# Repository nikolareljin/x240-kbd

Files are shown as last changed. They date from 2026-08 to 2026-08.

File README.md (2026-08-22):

# x240-kbd

A standalone USB keyboard with touchpad **and TrackPoint**, built from a ThinkPad X240
keyboard assembly (FRU 0C44020) and its Synaptics ClickPad, driven by a Raspberry Pi Pico
(RP2040) running QMK.

Works on **any OS without drivers** — it enumerates as a standard USB HID composite device
(keyboard + mouse + media keys).

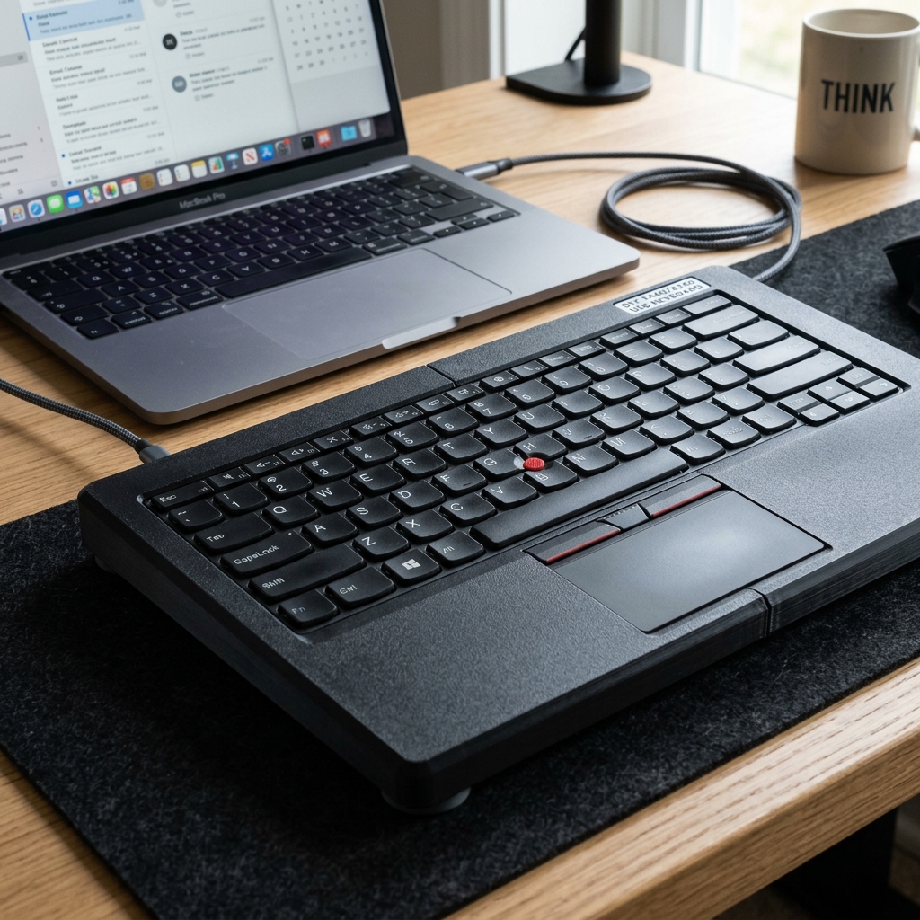
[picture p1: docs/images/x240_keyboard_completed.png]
Standalone X240 Keyboard


> **Project status: design, not yet built.** The matrix pinout is unverified until the
> probing step runs on real hardware, and the TrackPoint route (via the ClickPad's PS/2
> pass-through) is the expected architecture, confirmed by the same step. Everything else
> here is designed to survive either answer. Track progress in the
> [issues](https://github.com/nikolareljin/x240-kbd/issues) — nine milestones from
> documentation to release.

---

## Features

- Full 84-key ThinkPad X240 layout (QWERTY, US)
- Synaptics ClickPad — cursor, left/right click zones
- **TrackPoint** — via the ClickPad's pass-through port, decoded in firmware
- FN layer with the ThinkPad media/system keys; FN Lock (FN + Esc)
- Keyboard backlight, 5 levels (backlit keyboard variants; no breathing — software PWM)
- Power button with a 500 ms long-press guard → OS power/sleep
- Touchpad indicator LED
- N-Key Rollover
- Micro-USB; documented USB-C upgrade
- Two enclosure routes: **3D-printed** (split case) or **hand-made with no printer**
- Two electronics revisions: **Rev A perfboard** and **Rev B KiCad PCB**, same firmware

---

## Hardware at a glance

| Component | Detail |
|---|---|
| Controller | Raspberry Pi Pico, RP2040, 26 GPIO |
| Keyboard | X240 0C44020, 40-pin 0.5 mm FPC; matrix size **measured by probing** |
| Sense expansion | 3 × 74HC165 shift registers — 24 sense lines on 3 GPIO |
| Touchpad + TrackPoint | Synaptics ClickPad, PS/2 on GP21/GP22 (RP2040 PIO driver) |
| Backlight | LED strip via 2N7002/BS170 MOSFET on GP26 |
| Power button | GP27, active LOW |
| USB | Micro-USB; USB-C via the Pico's TP1/TP2/TP3 pads |
| Enclosure | Printed split case, or the original X240 base cover, laser-cut plates, a Hammond console or wood |

Signal flow

Why a shift register: the closest documented ThinkPad keyboard of this era needs 26 matrix
lines — every GPIO the Pico has. [`docs/hardware/gpio-budget.md`](docs/hardware/gpio-budget.md).

### Cost

| Build | All-in (USD, Aug 2026) |
|---|---|
| Rev A + your own printer | **$90–130** |
| Rev A + reused X240 base cover, no printer | **$110–150** |
| Rev B PCB | add $25–35 |

The donor keyboard and palmrest are most of it. Full tiers and part links:
[`docs/hardware/bom-and-cost.md`](docs/hardware/bom-and-cost.md).

---

## Repository structure

```
x240-kbd/
├── firmware/qmk/keyboards/x240_pico/   QMK keyboard definition (corrected in milestone M4)
├── hardware/pinout/                     FPC pin maps — filled by probing
├── hardware/wiring/                     GPIO table (the single authoritative copy) and schematics
├── hardware/pcb/                        Rev B KiCad project (milestone M7)
├── tools/matrix_probe/                  CircuitPython matrix discovery
├── tools/ps2_sniffer/                   CircuitPython PS/2 + Synaptics sniffer
├── cad/                                 OpenSCAD: split case and small printed parts
└── docs/                                The documentation site (GitHub Pages from /docs)
    ├── hardware/                        components, BOM & cost, GPIO budget, sense chain, TrackPoint, backlight, PCB
    ├── firmware/                        architecture, QMK configuration, pointing stack
    ├── enclosure/                       printed, hand-made, integration, durability, presentation
    ├── references.md · glossary.md
    └── images/
```

---

## Quick start

Everything runs through one entry point, `./dev` (verbs from the workspace-wide
[script-helpers](https://github.com/nikolareljin/script-helpers) template; toolchains in
Docker, so the host needs only `docker`, `git` and `python3`):

```bash
./dev install            # submodules, docker images, a shallow qmk_firmware checkout
./dev build [firmware|docs|tools|cad|pcb|all]
./dev test               # host pytest for the tools, link check, shellcheck
./dev preflight          # everything CI runs: test + build all
./dev deploy             # copy the UF2 to the Pico's RPI-RP2 drive  (alias: ./flash)
./dev deploy matrix_probe   # copy a probing tool to CIRCUITPY        (alias: ./probe <tool>)
./dev devices            # RPI-RP2 / CIRCUITPY mounts and serial ports
./dev logs               # qmk console — the firmware's debug output
```

Shims `./build`, `./test`, `./flash`, `./probe`, `./site` wrap the same verbs. Artifacts
land in `out/`. The Docker images and the `qmk_firmware` commit are **pinned by digest**
in `scripts/toolchain.env` (`scripts/pull_toolchain.sh` pulls, saves or refreshes them),
so today's build can be repeated later. CI (`.github/workflows/ci.yml`, via
[ci-helpers](https://github.com/nikolareljin/ci-helpers)) runs `./dev test` and
`./dev build all` on every push and PR.

1. **Read the component reference and buy parts** —
   [`docs/hardware/components.md`](docs/hardware/components.md),
   [`docs/hardware/bom-and-cost.md`](docs/hardware/bom-and-cost.md).
2. **Probe the FPC pinouts — mandatory first step.** Flash CircuitPython, `./probe
   matrix_probe`, then `./probe ps2_sniffer`, following
   [`hardware/pinout/probing_procedure.md`](hardware/pinout/probing_procedure.md). Do not
   wire the Pico to anything before this is done.
3. **Build the Rev A adapter** — [`ASSEMBLY.md`](ASSEMBLY.md) Phase 2, using
   [`hardware/wiring/wiring_diagram.md`](hardware/wiring/wiring_diagram.md).
4. **Build and flash firmware** — `./dev build` then `./dev deploy` (hold BOOTSEL while
   plugging in). Without `./dev`: copy `firmware/qmk/keyboards/x240_pico` into a QMK
   checkout and `qmk compile -kb x240_pico -km default`. The firmware **builds** (custom
   74HC165 matrix, PIO PS/2 host, Synaptics + TrackPoint decoding); the key map is a
   placeholder until probing (#38). [`docs/firmware/qmk-configuration.md`](docs/firmware/qmk-configuration.md).
5. **Choose an enclosure** — printed:
   [`docs/enclosure/printed.md`](docs/enclosure/printed.md); no printer:
   [`docs/enclosure/handmade.md`](docs/enclosure/handmade.md).
6. **Close it up** — [`docs/enclosure/presentation.md`](docs/enclosure/presentation.md)
   has the assembly order.

---

## FN key map

| FN + | Action | | FN + | Action |
|---|---|---|---|---|
| F1 | Mute | | F9 | Settings |
| F2 | Volume down | | F10 | Bluetooth |
| F3 | Volume up | | F11 | **Backlight step** |
| F4 | Mic mute (F20) | | F12 | Print Screen |
| F5 | Brightness down | | PgUp / PgDn | Home / End |
| F6 | Brightness up | | Left / Right | Previous / next track |
| F7 | External display | | Esc | **FN Lock** |
| F8 | Wireless toggle | | | |

---

## USB-C upgrade (optional)

Wire a USB-C female breakout (one with 5.1 kΩ CC pull-downs) to the pads on the Pico's
underside:

| Pico pad | Signal | Breakout |
|---|---|---|
| **TP1** | **GND** | GND |
| **TP2** | **USB D−** | D− |
| **TP3** | **USB D+** | D+ |
| VBUS (pin 40) | 5 V | VBUS |

Set `usb_c = true` in `cad/bottom_case.scad` for the USB-C cutout. No firmware change.

USB-C breakout to Pico test pads

> The illustration [`docs/images/usb_c_wiring.png`](docs/images/usb_c_wiring.png) is
> decorative; its pad labels predate this table and are **not** the wiring reference.
> Source: [Pico datasheet, test points](https://datasheets.raspberrypi.com/pico/pico-datasheet.pdf).

Alternatively use a **Pimoroni Pico LiPo** (USB-C native, same pinout).

---

## Flashing

- **First flash:** hold BOOTSEL while plugging in → `RPI-RP2` drive → drag the `.uf2`.
- **After that:** `./dev deploy`, or hold the top-left key (Esc) while plugging in (Bootmagic).
- **Recommended:** wire a tactile switch to the Pico's `RUN` pad, reachable through the
  case, so BOOTSEL + reset works without opening anything.

---

## Documentation

The site is built from `docs/` (GitHub Pages, milestone M1). Start at
[`docs/README.md`](docs/README.md). Builder guides: [`ASSEMBLY.md`](ASSEMBLY.md),
[`PLAN.md`](PLAN.md). Changes: [`CHANGELOG.md`](CHANGELOG.md).

## References

Annotated list in [`docs/references.md`](docs/references.md). The projects this one stands
on: [delingren/thinkpad_keyboards](https://github.com/delingren/thinkpad_keyboards),
[hamishcoleman/thinkpad-usbkb](https://github.com/hamishcoleman/thinkpad-usbkb),
[thedalles77/USB_Laptop_Keyboard_Controller](https://github.com/thedalles77/USB_Laptop_Keyboard_Controller).

## Repository

[nikolareljin/x240-kbd](https://github.com/nikolareljin/x240-kbd) · GPL-2.0, matching QMK.

## Clone traffic

Clone traffic

_Updated daily. Total and unique cloners over the last 14 days._

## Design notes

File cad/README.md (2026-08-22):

# Printed parts

Parametric OpenSCAD. Every dimension lives in [`params.scad`](params.scad); part files
only include it. Values marked `MEASURE` there are targets until a real X240 deck is
measured (issue #44).

| Part | File | Variants | Qty |
|---|---|---|---|
| Bottom case, split | `bottom_case.scad` | `half="left"`, `"right"`, `"both"` | 1 + 1 |
| Perfboard / PCB sled | `perfboard_sled.scad` | | 1 |
| USB strain relief (two clamp halves) | `usb_strain_relief.scad` | | 1 set |
| Tilt feet (pair) | `tilt_feet.scad` | | 1 set |
| ZIF support block | `zif_support_block.scad` | `variant="keyboard"`, `"clickpad"` | 1 each |
| LED light pipe | `led_light_pipe.scad` | | 1 |
| Pico mount bracket (Rev A) | `pico_mount_bracket.scad` | | 1 |
| FPC cable guide | `fpc_cable_guide.scad` | `cable="keyboard"`, `"clickpad"` | 2 + 1 |
| **Laser-cut plates + box insert (2D → DXF)** | `export_plates.scad` | `plate="bottom"`, `"spacer"`, `"insert"`, `"sheet"` | see [`../docs/enclosure/handmade.md`](../docs/enclosure/handmade.md) |

Render everything: `./dev build cad` → `out/cad/*.stl` and `*.dxf` (OpenSCAD in Docker; no
install needed). The DXFs come from `projection()` of the same solids, so the hand-made
route cannot drift from the printed one. Single part by hand: `openscad -D 'half="right"' -o right.stl bottom_case.scad`.

Settings, tolerances, joint design and assembly order:
[`../docs/enclosure/printed.md`](../docs/enclosure/printed.md). Meshes are never committed
(`out/` and `cad/exports/` are ignored).

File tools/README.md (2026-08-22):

# Probing and bring-up tools

CircuitPython scripts that run on the Raspberry Pi Pico **before** QMK is flashed. Each is
standalone: `./probe <tool>` copies it to the `CIRCUITPY` drive as `code.py` (or do it by
hand), open a serial terminal at 115200 baud, and edit the constants at the top of the
file to match your wiring.

| Tool | Milestone step | Edit first |
|---|---|---|
| [`matrix_probe/matrix_probe.py`](matrix_probe/matrix_probe.py) | Keyboard FPC: which pads are drive, which are sense, per key | `PASS` (`"A"` pads 1–26, `"B"` pads 15–40), `NEVER_DRIVE_PADS` once VCC/GND/backlight are known |
| [`ps2_sniffer/ps2_sniffer.py`](ps2_sniffer/ps2_sniffer.py) | ClickPad FPC: find CLK/DATA, then the **TrackPoint verdict** | `MODE` (`"find"` → `"synaptics"`), `CANDIDATE_PAIRS`, then `CLK_PIN`/`DATA_PIN` |
| [`shift_register_test/shift_register_test.py`](shift_register_test/shift_register_test.py) | Verify the 74HC165 chain with nothing else connected | `MODE` (`"watch"` or `"walk"`) |

Order of use: `shift_register_test` (walk mode, on the bare adapter) → `matrix_probe`
pass A → pass B → `ps2_sniffer` find → `ps2_sniffer` synaptics. Results go into
[`../hardware/pinout/`](../hardware/pinout/).

Full procedure: [`../hardware/pinout/probing_procedure.md`](../hardware/pinout/probing_procedure.md).

## Host-side tests

The protocol and table-formatting logic in each script is plain Python with no hardware
imports, so it is unit-tested on a PC:

```bash
./dev test            # or: cd tools/tests && python3 -m pytest -q
```

Covers the two-pass pad maps and result merging, PS/2 parity and packet decoding, the
Synaptics special-command encoding, 6-byte absolute packets including `W == 3` guest
frames, the capability bits, the verdict text, and the 74HC165 bit-to-sense-line mapping.
The hardware sections are skipped on the host (`ON_DEVICE` is `False`).

## Timing caveat

CircuitPython bit-bangs at tens of microseconds per GPIO operation; PS/2 clocks at
10–16 kHz. Reads are marginal and framing errors are normal — the scripts resync and
only need a handful of good bytes. If nothing decodes, put a logic analyser on the
candidate pins first ([`../docs/hardware/components.md`](../docs/hardware/components.md)).

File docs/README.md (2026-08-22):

---
title: Documentation index
nav_exclude: true
---

# x240-kbd documentation

Builder-facing pages are grouped by subject; maintainer rules are at the bottom. The same
files are served as the GitHub Pages site (milestone M1).

## Hardware

- [`hardware/components.md`](hardware/components.md) — every part with datasheet and product links
- [`hardware/bom-and-cost.md`](hardware/bom-and-cost.md) — tiered BOM and all-in cost
- [`hardware/gpio-budget.md`](hardware/gpio-budget.md) — why a Pico needs a shift register here
- [`hardware/shift-register-matrix.md`](hardware/shift-register-matrix.md) — the 74HC165 sense chain
- [`hardware/trackpoint.md`](hardware/trackpoint.md) — TrackPoint via Synaptics pass-through
- [`hardware/backlight.md`](hardware/backlight.md) — MOSFET circuit and the RP2040 driver choice
- [`hardware/pcb.md`](hardware/pcb.md) — Rev A perfboard vs Rev B PCB

## Firmware

- [`firmware/architecture.md`](firmware/architecture.md) — file map and data paths
- [`firmware/qmk-configuration.md`](firmware/qmk-configuration.md) — every flag, with corrections
- [`firmware/pointing-stack.md`](firmware/pointing-stack.md) — ClickPad + TrackPoint decoding

## Enclosure

- [`enclosure/printed.md`](enclosure/printed.md) — split case and the small printed parts
- [`enclosure/handmade.md`](enclosure/handmade.md) — no printer: base cover, laser-cut, console, wood
- [`enclosure/integration.md`](enclosure/integration.md) — stack heights, routing, screws
- [`enclosure/durability.md`](enclosure/durability.md) — heat, EMI, FPC fatigue, stiffness
- [`enclosure/presentation.md`](enclosure/presentation.md) — assembly order, box, label, card

## Reference

- [`references.md`](references.md) — annotated sources
- [`glossary.md`](glossary.md)

## Maintainer rules (not published on the site)

- [`project-structure.md`](project-structure.md) — where things live
- [`design-instructions.md`](design-instructions.md) — design contract
- [`code-instructions.md`](code-instructions.md) — coding standards
- [`build-and-test.md`](build-and-test.md) — workflow from raw hardware to verified device

## Source of truth

1. Measured data in `hardware/pinout/*.md`
2. The GPIO table in `hardware/wiring/wiring_diagram.md`
3. QMK source under `firmware/`
4. `ASSEMBLY.md`, then `PLAN.md`

If documents disagree, the earlier item wins and the later one has a bug.

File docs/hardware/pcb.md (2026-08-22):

---
title: PCB (Rev B)
parent: Hardware
nav_order: 7
---

# Rev A and Rev B

| | Rev A — perfboard | Rev B — PCB |
|---|---|---|
| Carrier | Stripboard ≈100 × 80 mm, 30 AWG wire | 2-layer KiCad board, same outline |
| FPC sockets | Off-the-shelf ZIF breakouts soldered to the stripboard | Hirose FH12 directly on the board |
| Shift registers | DIP-16 in sockets | SSOP/TSSOP |
| Pull-ups | 9-pin SIP networks | 4 × 0603 arrays |
| Pico | Socketed on 2 × 20 female headers | Same — socketed, replaceable |
| Mounting | M2 holes drilled to match the sled | M2 holes on the **same pattern**, plus holes matching the X240 base-cover standoffs |
| Firmware | identical | identical |
| GPIO map | identical | identical |

Rev B is a **drop-in**: same connector positions, same holes, same firmware. A Rev A build
can be upgraded by swapping the board. That constraint is deliberate — it keeps one set of
docs, one enclosure design and one firmware.

## Rev B is jumpered, not hard-routed — and why

Which of the keyboard FPC's 40 lines are drive, sense, VCC, GND, backlight and power
button is unknown until probing (#28); the ClickPad's pin count until #29. A board that
hard-routes FPC pins to GPIO before that would be wrong on arrival. So **Rev B** gets the
parts that are certain — the ZIF connectors, the 74HC165 chain with its pull-up arrays,
the PS/2 pull-ups, the backlight MOSFET, decoupling, the Pico socket — and brings the
unknowns to headers that sit side by side:

| Header | Carries | Jumper to |
|---|---|---|
| `J_KB` 2 × 20 | keyboard FPC lines 1–40, one per pin | `J_MAT` |
| `J_MAT` 2 × 17 | DRV0–9 (GP0–GP9), SENSE0–19 (chain inputs), BL−, BL+, PWR_BTN, GND | `J_KB` |
| `J_TP` 1 × 12 | ClickPad FPC lines 1–12 | `J_PS2` |
| `J_PS2` 1 × 8 | 3V3, GND, PS2_DATA (GP21, pulled up), PS2_CLK (GP22), fallback DATA/CLK (GP19/20, DNP pull-ups), LED_A, GND | `J_TP` |

After probing, ~30 short jumper wires (or a tiny "personality" board plugged across both
headers) make the assignment. Sense lines 20–23 are pulled up but not headered in this
revision: the documented ThinkPad matrices need ≤ 20 sense lines, and `J_MAT` is already
34 pins. A Rev C hard-routes the measured map and deletes the headers.

## Rev B schematic blocks

1. **Pico module** — 2 × 20 header footprint, USB at the rear edge, `RUN` broken out to a
   tactile reset button, `TP1/TP2/TP3` broken out to a 4-pin USB-C header.
2. **Keyboard FPC** — `FH12-40S-0.5SH(55)`, bottom contact, on the edge facing the deck.
   All 40 lines go to `J_KB`; every pin is probeable there after assembly.
3. **Sense chain** — 3 × 74HC165, `PL`/`CP` bussed, `Q7 → DS` cascade, 100 nF each, three
   4 × 10 kΩ arrays per chip (12 elements per chip; 8 used, spares tied off).
4. **ClickPad FPC** — `FH12-12S-0.5SH(55)` as the placeholder (a 12-pin socket accepts
   narrower cables if you align pin 1; confirm after #29). All lines go to `J_TP`.
5. **PS/2** — 4.7 kΩ pull-ups on DATA (GP21) and CLK (GP22). Second pair on GP19/GP20 with
   unpopulated pull-ups, for the TrackPoint fallback.
6. **Backlight** — 2N7002, 10 kΩ gate, 100 kΩ pull-down, series resistor footprint, jumper
   selecting 3V3 or VBUS for the anode.
7. **Power button / LED** — GP27 with ESD-friendly 100 Ω series; GP28 → 100 Ω → LED header.
8. **Decoupling and bulk** — 10 µF near the Pico's 3V3 pin, 100 nF per IC.

## Rules and what the generated board is

- 2-layer, 100 × 80 mm. Netclass targets 0.20 mm track / 0.15 mm clearance, vias
  0.6 / 0.3 mm; board minimums 0.127 mm (JLCPCB/PCBWay 2-layer capability). The router is
  given that room deliberately — at 0.25 / 0.18 it left FPC lines unrouted.
- Freerouting routes **all 202 connections** (0 unrouted) in about three minutes at 100
  passes. The back-side GND pour is added afterwards with island removal on, so it only
  adds copper; every connection is the router's.
- `kicad-cli pcb drc` on the routed board: no errors, no unconnected items. The only
  warnings are a few dangling vias — router GND vias whose pour-side copper was removed as
  an island; harmless, and a later revision can delete them.
- Mounting: four M2 holes on the sled pattern (4 mm in from each corner) and three M2.5
  holes for the X240 base-cover standoffs at **placeholder** positions (`MEASURE` — issue
  #44 fixes them).

## Ordering

- **JLCPCB / PCBWay**: 2-layer, 1.6 mm FR-4, HASL or ENIG (ENIG recommended for the 0.5 mm
  FPC pads), 5 boards ≈ $2 plus shipping. Allow 1–2 weeks.
- Order the Hirose connectors and the SMD parts from **DigiKey/Mouser** or, cheaper, from
  **LCSC** in the same basket as a JLCPCB order.
- `out/pcb/bom.csv` (from `kicad-cli sch export bom`, grouped by value and footprint) is
  the parts list to order from; add LCSC/DigiKey numbers in the basket. An interactive
  HTML BOM is not produced — InteractiveHtmlBom is not in the pinned KiCad image.

## How the files are made

The board is **generated**, not drawn: `hardware/pcb/netlist_model.py` holds the parts,
library names and nets; `gen_schematic.py` writes the `.kicad_sch` and `gen_pcb.py` the
`.kicad_pcb` from it, so the two cannot disagree. Routing is done by freerouting from a
Specctra DSN exported by KiCad's Python API, then imported back; DRC, PDF, gerbers and
drill files come from `kicad-cli`. All of that runs in the pinned `kicad/kicad` and
`freerouting` images via `./dev build pcb`. Edit the model, not the KiCad files.

## Deliverables of milestone M7

- `hardware/pcb/x240_pico_rev_b.kicad_pro` + schematic + PCB (generated, committed)
- `out/pcb/schematic.pdf`, `board.pdf`, `gerbers.zip` + drill, position file, `bom.csv`
- This page updated with the real ordering parameters and a bring-up log.

Assembly with a soldering iron is realistic: the hardest parts are the FH12 connectors
(0.5 mm pitch — flux, drag-solder, magnification) and the SSOP shift registers. Everything
else is 0603 or larger.

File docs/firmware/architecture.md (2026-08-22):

---
title: Architecture
parent: Firmware
nav_order: 1
---

# Firmware architecture

QMK keyboard definition under `firmware/qmk/keyboards/x240_pico/`, built by copying it
into a QMK checkout. Files marked **new** are created in milestone M4; the rest exist today
and are corrected there.

| File | Owns | Status |
|---|---|---|
| `keyboard.json` | USB IDs, `processor`/`bootloader`, feature flags, the `ps2` block, layout metadata. `matrix_pins` is **removed** — the custom matrix owns pins. | exists, corrected in M4 |
| `config.h` | Sense chain (`SENSE_PL_PIN`, `SENSE_CHAIN_BYTES`, `SENSE_SPI_DIVISOR`), SPI0 pins (`SPI_DRIVER`, `SPI_SCK_PIN`, `SPI_MISO_PIN`, `SPI_MOSI_PIN`), `MATRIX_DRIVE_PINS`, debounce, backlight, power button, LED, `SYN_*` tuning | exists, corrected in M4 |
| `rules.mk` | `CUSTOM_MATRIX = lite`, `POINTING_DEVICE_DRIVER = custom`, `PS2_ENABLE = yes` + `PS2_DRIVER = vendor`, `PS2_MOUSE_ENABLE = no`, `BACKLIGHT_DRIVER = software`, `SRC += matrix.c synaptics.c trackpoint.c` | corrected in M4 |
| `halconf.h` / `mcuconf.h` | `HAL_USE_SPI`, `RP_SPI_USE_SPI0` — ChibiOS needs SPI0 switched on for the sense chain | **new** |
| `matrix.c` | Drive-line sequencing and the 74HC165 chain read | **new** |
| `synaptics.c` / `.h` | The custom pointing-device driver: ClickPad reset/identify/capabilities, mode byte, guest enable, 6-byte packet parser with resync, touchpad delta, logged relative-mode fallback | **new** |
| `trackpoint.c` / `.h` | Guest (pass-through) frame decode, TrackPoint delta and scaling | **new** |
| `x240_pico.c` | `keyboard_post_init_kb` (LED on, power-button pull-up), `matrix_scan_kb` (power-button long-press guard), `pointing_device_task_kb` (pass-through; merge happens in `synaptics.c`) | exists |
| `x240_pico.h` | `LAYOUT` macro, custom keycodes `CK_BKLT`/`CK_FNLK`, layer enum | exists; `LAYOUT` regenerated from the measured matrix |
| `keymaps/default/keymap.c` | `_BASE` and `_FN` layers, `process_record_user` | exists; regenerated from the measured matrix |

Signal flow

## From a key press to a USB report

```
GP0..GP9 drive line LOW
   → membrane closes a sense line to it
      → 74HC165 latches 24 sense bits (PL)
         → SPI0 clocks them into GP16          matrix.c : matrix_scan_custom()
            → raw row bitmap
               → QMK debounce (DEBOUNCE 5 ms)   quantum/
                  → keymap lookup, layers        keymap.c
                     → NKRO / boot keyboard report over USB (TinyUSB)
```

## From the ClickPad to a USB mouse report

```
ClickPad + TrackPoint guest  ──PS/2──►  GP21 DATA / GP22 CLK
   → QMK vendor PS/2 driver (RP2040 PIO0)         platforms/chibios/drivers/vendor/RP/RP2040/ps2_vendor.c
      → pbuf_has_data() / ps2_host_recv() bytes
         → synaptics.c (custom pointing driver) assembles 6-byte packets
            ├─ W != 3 : touchpad frame  → finger delta, L/R from byte 0    synaptics.c
            └─ W == 3 : guest frame     → TrackPoint 3-byte packet          trackpoint.c
               → both add into one report_mouse_t inside                    synaptics.c
                 pointing_device_driver_get_report()
                  → pointing_device_task_kb() passes it through              x240_pico.c
                  → USB HID mouse report
```

If the Synaptics identify fails, `synaptics.c` falls back to plain relative mode and logs
once via `dprintf` — the touchpad still works, the TrackPoint does not, and the log says so.
Never a silent success.

## Hooks used and why

| Hook | Used for | Not used for |
|---|---|---|
| `matrix_init_custom` / `matrix_scan_custom` | the chain | anything else — keep the scan loop minimal |
| `keyboard_post_init_kb` | LED and power-button GPIO setup | keymap logic |
| `pointing_device_driver_init` | Synaptics init; failures logged on the console | matrix |
| `matrix_scan_kb` | power-button timing only | side effects on the matrix |
| `pointing_device_task_kb` | pass-through only (merge and Y inversion happen in the driver) | pointing logic |
| `process_record_user` | `CK_BKLT`, `CK_FNLK` | hardware polling |

## Build

```bash
cp -r firmware/qmk/keyboards/x240_pico ~/qmk_firmware/keyboards/x240_pico
qmk compile -kb x240_pico -km default
qmk flash   -kb x240_pico -km default     # hold BOOTSEL, or Bootmagic top-left key
```

Local build without installing a toolchain: the `qmkfm/qmk_cli` docker image plus a
`qmk_firmware` checkout, with this directory mounted at `keyboards/x240_pico`. The
placeholder `LAYOUT` still describes the old 8 × 13 arrangement inside the 10 × 24 matrix;
issue #38 regenerates it from the measured pinout.

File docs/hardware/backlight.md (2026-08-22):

---
title: Backlight
parent: Hardware
nav_order: 6
---

# Keyboard backlight

Only the backlit keyboard variants (`04X0177`, `0C43982`) have an LED strip. The
non-backlit `0C44020` has none — on that keyboard the circuit below is simply left
unpopulated and `BACKLIGHT_ENABLE = no`.

## Circuit

Backlight MOSFET switch

A low-side N-MOSFET switch on GP26. The Pico cannot source the strip's current directly
(GPIO limit ~12 mA; the strip is ~100 mA on comparable ThinkPad arrays).

```
3V3 ──── R_series ──── LED strip anode (+)
                        LED strip cathode (−) ──── Drain
                                                   Source ──── GND
GP26 ──── 10 kΩ ──── Gate
                     Gate ──── 100 kΩ ──── GND
```

| Part | Value | Why |
|---|---|---|
| Q1 | 2N7002 (SOT-23) or BS170 (TO-92) | Logic-level V<sub>GS(th)</sub>, turns on fully at 3.3 V |
| R<sub>gate</sub> | 10 kΩ | Limits the gate-charge current spike on each PWM edge |
| R<sub>pd</sub> | 100 kΩ gate → GND | Holds the gate LOW while the Pico boots and GP26 is high-Z: **the backlight does not flash at power-on** |
| R<sub>series</sub> | 100 Ω to start — **set by measurement** | The strip has its own internal resistors on most ThinkPads; measure before trusting any value |
| Supply | 3V3 from the Pico | If the strip is dim at 3.3 V, move the anode to VBUS (5 V) and re-measure current |

## Measure before you trust it

1. Identify the backlight anode/cathode pins on the keyboard FPC (Phase 1).
2. With the MOSFET **not** fitted, put a multimeter in series and apply 3.3 V through 100 Ω.
3. Note the current. Expect tens of mA; delingren measured ~5.6 mA per LED × 18 LEDs ≈
   100 mA on a 04Y0819 with no series resistor.
4. If it is under ~20 mA and visibly dim, reduce R<sub>series</sub> or move to 5 V.
   If it is over ~150 mA, raise R<sub>series</sub>. The USB budget is 500 mA total; keep
   the backlight under a third of that.
5. Record the final values in this file.

## QMK driver selection

This is where the earlier plan was wrong.

| Driver | What it is | RP2040? |
|---|---|---|
| `pwm` | Hardware PWM via ChibiOS `PWMD` | **Fails to compile on RP2040** — [QMK #24470](https://github.com/qmk/qmk_firmware/issues/24470): `unknown type name 'PWMConfig'`, undeclared `PWMD4` |
| `timer` | Interrupt-driven pin toggling | Documented for **AVR and STM32**; not the RP2040 workaround |
| `software` | PWM emulated in the main loop | **Works on RP2040** — the workaround recorded in #24470 |
| `custom` | You write it | Unnecessary here |

So: `BACKLIGHT_DRIVER = software`. The cost is some flicker sensitivity if the scan loop
stalls; at our ~350 µs scan this is invisible. If a later QMK release fixes RP2040 `pwm`,
switch and record it in `CHANGELOG.md`.

Reference: [QMK backlight docs](https://docs.qmk.fm/features/backlight).

## Configuration

```c
/* config.h */
#define BACKLIGHT_PIN     GP26
#define BACKLIGHT_LEVELS  5
/* no BACKLIGHT_BREATHING — unsupported by the software driver */
```

```make
# rules.mk
BACKLIGHT_ENABLE = yes
BACKLIGHT_DRIVER = software
```

FN + F11 (`CK_BKLT`) steps through the five levels. **No breathing**: `backlight_software.c`
refuses `BACKLIGHT_BREATHING` at compile time, so it is not defined.

## Troubleshooting

| Symptom | Cause |
|---|---|
| Always off | Gate/drain/source mixed up (TO-92 pinout varies by manufacturer — check the datasheet, not the package shape) |
| Always on, even before firmware | Missing 100 kΩ pull-down |
| On but no dimming | Driver is not `software`, or `BACKLIGHT_LEVELS` is 1 |
| Dim | R<sub>series</sub> too high for 3.3 V — measure, then consider 5 V |

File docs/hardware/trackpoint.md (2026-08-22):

---
title: TrackPoint
parent: Hardware
nav_order: 5
---

# TrackPoint architecture

The X240 keyboard has a TrackPoint. Earlier revisions of this project did not mention it.
It is a first-class feature: the finished keyboard must move the cursor from the stick and
click from the ClickPad's button zones.

## How the X240 routes the TrackPoint

PS/2 bus with TrackPoint pass-through

In this generation of ThinkPads the TrackPoint does **not** have its own line to the host.
The stick's strain-gauge board feeds a controller (TPM754-class) that speaks PS/2, and that
PS/2 stream goes into the **Synaptics ClickPad's guest port**. The ClickPad forwards the
guest's packets to the host inside its own packet stream. Linux shows this as
`serio: Synaptics pass-through port` at boot.

```
TrackPoint strain gauges
   → TrackPoint controller  (PS/2 out, inside the keyboard)
      → ClickPad Synaptics guest port  (inside the palmrest)
         → ONE PS/2 bus  →  Pico GP21 (DATA) / GP22 (CLK)
```

Consequence: **no extra wires or pins**. The Pico sees one PS/2 device. Everything else is
firmware.

This is the *expected* chain. It is confirmed by the M2 ClickPad probing step — the extended
sniffer reports whether pass-through frames appear when the stick is pushed. Do not wire
for the fallback until that measurement says so.

## What QMK does and does not do

QMK's `ps2_mouse` feature speaks **plain PS/2 relative mode**: 3-byte packets, X/Y deltas,
three buttons. In that mode a Synaptics ClickPad behaves like an ordinary PS/2 mouse and
**silently drops** the guest stream — the TrackPoint is dead.

So the firmware does not use `ps2_mouse` at all. It keeps QMK's RP2040 PIO PS/2 *host*
(`PS2_ENABLE = yes`, `PS2_DRIVER = vendor`) and implements the pointing device itself
(`POINTING_DEVICE_DRIVER = custom`): put the ClickPad into Synaptics **absolute mode with
pass-through enabled**, then decode the 6-byte packets. That is `synaptics.c` /
`trackpoint.c` — [`../firmware/pointing-stack.md`](../firmware/pointing-stack.md).

## The Synaptics protocol, briefly

Spec: Synaptics *TouchPad Interfacing Guide* (PN 511-000275; no longer hosted publicly — the working reference is the Linux driver [`drivers/input/mouse/synaptics.c`](https://github.com/torvalds/linux/blob/master/drivers/input/mouse/synaptics.c)).
The Linux `psmouse` driver (`drivers/input/mouse/synaptics.c`) is the working reference
implementation.

**Identify ("magic knock").** Send `SetResolution` four times with the value encoding a
query number, then `StatusRequest` (`0xE9`); the three status bytes carry the answer. Query
`0x00` returns identification — byte 1 must be `0x47` for a Synaptics device.

**Mode byte.** Written with the same knock followed by `SetSampleRate 0x14`. Bits we set:
`Absolute` (bit 7), `Rate 80` (bit 6), `W-mode` (bit 0). Pass-through is enabled per the
guide's "extended capabilities" sequence when capability bit `PassThrough` is present.

**Absolute packet (6 bytes).**

```
byte 0: 1 0 W3 W2 0 W1 R L
byte 1: Y11 Y10 Y9 Y8 X11 X10 X9 X8
byte 2: Z7..Z0
byte 3: 1 1 Y12 X12 0 W0 R' L'
byte 4: X7..X0
byte 5: Y7..Y0
```

`W` (four bits) is the finger-width / packet-type field. **`W == 3` means this packet is a
pass-through frame**: bytes 1, 4 and 5 hold the guest device's standard 3-byte PS/2 packet
(buttons/sign byte, X delta, Y delta). Everything else is touchpad data.

So the decoder is one `switch` on `W`: guest frame → TrackPoint path; anything else →
touchpad path.

## Fallback: a standalone TrackPoint line

If the sniffer never sees `W == 3` frames with the stick deflected, the TrackPoint is not on
the ClickPad's guest port on this unit. Then:

- Find the TrackPoint controller's own CLK/DATA on the keyboard FPC (it will be two of the
  non-matrix pins), with 4.7 kΩ pull-ups.
- Wire them to the reserved pair **GP19 (DATA) / GP20 (CLK)**.
- Run a second PS/2 instance on PIO1 (`#define PS2_PIO_USE_PIO1`) — QMK's vendor driver
  uses PIO0 by default.
- A standalone controller may need its **reset pin pulsed high at boot**; delingren found a
  04Y0819 module failed ~90 % of the time without it. Probe for a reset line if the module
  is unreliable.

This path costs 2 GPIO and a second driver instance. It is documented so that the pins are
already reserved; it is not built until a measurement demands it.

## Buttons

The X240 ClickPad has no separate physical buttons; its top edge is a button zone for the
TrackPoint and its bottom corners are the touchpad's click zones. Those clicks arrive in the
**touchpad** packet's L/R bits, not in the guest frame. The firmware merges them: a click
while the last motion came from the stick is a TrackPoint click in practice, and the user
will not notice the distinction.

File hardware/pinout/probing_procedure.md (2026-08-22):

# FPC Pinout Probing Procedure

This document explains how to discover the exact function of every pin on the X240
keyboard and touchpad FPC cables before wiring them to the Pico.

---

## Equipment

- Raspberry Pi Pico (flashed with CircuitPython) — the *same* Pico is reused for the build
- 40-pin 0.5 mm FPC-to-DIP breakout **with a ZIF connector** (see `docs/hardware/components.md`; Adafruit #1436 is a bare solder-pad plate, not a ZIF breakout)
- 6–12 pin 0.5 mm ZIF FPC breakout board (for touchpad)
- Multimeter (continuity + DC voltage modes)
- Logic analyser (cheap 8-channel USB type works fine) — for touchpad PS/2 sniffing
- Serial terminal (Thonny IDE, PuTTY, or screen — 115200 baud)
- `tools/matrix_probe/matrix_probe.py` (copy to Pico as `code.py`)
- `tools/ps2_sniffer/ps2_sniffer.py` (copy to Pico as `code.py` for touchpad phase)

---

## Part A — Keyboard Matrix

### A1. Insert FPC cable

FPC orientation and pin 1

1. Lift the ZIF locking lever on the breakout board.
2. Slide the keyboard FPC ribbon into the connector.
   - Most FPC breakouts require the contact pads (shiny metal) to face down.
   - Check your specific breakout board's silkscreen or datasheet.
3. Close the locking lever firmly.

### A2. Flash CircuitPython and run matrix_probe

1. Hold BOOTSEL while plugging Pico into USB → appears as `RPI-RP2`.
2. Drag the CircuitPython `.uf2` from circuitpython.org onto the drive.
3. Pico reboots as `CIRCUITPY`.
4. Copy `tools/matrix_probe/matrix_probe.py` onto `CIRCUITPY`, rename to `code.py`.
5. Open a serial terminal at 115200 baud (Thonny serial console works well).

The 40-pad breakout has more pads than the Pico has GPIO (26). The script runs in
**two passes**: wire pads 1–26 for pass A, then pads 15–40 for pass B (the overlap ties the
two maps together). Set `PASS = "A"` or `"B"` at the top of the script; `GPIO_ORDER` lists
the 26 GPIO in the order they are wired to the pads. As soon as a pad is known to be VCC,
GND or backlight, add it to `NEVER_DRIVE_PADS` so it is never pulled LOW.

The script will:
- Iterate through the wired pads
- Drive each pin LOW while configuring all other pins as inputs with pull-ups
- Display: `Press a key... ` and wait
- When you press a key, it prints the drive pad and the sense pad that closed together
- At the end it prints a Markdown table (key, drive pad, sense pad, pass) — paste it into
  `x240_keyboard_fpc_pinout.md` — and a drive/sense summary

Work through every key on the keyboard. Keys that share a row will produce the same
first pin number; keys in the same column share the second pin number.

### A3. Build the drive/sense map

After scanning all keys, group the results:

- **Drive lines**: the set of pads that appear as the "driven" pad across multiple keys
- **Sense lines**: the remaining active pads

Count them. The smaller set goes to GP0–GP9 as drive lines; the larger set goes to the
74HC165 chain as sense lines. If both are ≤ 10 you could skip the chain — but keep it; it
is what makes the design survive a transposed or larger-than-expected matrix.

### A3b. Ghosting test

Hold A + S + D. If a fourth key appears, the membrane has no diodes and every sense line
needs a 1N4148 at the breakout. Most ThinkPad membranes have them.

Write the verified map into `hardware/pinout/x240_keyboard_fpc_pinout.md`.

### A4. Identify power, GND, backlight, power button

After the matrix sweep, find pins that produced no matrix activity:

**GND**: set multimeter to continuity mode. The FPC cable's metallic shield/foil
is GND. Touch one probe to it and sweep the other across all breakout pads. All GND
pins beep.

**VCC**: supply 3.3 V from the Pico's 3V3 pin through a 100 Ω safety resistor to each
candidate pin one at a time. Measure voltage on the same pin — it reads 3.3 V when
found. (Most X240 keyboards run at 3.3 V; verify before connecting directly.)

**Backlight**: with VCC and GND identified, try each remaining unidentified pair as a
potential LED+/LED- pair. Apply 3.3 V through a 100 Ω resistor across the pair. The
keyboard backlight strip will faintly glow. Note: the backlight on the non-backlit
variant (0C44020) is absent — these pins may be no-connect.

**Power button**: probe remaining pins for near-zero resistance when the power button
is physically pressed (multimeter continuity mode).

---

### A5. TrackPoint lines (only if Part B shows a standalone TrackPoint)

If Part B finds no pass-through frames, two of the remaining keyboard FPC pins are the
TrackPoint controller's CLK and DATA (and possibly a reset). Find them as in B3, with
4.7 kΩ pull-ups, using the sniffer in plain PS/2 mode while pushing the stick.

## Part B — Touchpad FPC

### B1. Insert touchpad FPC

Insert the touchpad's FPC cable into the small breakout board the same way as above.

### B2. Identify VCC and GND

- GND: continuity to the touchpad PCB chassis/shield
- VCC: try 3.3 V (via 100 Ω safety resistor) on each candidate pin; the Synaptics
  controller will draw ~10–15 mA when correctly powered. You can confirm by measuring
  current with the multimeter in series.

### B3. Identify PS/2 CLK and DATA

1. Flash Pico with `tools/ps2_sniffer/ps2_sniffer.py` (as `code.py`), `MODE = "find"`.
2. Edit `CANDIDATE_PAIRS` — the `(clk, data)` GPIO pairs to try.
3. Power the touchpad (VCC + GND from Pico).
4. Move your finger on the touchpad surface.
5. The serial console should show decoded PS/2 movement packets when CLK/DATA are
   correctly identified. The CLK line toggles at ~10–16 kHz; a logic analyser makes
   it easy to spot visually even before decoding.
6. If no output: swap the candidate pins for CLK and DATA and retry.
7. For the build, DATA goes to **GP21** and CLK to **GP22** — the RP2040 PIO driver needs
   clock = data + 1.

### B3b. Confirm the TrackPoint route

Set `MODE = "synaptics"` and `CLK_PIN`/`DATA_PIN` to the pair just found. The script
resets the ClickPad, runs the Synaptics identify sequence, prints the capability bits,
enables absolute + W mode, enables the guest, and streams for `VERDICT_SECONDS`. Push the
stick with no finger on the pad. It ends with a `VERDICT:` line:

- Packets with `W == 3` ⇒ the TrackPoint rides this bus. **Done — no extra wiring.**
- No such packets ⇒ go to A5 and wire the TrackPoint's own line to GP20/GP19.

Record the result in `x240_clickpad_fpc_pinout.md`. This single observation decides the
firmware path; do not skip it.

### B4. Identify LED pins

The touchpad indicator LED (if present) appears as a ~2 V forward-voltage drop
across a pair of pins. Measure with multimeter in diode mode across candidate pins.
The pair that reads ~1.8–2.2 V (forward drop) is the LED anode (+) and cathode (−).

---

## Recording Results

Fill in the two files below with your verified data:

- `hardware/pinout/x240_keyboard_fpc_pinout.md`
- `hardware/pinout/x240_clickpad_fpc_pinout.md`

Use the templates provided in those files. Accurate pinout data here is the foundation
of the entire build — take your time and double-check every entry.

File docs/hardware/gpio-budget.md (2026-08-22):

---
title: GPIO budget
parent: Hardware
nav_order: 3
---

# GPIO budget and the shift-register decision

## The wall

A Raspberry Pi Pico exposes **26 GPIO**: GP0–GP22 and GP26–GP28. (GP23–GP25 exist on the
RP2040 but are consumed on the Pico by the SMPS mode pin, VBUS sense and the on-board LED.)

The earlier plan assumed an **8 × 13 matrix = 21 lines**, leaving 5 for everything else
and declaring "all 26 GPIOs used". That number was a guess. The closest documented
chiclet-era ThinkPad keyboard — the 04Y0819 reverse-engineered in
[delingren/thinkpad_keyboards](https://github.com/delingren/thinkpad_keyboards) — is a
**17 × 9 matrix = 26 lines for the matrix alone**, before PS/2, backlight, power button or
LED. The same author rejected the Pico for exactly this reason.

Until [probing](https://github.com/nikolareljin/x240-kbd/blob/main/hardware/pinout/probing_procedure.md) measures the X240's matrix, the
design has to assume the worst documented case.

## Demand

| Need | Lines | Notes |
|---|---|---|
| Matrix, worst documented case | 26 | 17 drive + 9 sense, or the transpose |
| PS/2 to the ClickPad | 2 | DATA + CLK, adjacent pins for the PIO driver |
| Backlight gate | 1 | |
| Power button | 1 | |
| Touchpad LED | 1 | |
| Reserve: second PS/2 for a standalone TrackPoint | 2 | only if probing shows the TrackPoint is not on the ClickPad's pass-through |
| **Total** | **33** | against 26 available |

## Options considered

| Option | GPIO | Verdict |
|---|---|---|
| **74HC165 sense chain on the Pico** | 26 − 24 sense + 3 = plenty | **Chosen.** 3 GPIO read up to 24 sense lines. Drive lines stay on GPIO. No new board, no new toolchain, ~$5 of parts. |
| Waveshare RP2040-Zero | 29 | 3 more pins is not enough margin against 33; castellated-only pins are hostile to perfboard. |
| Larger MCU (STM32G474, RP2350B-based boards) | 30–48 | Solves the count but changes the QMK platform, the bootloader story and every doc. delingren went this way; we do not need to. |
| I²C I/O expander (MCP23017) | 2 | Adds an I²C transaction per scan (~100 µs at 400 kHz per 16 bits) and driver complexity for no benefit over a shift register. |
| Diode-free charlieplexing | — | Not applicable — the membrane's matrix is fixed. |

## Chosen allocation

| GPIO | Function | Note |
|---|---|---|
| GP0–GP9 | Matrix **drive** lines D0–D9 | driven LOW one at a time; 10 available, ≥ the documented 9 |
| GP16 | Sense chain serial out ← 74HC165 `Q7` | SPI0 RX |
| GP17 | Sense chain `PL` (parallel load, active LOW) | plain GPIO |
| GP18 | Sense chain `CP` (shift clock) | SPI0 SCK |
| GP21 | PS/2 **DATA** (ClickPad) | |
| GP22 | PS/2 **CLK** (ClickPad) | PIO driver rule: clock = data + 1 |
| GP26 | Backlight → MOSFET gate | |
| GP27 | Power button, active LOW | internal pull-up |
| GP28 | Touchpad LED | via 100 Ω |
| GP10–GP15, GP19, GP20 | **Spare (8)** | GP19/GP20 reserved as a second PS/2 pair (DATA = 19, CLK = 20) |

The authoritative copy of this table lives in
[`../../hardware/wiring/wiring_diagram.md`](https://github.com/nikolareljin/x240-kbd/blob/main/hardware/wiring/wiring_diagram.md).
If the two ever disagree, the wiring diagram wins and this page is wrong.

If probing finds the matrix is transposed (many sense lines, few drive lines), swap roles:
put the larger dimension on the chain. The chain does not care which side it reads.

## Timing budget

QMK's scan loop should complete in well under 1 ms for good debounce behaviour.

- SPI0 at 8 MHz: 24 bits = **3 µs** per drive line.
- `PL` pulse + settle (`MATRIX_IO_DELAY`, 30 µs default) dominates: ~35 µs per drive line.
- 10 drive lines → **~350 µs** per full scan. Comfortable.

A bit-banged chain read would be ~10× slower and still acceptable, so SPI is a convenience,
not a requirement — useful to know when debugging.

## What this does *not* solve

Anti-ghosting. Whether the X240 membrane has diodes is a property of the keyboard, settled
by the three-key test in Phase 1, independent of how the sense lines are read.

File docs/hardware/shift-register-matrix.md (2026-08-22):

---
title: 74HC165 sense chain
parent: Hardware
nav_order: 4
---

# 74HC165 sense-chain reference

Three cascaded 74HC165 shift registers read up to 24 matrix sense lines through three Pico
GPIO. This page is the electrical reference; the firmware side is in
[`../firmware/architecture.md`](../firmware/architecture.md).

Datasheet: [Nexperia 74HC_HCT165](https://assets.nexperia.com/documents/data-sheet/74HC_HCT165.pdf).

## How a 74HC165 works

- `PL` LOW → the eight inputs D0–D7 are loaded into the register **asynchronously**.
- `PL` HIGH → each rising edge on `CP` shifts the register one bit toward `Q7`, pulling a
  new bit in from `DS`.
- `CE` must be LOW for `CP` to do anything.
- `Q7` is the serial output; `DS` is the serial input from the previous device in a chain.

So one read is: pulse `PL` low, then clock 8 × *n* bits out while reading `Q7`.

## Chain schematic

74HC165 sense chain

```
                 Pico
   GP17 (PL)  ───┬─────────────────┬─────────────────┐
   GP18 (CP)  ──┬┼────────────────┬┼────────────────┐│
                ││                ││                ││
            ┌───┴┴────┐       ┌───┴┴────┐       ┌───┴┴────┐
            │ U1      │       │ U2      │       │ U3      │
   GP16 ◄───┤Q7     DS│◄──────┤Q7     DS│◄──────┤Q7     DS│◄── GND
            │ 74HC165 │       │ 74HC165 │       │ 74HC165 │
            │CE=GND   │       │CE=GND   │       │CE=GND   │
            │D0..D7   │       │D0..D7   │       │D0..D7   │
            └─┬┬┬┬┬┬┬┬┘       └─┬┬┬┬┬┬┬┬┘       └─┬┬┬┬┬┬┬┬┘
              S0 … S7           S8 … S15          S16 … S23      ← sense lines from FPC
              ││││││││          ││││││││          ││││││││
             [RN1 10k×8]       [RN2 10k×8]       [RN3 10k×8]     ← bussed SIP pull-ups
                 │                  │                  │
                3V3                3V3                3V3
```

Bit order on the wire: the **first** bit clocked out of `GP16` is U1's `D7` (S7), the last
is U3's `D0` (S16). Document the mapping once in firmware and never reason about it twice.

## Wiring rules

| Pin | Connection | Why |
|---|---|---|
| `VCC` | 3V3, with 100 nF to GND at each chip | HC logic, 2.0–6.0 V range |
| `CE` | GND on every device | clock enable must be LOW or nothing shifts |
| `DS` of U3 (last) | GND | defines the bits that shift in past the end of the chain |
| `D0–D7` | sense line **and** 10 kΩ pull-up to 3V3 | **no internal pull-ups** — floating inputs read random keys |
| `PL` | all three in parallel to GP17 | one latch pulse loads all 24 bits at once |
| `CP` | all three in parallel to GP18 | |
| `Q7` | U3 → U2 `DS`, U2 → U1 `DS`, U1 → GP16 | |

Use 9-pin bussed SIP networks (common pin to 3V3) — three parts instead of twenty-four
resistors on a stripboard. On the Rev B PCB these become 4 × 0603 arrays.

## Scan sequence

```
for each drive line Dk in GP0..GP9:
    set Dk LOW                        (others high-Z / high)
    wait MATRIX_IO_DELAY              (~30 µs; lets the pull-ups settle)
    PL LOW for ≥ 100 ns, then HIGH    (latch all 24 sense inputs)
    clock 24 bits over SPI0, MSB first, reading GP16
    release Dk
    row[k] = ~bits & mask             (a pressed key reads LOW)
```

Timing from the datasheet at 3.3 V is generous: `PL` pulse width min ~25 ns, `CP` up to
~30 MHz. SPI0 at 8 MHz has ~4× margin. Full scan ≈ 350 µs for 10 drive lines.

## Failure modes and what they look like

| Symptom | Cause |
|---|---|
| Random keys with nothing pressed | A sense input is floating — missing pull-up, or the SIP network's common pin is not on 3V3 |
| Every key reads as the same column, or a stuck pattern | `PL` and `CP` swapped, or `CE` left floating |
| Keys appear shifted by 8 | Chain order assumption wrong — U1/U3 `Q7` → `DS` crossed |
| Whole chain dead | `CE` not grounded, or `DS` of the last device floating and reading as bits |
| Keys work but ghost with three held | Not a chain problem — the membrane lacks diodes. See Phase 1 |

The [`tools/shift_register_test/`](https://github.com/nikolareljin/x240-kbd/blob/main/tools/) CircuitPython script (M2) exercises the
chain with nothing else connected: ground each sense input in turn and watch the bit
position light up.

## Why not the 74HC595

The 595 is the *output* counterpart (serial-in, parallel-out). It would expand the **drive**
side instead. We have 10 spare drive GPIO and the chain only needs to expand sensing, so a
165 is the right part. If probing finds a transposed matrix, the chain moves to whichever
side is larger — still 165s, still sensing.

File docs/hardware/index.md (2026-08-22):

---
title: Hardware
nav_order: 20
has_children: true
---

# Hardware

Electrical design: what every part is, what it costs, why the pin budget forced a shift
register, how the TrackPoint is reached, and what the PCB revision adds.

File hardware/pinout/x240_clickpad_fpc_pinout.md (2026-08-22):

# X240 ClickPad FPC Pinout

**Device:** Synaptics ClickPad (ThinkPad X240)  
**Protocol:** PS/2  
**Connector:** 0.5 mm pitch ZIF, 6–12 pins (count varies — measure yours)  
**Status:** Template — fill in verified data after Phase 1 probing (milestone M2, issue #29)

---

## Pin Map

| Pin | Function | Pico GPIO | Notes |
|-----|---|---|---|
| 1 | ? | | |
| 2 | ? | | |
| 3 | ? | | |
| 4 | ? | | |
| 5 | ? | | |
| 6 | ? | | |
| 7 | (if >6) | | |
| 8 | (if >7) | | |

---

## Identified Signals (fill after probing)

| Signal | FPC Pin | Pico GPIO | Notes |
|---|---|---|---|
| VCC | | 3V3 | Typically 3.3 V; verify before connecting |
| GND | | GND | |
| PS/2 DATA | | GP21 | 4.7 kΩ pull-up to 3.3 V required |
| PS/2 CLK | | GP22 | 4.7 kΩ pull-up to 3.3 V required; CLK = DATA + 1 for the PIO driver |
| LED anode | | GP28 | Via 100 Ω resistor |
| LED cathode | | GND | |

---

## TrackPoint route (fill after probing)

With `tools/ps2_sniffer/ps2_sniffer.py` in Synaptics mode, push the stick with no finger on the pad.

| Observation | Result |
|---|---|
| Pass-through frames (`W == 3`) seen | ☐ yes → TrackPoint rides this bus; no extra wiring |
| No pass-through frames | ☐ → TrackPoint is standalone; record its CLK/DATA (keyboard FPC) → GP20/GP19 |
| Synaptics identify byte 1 | `0x__` (expect `0x47`) |
| Capabilities: PassThrough bit | ☐ set / ☐ clear |

## Notes

- The ClickPad's **top-edge zone** acts as the TrackPoint buttons and the bottom corners as
  the touchpad buttons; all arrive in the touchpad packet's L/R bits, not in the guest frame.
- Standard PS/2 relative mode gives cursor + clicks only. **Absolute mode with pass-through
  is required for the TrackPoint** — see `docs/hardware/trackpoint.md`.

- The Synaptics ClickPad powers up in standard PS/2 mouse mode automatically.
  No special initialisation sequence is needed for basic cursor + click operation.
- Multi-touch gestures are out of scope; absolute mode is used only to reach the
  pass-through port and to derive single-finger deltas.
- If VCC on your touchpad is 5 V (uncommon on X240 but possible on some revisions),
  add a 3.3 V → 5 V level shifter on CLK and DATA lines.

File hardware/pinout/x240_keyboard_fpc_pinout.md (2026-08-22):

# X240 Keyboard FPC Pinout

**Part:** 0C44020 / SG-58950-XUA  
**Connector:** 40-pin ZIF, 0.5 mm pitch  
**Status:** Template — fill in verified data after Phase 1 probing (milestone M2, issue #28)

Terminology: **drive** lines are pulled LOW one at a time by GP0–GP9; **sense** lines are
read through the 74HC165 chain (S0 = U1.D0 … S23 = U3.D7). If probing shows the matrix is
transposed (more drive than sense), swap the roles — the chain goes on the larger side.

---

## Pin Map

| Pin | Function | Pico GPIO | Notes |
|-----|---|---|---|
| 1 | ? | | |
| 2 | ? | | |
| 3 | ? | | |
| 4 | ? | | |
| 5 | ? | | |
| 6 | ? | | |
| 7 | ? | | |
| 8 | ? | | |
| 9 | ? | | |
| 10  | ? | | |
| 11  | ? | | |
| 12  | ? | | |
| 13  | ? | | |
| 14  | ? | | |
| 15  | ? | | |
| 16  | ? | | |
| 17  | ? | | |
| 18  | ? | | |
| 19  | ? | | |
| 20  | ? | | |
| 21  | ? | | |
| 22  | ? | | |
| 23  | ? | | |
| 24  | ? | | |
| 25  | ? | | |
| 26  | ? | | |
| 27  | ? | | |
| 28  | ? | | |
| 29  | ? | | |
| 30  | ? | | |
| 31  | ? | | |
| 32  | ? | | |
| 33  | ? | | |
| 34  | ? | | |
| 35  | ? | | |
| 36  | ? | | |
| 37  | ? | | |
| 38  | ? | | |
| 39  | ? | | |
| 40  | ? | | |

---

## Matrix Summary (fill after probing)

| Signal | FPC pin | Destination |
|---|---|---|
| Drive D0 | | GP0 |
| Drive D1 | | GP1 |
| Drive D2 | | GP2 |
| Drive D3 | | GP3 |
| Drive D4 | | GP4 |
| Drive D5 | | GP5 |
| Drive D6 | | GP6 |
| Drive D7 | | GP7 |
| Drive D8 | | GP8 |
| Drive D9 | | GP9 |
| Sense S0–S7 | | U1 D0–D7 |
| Sense S8–S15 | | U2 D0–D7 |
| Sense S16–S23 | | U3 D0–D7 |
| GND | | GND |
| VCC | | 3V3 |
| Backlight + | | R_series |
| Backlight − | | Q1 drain |
| Power button | | GP27 |
| TrackPoint CLK *(only if standalone — see ClickPad pinout)* | | GP20 |
| TrackPoint DATA *(only if standalone)* | | GP19 |
| TrackPoint reset *(if present)* | | spare GPIO, pulsed HIGH at boot |

Measured matrix size: ____ drive × ____ sense.  Three-key ghost test: diodes present ☐ / absent ☐

---

## Key → Matrix Cell Map (fill after probing)

| Key | Drive | Sense |
|---|---|---|
| Esc | | |
| F1 | | |
| F2 | | |
| F3 | | |
| F4 | | |
| F5 | | |
| F6 | | |
| F7 | | |
| F8 | | |
| F9 | | |
| F10 | | |
| F11 | | |
| F12 | | |
| ` | | |
| 1 | | |
| 2 | | |
| 3 | | |
| 4 | | |
| 5 | | |
| 6 | | |
| 7 | | |
| 8 | | |
| 9 | | |
| 0 | | |
| - | | |
| = | | |
| Tab | | |
| Q | | |
| W | | |
| E | | |
| R | | |
| T | | |
| Y | | |
| U | | |
| I | | |
| O | | |
| P | | |
| [ | | |
| ] | | |
| CapsLock | | |
| A | | |
| S | | |
| D | | |
| F | | |
| G | | |
| H | | |
| J | | |
| K | | |
| L | | |
| ; | | |
| ' | | |
| Backspace| | |
| LShift | | |
| Z | | |
| X | | |
| C | | |
| V | | |
| B | | |
| N | | |
| M | | |
| , | | |
| . | | |
| / | | |
| RShift | | |
| PgUp | | |
| LCtrl | | |
| Win | | |
| LAlt | | |
| Space | | |
| RAlt | | |
| Menu | | |
| RCtrl | | |
| PgDn | | |
| Ins | | |
| Del | | |
| Home | | |
| End | | |
| Up | | |
| Left | | |
| Down | | |
| Right | | |
| PrtSc | | |
| ScrLk | | |
| Pause | | |
| \ | | |
| Enter | | |
| FN | | |

---

## References for Cross-Checking

Before probing, cross-reference with community documentation:

- [delingren/thinkpad_keyboards](https://github.com/delingren/thinkpad_keyboards) — 04Y0819, 17 × 9 matrix (era analogue, not this connector)
- [hamishcoleman/thinkpad-usbkb](https://github.com/hamishcoleman/thinkpad-usbkb) — `keyboard-thinkpad.pinout.txt` (older connector)
- [thedalles77/USB_Laptop_Keyboard_Controller](https://github.com/thedalles77/USB_Laptop_Keyboard_Controller) — method and T61 example
- [Lenovo X240 Hardware Maintenance Manual](https://support.lenovo.com/us/en/manuals/um019141)

None of these documents the 0C44020's 40-pin connector. Measure; do not copy.

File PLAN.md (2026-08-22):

# x240-kbd — Project Plan

This is the living plan. It was corrected in August 2026 after research contradicted
several of its original claims; the corrections are listed in [`CHANGELOG.md`](CHANGELOG.md)
and the reasoning lives in the `docs/` pages linked below. Work is tracked as
[GitHub issues](https://github.com/nikolareljin/x240-kbd/issues) in nine milestones.

## Goal

Repurpose a ThinkPad X240 keyboard (FRU 0C44020, with TrackPoint) and its Synaptics
ClickPad into a standalone USB HID device on a Raspberry Pi Pico running QMK. Reuse the
X240 top section as-is. Close the bottom with either a 3D-printed split case or a hand-made
enclosure. Works on any OS without drivers.

Two electronics revisions share one firmware and one GPIO map: **Rev A** perfboard,
**Rev B** KiCad PCB. "Done" is a project someone else can rebuild from the repo.

---

## Hardware

| Component | Detail | Reference |
|---|---|---|
| Controller | Raspberry Pi Pico, RP2040, 26 exposed GPIO | [components](docs/hardware/components.md) |
| Keyboard | X240 0C44020, 40-pin 0.5 mm FPC; **matrix size unknown until probed** | [probing](hardware/pinout/probing_procedure.md) |
| Sense expansion | 3 × 74HC165, 24 sense lines on 3 GPIO | [sense chain](docs/hardware/shift-register-matrix.md) |
| Touchpad | Synaptics ClickPad, PS/2, separate FPC | [pointing stack](docs/firmware/pointing-stack.md) |
| TrackPoint | Through the ClickPad's pass-through port — no extra pins | [trackpoint](docs/hardware/trackpoint.md) |
| Power button | In the keyboard assembly, GP27 | |
| Backlight | LED strip via MOSFET on GP26, `software` driver | [backlight](docs/hardware/backlight.md) |
| Touchpad LED | GP28 via 100 Ω | |
| USB | Micro-USB; USB-C via TP1 (GND) / TP2 (D−) / TP3 (D+) | README |
| Enclosure | Printed split case **or** hand-made (E1–E4) | [printed](docs/enclosure/printed.md) · [hand-made](docs/enclosure/handmade.md) |

### GPIO allocation

The authoritative table is in
[`hardware/wiring/wiring_diagram.md`](hardware/wiring/wiring_diagram.md). Summary:

| GPIO | Function |
|---|---|
| GP0–GP9 | Matrix drive lines D0–D9 |
| GP16 / GP17 / GP18 | Sense chain Q7 (SPI0 RX) / PL / CP (SPI0 SCK) |
| GP21 / GP22 | PS/2 DATA / CLK — ClickPad + TrackPoint (PIO rule: clock = data + 1) |
| GP26 | Backlight MOSFET gate |
| GP27 | Power button, active LOW |
| GP28 | Touchpad LED |
| GP10–GP15, GP19, GP20 | Spare; GP19/GP20 reserved for a standalone-TrackPoint PS/2 line |

Why not a plain 8 × 13 matrix on GPIO: [`docs/hardware/gpio-budget.md`](docs/hardware/gpio-budget.md).

---

## Firmware: QMK on RP2040

QMK over KMK because it has the RP2040 PIO PS/2 host driver, compiled C scan latency,
TinyUSB composite HID, NKRO and a custom-matrix API — all of which this design uses.

```make
MCU                    = RP2040
BOOTLOADER             = rp2040
CUSTOM_MATRIX          = lite        # 74HC165 chain in matrix.c
SRC                   += matrix.c synaptics.c trackpoint.c
POINTING_DEVICE_ENABLE = yes
POINTING_DEVICE_DRIVER = custom      # synaptics.c owns the bus (6-byte packets)
PS2_ENABLE             = yes
PS2_MOUSE_ENABLE       = no          # ps2_mouse.c only knows 3-byte packets
PS2_DRIVER             = vendor      # RP2040 PIO; usart is ATmega32u4-only
BACKLIGHT_ENABLE       = yes         # backlit keyboard variants
BACKLIGHT_DRIVER       = software    # RP2040 pwm fails to build (QMK #24470)
EXTRAKEY_ENABLE        = yes
NKRO_ENABLE            = yes
MOUSEKEY_ENABLE        = yes
LTO_ENABLE             = yes
```

Every flag, with its upstream reference: [`docs/firmware/qmk-configuration.md`](docs/firmware/qmk-configuration.md).
File map and data paths: [`docs/firmware/architecture.md`](docs/firmware/architecture.md).

### Layers

- **Layer 0 BASE** — full X240 QWERTY; FN → `MO(_FN)`.
- **Layer 1 FN** — F1–F12 → media/system keys; FN + Esc → FN Lock (`CK_FNLK`);
  FN + F11 → backlight step (`CK_BKLT`).
- Power button is a dedicated GP27 input polled in `matrix_scan_kb()` with a 500 ms guard,
  not a matrix key.

### USB HID composite

Interface 0 keyboard (boot + NKRO) · interface 1 mouse (ClickPad + TrackPoint merged) ·
interface 2 consumer control.

---

## FN key map

| FN + | Action | Keycode | | FN + | Action | Keycode |
|---|---|---|---|---|---|---|
| F1 | Mute | `KC_MUTE` | | F9 | Settings | `KC_F9` |
| F2 | Volume down | `KC_VOLD` | | F10 | Bluetooth | `KC_F10` |
| F3 | Volume up | `KC_VOLU` | | F11 | Backlight | `CK_BKLT` |
| F4 | Mic mute | `KC_F20` | | F12 | Print Screen | `KC_PSCR` |
| F5 | Brightness down | `KC_BRID` | | PgUp | Home | `KC_HOME` |
| F6 | Brightness up | `KC_BRIU` | | PgDn | End | `KC_END` |
| F7 | External display | `KC_F7` | | Left / Right | Prev / next track | `KC_MPRV` / `KC_MNXT` |
| F8 | Wireless | `KC_F8` | | Esc | FN Lock | `CK_FNLK` |

---

## Bill of materials

Full tiers with prices and links: [`docs/hardware/bom-and-cost.md`](docs/hardware/bom-and-cost.md).
All-in **$90–130** (Rev A, own printer) to **$110–150** (Rev A, reused X240 base cover);
Rev B PCB adds $25–35. The donor parts are most of the cost.

---

## Phases

Each phase is a GitHub milestone. Hardware-dependent issues carry `blocked-on-hardware`.

### M0 Documentation — this pass

Component reference, priced BOM, design corrections, the new `docs/` tree, rewrites of the
builder files. Done when the PR merges.

### M1 Diagrams & site

Authored SVG schematics (USB-C, sense chain, backlight, PS/2, internal layout, FPC
orientation, signal flow); Jekyll `just-the-docs` from `/docs`; landing page; Pages enabled.

### M2 Probing — do this before any wiring

1. Rework `tools/matrix_probe/matrix_probe.py` for > 26 FPC pins; extend
   `tools/ps2_sniffer/ps2_sniffer.py` with the Synaptics identify sequence and
   pass-through detection; add `tools/shift_register_test/`.
2. Probe the keyboard FPC: matrix size, every key's (drive, sense) cell, GND/VCC,
   backlight, power button. **Three-key ghosting test** decides whether 1N4148s are needed.
3. Probe the ClickPad FPC: VCC/GND/CLK/DATA/LED. **Push the stick: do `W == 3` frames
   appear?** That answer fixes the TrackPoint route.
4. Fill `hardware/pinout/*.md`.

### M3 Electronics (Rev A)

Stripboard ≈100 × 80 mm: ZIF breakouts, 3 × 74HC165 with SIP pull-ups and decoupling,
backlight MOSFET, PS/2 pull-ups, power button, LED, socketed Pico. Continuity test before
USB power. Procedure: [`ASSEMBLY.md`](ASSEMBLY.md) Phase 2;
schematics: [`hardware/wiring/wiring_diagram.md`](hardware/wiring/wiring_diagram.md).

### M4 Firmware

Correct the configuration; write `matrix.c` (chain scan), `synaptics.c` (identify,
absolute mode, packet parser, logged fallback), `trackpoint.c` (guest frames); regenerate
`LAYOUT` and the keymap from the measured matrix; verify backlight, FN Lock, power guard.

Test checklist: every key; NKRO ≥ 10; ClickPad move/click; **stick moves the cursor with
no finger on the pad**; FN media keys; FN Lock; backlight levels; power button ≥ 500 ms.

### M5 Enclosure, printed

Split `bottom_case.scad` into two halves (dovetail, pins, sled as the bridge); shared
`cad/params.scad`; sled, USB strain relief, tilt feet, ZIF support block, LED light pipe;
measure, print, dry-fit, tolerance report. [`docs/enclosure/printed.md`](docs/enclosure/printed.md).

Print settings: PETG, 0.2 mm, 4 walls, 25 % gyroid. FPC bend radius ≥ 5 mm.

### M6 Enclosure, hand-made

E1 original X240 base cover (worked example with photos), E2 laser-cut plates from the same
SCAD via `projection()`, E3 Hammond 515 console, E4 wood frame; presentation box.
[`docs/enclosure/handmade.md`](docs/enclosure/handmade.md).

### M7 PCB (Rev B)

KiCad schematic and layout, DRC, gerbers, interactive BOM, ordering notes, bring-up on Rev A
firmware. Mounting holes fit both the printed sled and the X240 base-cover standoffs.
[`docs/hardware/pcb.md`](docs/hardware/pcb.md).

### M8 Release

Validate on Linux, Windows, macOS; publish v0.2.0 with a tested `.uf2`.

---

## USB-C upgrade path

Default is the Pico's Micro-USB. Optional: solder a USB-C breakout (with 5.1 kΩ CC
pull-downs) to the Pico's underside pads **TP1 = GND, TP2 = D−, TP3 = D+** plus VBUS; set
`usb_c = true` in `cad/bottom_case.scad`. No firmware change. Or use a Pimoroni Pico LiPo.

USB-C breakout to Pico test pads

---

## Verification checklist

- [ ] Every key generates the correct HID keycode
- [ ] NKRO: 10+ simultaneous keys register
- [ ] ClickPad: cursor, left click, right click
- [ ] TrackPoint: cursor moves from the stick alone
- [ ] Media keys work on Windows 10/11, macOS 14+, Ubuntu 24
- [ ] Backlight: 5 levels (backlit variant; breathing is unavailable with software PWM)
- [ ] Power button: hold ≥ 500 ms → system power dialog; short press ignored
- [ ] FN Lock works
- [ ] Enumerates with no driver install on a fresh OS
- [ ] Enclosure closes with no pinched cable and the USB strain relief takes a pull

---

## Key references

Annotated list: [`docs/references.md`](docs/references.md).

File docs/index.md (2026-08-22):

---
title: Home
nav_order: 1
---

# x240-kbd

A standalone USB keyboard with touchpad **and TrackPoint**, built from a ThinkPad X240
keyboard assembly (FRU 0C44020) and its Synaptics ClickPad, driven by a Raspberry Pi Pico
running QMK. No drivers on any OS — it is a plain USB HID composite device.

Standalone X240 Keyboard

{: .warning }
> **Status: designed, not yet built.** Two things are decided only by measurement:
> the keyboard's matrix pinout, and whether the TrackPoint rides the ClickPad's PS/2
> pass-through port. Everything here is designed to survive either answer. The probing
> step is [milestone M2](https://github.com/nikolareljin/x240-kbd/milestone/3).

Signal flow from keyboard to USB

## What you get

- Full 84-key X240 layout, NKRO, FN layer with the ThinkPad media keys, FN Lock
- ClickPad cursor and click zones, **TrackPoint** decoded from Synaptics pass-through frames
- Keyboard backlight (backlit variants), power button with a hold guard, touchpad LED
- Micro-USB, with a documented USB-C upgrade
- **Two enclosure routes** — 3D-printed split case, or hand-made with no printer
- **Two electronics revisions** — Rev A perfboard, Rev B PCB — same firmware, same GPIO map

## What it costs

| Build | All-in (USD, Aug 2026) |
|---|---|
| Rev A + your own printer | **$90–130** |
| Rev A + reused X240 base cover, no printer | **$110–150** |
| Rev B PCB | add $25–35 |

The donor keyboard and palmrest are most of it. [Full BOM →](hardware/bom-and-cost.md)

## Start here

1. [Component reference](hardware/components.md) — every part, datasheet, and where to buy it.
2. [GPIO budget](hardware/gpio-budget.md) — why a Pico needs a shift register for this keyboard.
3. [TrackPoint](hardware/trackpoint.md) — how the stick reaches the host, and the one measurement that confirms it.
4. [Firmware](firmware/) — what QMK is configured to do, and the two corrections that make it build on RP2040.
5. [Enclosure](enclosure/) — printed or hand-made.
6. [References](references.md) — the projects and datasheets this stands on.

The step-by-step build lives in the repository:
[`ASSEMBLY.md`](https://github.com/nikolareljin/x240-kbd/blob/main/ASSEMBLY.md), with the
wiring reference in
[`hardware/wiring/wiring_diagram.md`](https://github.com/nikolareljin/x240-kbd/blob/main/hardware/wiring/wiring_diagram.md).

## Two things the earlier plan got wrong

This project started as a paper design and was corrected after research. The full list is in
the [changelog](https://github.com/nikolareljin/x240-kbd/blob/main/CHANGELOG.md); the two a
builder must know:

- **USB-C wiring.** The Pico's underside pads are **TP1 = GND, TP2 = D−, TP3 = D+**. The
  first revision said TP1 = D−; built that way, ground shorts onto the data line.
- **PS/2 driver.** On RP2040 the only hardware PS/2 path is the PIO driver (`vendor`),
  and it requires the clock pin to be the data pin + 1 — so **DATA = GP21, CLK = GP22**.

## Progress

Nine milestones, M0 Documentation through M8 Release, tracked as
[issues](https://github.com/nikolareljin/x240-kbd/issues). Issues labelled
`blocked-on-hardware` wait for the donor parts to arrive.

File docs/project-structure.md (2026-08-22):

---
title: Project structure
nav_exclude: true
---

# Project structure

`x240-kbd` converts a ThinkPad X240 keyboard assembly (with TrackPoint) and ClickPad into a
standalone USB HID device driven by a Raspberry Pi Pico running QMK.

## Top level

| Path | Purpose |
|---|---|
| `README.md` | Builder entry point, status, features, honest cost, quick start |
| `PLAN.md` | The living plan: corrected design and the milestone sequence |
| `ASSEMBLY.md` | Step-by-step Rev A build |
| `BOM.md` | Pointer to the priced BOM in `docs/hardware/bom-and-cost.md` |
| `CHANGELOG.md` | Notable changes, including every design correction with its reason |
| `AGENTS.md` | Repository guidelines for agents and contributors |
| `LICENSE` | GPL-2.0 |

## `./dev` and `scripts/`

`./dev` is the one entry point (`scripts/cli.sh`, copied from the script-helpers
`templates/dev-cli` and never edited here). Repo behaviour lives in `scripts/project.sh`:
build = `qmk compile` in the `qmkfm/qmk_cli` container against a `qmk_firmware` checkout
(`./dev install` clones one; `QMK_HOME` overrides), docs = Jekyll in Docker, test = pytest
+ `scripts/check_links.py` + shellcheck, deploy = copy to `RPI-RP2` / `CIRCUITPY`.
`scripts/script-helpers/` is the submodule (branch `production`). Shims: `./build`,
`./test`, `./flash`, `./probe`, `./site`. Output: `out/` (ignored).

**Toolchain pinning:** `scripts/toolchain.env` holds the five Docker images by digest
(`qmkfm/qmk_cli`, `jekyll/jekyll`, `openscad/openscad`, `kicad/kicad`,
`freerouting/freerouting`) and the exact `qmk_firmware` commit; `scripts/pull_toolchain.sh` pulls them (`--save`/`--load` for offline tarballs,
`--refresh` to re-resolve, `--verify` to print versions). `./dev install` and `./dev
update` go through it, so a build is repeatable later.

`docs/presentation/` holds the printable label (`label.svg`, 60 × 40 mm) and the A6
quick-start card.

`.github/workflows/ci.yml` calls ci-helpers' reusable `ci.yml@production` with
`./dev test` and `./dev install && ./dev build all`.

## `firmware/qmk/keyboards/x240_pico/`

Mounted into a QMK checkout to build. `keyboard.json` (USB IDs, `ps2` block, NKRO
default, Bootmagic key, layout metadata — QMK generates `LAYOUT` from it), `config.h`
(pins, SPI, tuning), `rules.mk` (custom matrix, custom pointing driver, software backlight),
`halconf.h`/`mcuconf.h` (SPI0 on), `matrix.c`, `synaptics.c/.h`, `trackpoint.c/.h`,
`x240_pico.c/.h`, `keymaps/default/keymap.c`. Builds; keymap is a placeholder until #38.

## `hardware/`

- `pinout/` — probing procedure and the measured pinout tables. **Hardware source of truth.**
- `wiring/wiring_diagram.md` — **the single authoritative GPIO table** plus schematics.
- `pcb/` — Rev B KiCad project, **generated**: `netlist_model.py` (parts, library names,
  nets) → `gen_schematic.py` (`.kicad_sch`, ERC) and `gen_pcb.py` (`.kicad_pcb`, placement,
  DRC); `route_pcb.py` round-trips a Specctra DSN/SES through freerouting. `./dev build pcb`
  runs the lot and exports PDF, gerbers, drill, position and BOM to `out/pcb/`. Edit the
  model, never the KiCad files by hand — they are overwritten.

## `tools/`

CircuitPython scripts run on the Pico as `code.py`: `matrix_probe/`, `ps2_sniffer/`,
`shift_register_test/`. Standalone; no host-side dependencies. Their pure protocol logic
is unit-tested on a PC under `tools/tests/` (pytest). Index: `tools/README.md`.

## `cad/`

OpenSCAD sources, all including `params.scad` (the only place a dimension lives): the
split `bottom_case`, `perfboard_sled`, `usb_strain_relief`, `tilt_feet`, `zif_support_block`,
`led_light_pipe`, `pico_mount_bracket`, `fpc_cable_guide`; `tests/joint_intersection.scad`
is the split-joint check run by `./dev test`; `export_plates.scad` projects the same solids
into the laser-cut plates and the box insert (DXF).
`./dev build cad` renders to `out/cad/`; meshes are never committed. Index: `cad/README.md`.

## `docs/`

The documentation site source. `hardware/`, `firmware/`, `enclosure/` each have an
`index.md` parent page; `references.md`, `glossary.md`; `images/`. Maintainer pages
(`project-structure`, `design-instructions`, `code-instructions`, `build-and-test`) carry
`nav_exclude: true` and are excluded from the site.

Where new work goes: a measured fact → `hardware/pinout/`; a wiring change →
`hardware/wiring/` first, then the docs that cite it; a design decision → the relevant
`docs/` page plus `CHANGELOG.md`; anything with a state → a GitHub issue, not a doc.

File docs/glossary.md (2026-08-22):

---
title: Glossary
nav_order: 91
---

# Glossary

| Term | Meaning here |
|---|---|
| **Absolute mode** | Synaptics ClickPad reporting finger X/Y/Z position in 6-byte packets instead of relative deltas. Required to receive pass-through frames. |
| **Bit-bang** | Driving a serial protocol from software GPIO toggling instead of a hardware peripheral. QMK's `busywait` PS/2 driver; slow and jittery. |
| **Bootmagic** | QMK feature: holding a designated key (here top-left) while plugging in enters the bootloader. |
| **BOOTSEL** | The button on the Pico that, held at power-up, exposes the `RPI-RP2` UF2 drive. |
| **ClickPad** | A Synaptics touchpad with no separate buttons; the whole surface clicks and zones on it act as buttons. Distinct from a TouchPad with discrete buttons. |
| **COL2ROW** | QMK diode direction: current flows from column to row through the key's diode. Determines which side is driven and which is sensed. With the shift-register chain the "column" side is the chain. |
| **Drive line** | A matrix line the firmware pulls LOW one at a time while reading the others. Rows in QMK's default terminology. |
| **FFC** | Flat Flexible Cable — a laminated ribbon with exposed ends; used here as the 40-pin extension. |
| **FPC** | Flexible Printed Circuit — a polyimide flex with etched traces; the keyboard and ClickPad tails. |
| **FRU** | Field Replaceable Unit — Lenovo's part number for a service part (e.g. `0C44020`). |
| **Guest / pass-through** | The Synaptics mechanism that forwards a second PS/2 device's packets (the TrackPoint) inside the touchpad's own stream, marked by `W == 3`. |
| **Magic knock** | The Synaptics identify sequence: four `SetResolution` commands encoding a query number, then `StatusRequest`. |
| **NKRO** | N-Key Rollover — every key reports independently; needs the matrix diodes to avoid ghosting. |
| **PIO** | RP2040 Programmable I/O — small state machines that implement protocols in hardware. QMK's `vendor` PS/2 driver runs on PIO0. |
| **PL / CP / Q7 / DS / CE** | 74HC165 pins: parallel load, clock, serial out, serial in, clock enable. |
| **PS/2** | The two-wire (CLK, DATA) bidirectional serial bus used by the ClickPad and TrackPoint. |
| **Rev A / Rev B** | Perfboard build / KiCad PCB build. Same firmware, same GPIO map. |
| **Sense line** | A matrix line read (with a pull-up) while a drive line is LOW. Read through the 74HC165 chain. |
| **SIP network** | Single-in-line resistor network; "bussed" means all resistors share one common pin. |
| **TrackPoint** | The red pointing stick; strain gauges plus a controller that outputs PS/2. |
| **UF2** | USB Flashing Format — the file you drag onto the `RPI-RP2` drive. |
| **ZIF** | Zero Insertion Force connector — a hinged tab clamps the FPC after insertion. |

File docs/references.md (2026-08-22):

---
title: References
nav_order: 90
---

# Annotated references

Sources this project relies on, with a note on **how much of each applies to the X240
specifically**. "Era analogue" means a closely related ThinkPad that informs the design
but whose numbers must not be copied into our pinout files.

## Community projects

| Source | What it gives us | X240-specific? |
|---|---|---|
| [delingren/thinkpad_keyboards](https://github.com/delingren/thinkpad_keyboards) | Reverse-engineering of the 04Y0819 (X1 Carbon Gen 1 era): 32-pin matrix FPC, **17 × 9 matrix**, 20-pin TrackPoint/backlight FPC, QMK with the RP2040 PIO PS/2 driver, backlight current measurement, the TrackPoint reset-pulse finding, and the MCU pin-count comparison that rejected the Pico. | Era analogue — the pin-budget lesson transfers; the pinout does not. |
| [hamishcoleman/thinkpad-usbkb](https://github.com/hamishcoleman/thinkpad-usbkb) | KiCad design of a ThinkPad-keyboard USB adapter on an EFM32; `keyboard-thinkpad.pinout.txt` has an 8 × 8 matrix map for an older (X220-era) connector. | Era analogue — different connector and matrix. |
| [thedalles77/USB_Laptop_Keyboard_Controller](https://github.com/thedalles77/USB_Laptop_Keyboard_Controller) (Frank Adams) | The general method: Teensy/RP2040 matrix decoding, `matrixgenerator.py`, Eagle scanner boards, and worked examples for the T61, P15/P17 and older ThinkPads. Also the [RP2350 Stamp XL version](https://www.hackster.io/frank-adams/usb-laptop-keyboard-controller-solder-party-rp2350-stamp-xl-4fa642) with 40 GPIO. | Method only. |
| [Frank Adams — touchpad/TrackPoint conversion](https://www.hackster.io/frank-adams/laptop-touchpad-trackpoint-conversion-to-usb-d70519) | PS/2 touchpad and TrackPoint bring-up on Teensy/Pico, including level-shifting notes. | Method only. |
| [Instructables — reverse-engineer any keyboard matrix with a Pico](https://www.instructables.com/How-to-Reverse-Engineer-Almost-Any-Keyboard-Matrix/) | The probing technique our `matrix_probe.py` implements. | Method only. |
| [sharktastica — TrackPoint wiki](https://sharktastica.co.uk/wiki/trackpoint) | Module generations; confirms the **two-piece T440/X240-family module with four connections**. | Yes, module family. |
| [ThinkPads forum — X240 trackpoint/trackpad](https://forum.thinkpads.com/viewtopic.php?t=128403) | Field reports on X240 ClickPad/TrackPoint behaviour. | Yes. |
| [iFixit — X240 keyboard replacement](https://www.ifixit.com/Guide/Lenovo+Thinkpad+X240+Keyboard+Replacement/118924) | Photos of the connectors and disassembly order. | Yes. |

## Manufacturer documentation

| Source | Used for |
|---|---|
| [Raspberry Pi Pico datasheet](https://datasheets.raspberrypi.com/pico/pico-datasheet.pdf) | Pinout, **test points TP1 = GND, TP2 = D−, TP3 = D+**, power |
| [RP2040 datasheet](https://datasheets.raspberrypi.com/rp2040/rp2040-datasheet.pdf) | UART/SPI pin muxing, PIO |
| [Nexperia 74HC165 datasheet](https://assets.nexperia.com/documents/data-sheet/74HC_HCT165.pdf) | Timing, supply range, pin functions |
| [Nexperia 2N7002](https://assets.nexperia.com/documents/data-sheet/2N7002.pdf) · [onsemi BS170](https://www.onsemi.com/pdf/datasheet/bs170-d.pdf) | Backlight switch |
| [Hirose FH12 catalogue](https://www.hirose.com/en/product/document?series=FH12&documenttype=Catalog&lang=en&documentid=D31648_en) | Rev B FPC connectors |
| Synaptics *TouchPad Interfacing Guide* (PN 511-000275; no longer hosted publicly — the working reference is the Linux driver [`drivers/input/mouse/synaptics.c`](https://github.com/torvalds/linux/blob/master/drivers/input/mouse/synaptics.c)) | Absolute mode, packet format, pass-through |
| [Lenovo ThinkPad X240 Hardware Maintenance Manual](https://support.lenovo.com/us/en/manuals/um019141) | FRU numbers, disassembly, screw positions |
| [Adafruit 1436 product page](https://www.adafruit.com/product/1436) | To show it is a solder-pad plate, not a ZIF breakout |

## QMK

| Page | Used for |
|---|---|
| [RP2040 platform](https://docs.qmk.fm/platformdev_rp2040) | Bootloader, pin naming, PIO notes |
| [PS/2 mouse](https://docs.qmk.fm/features/ps2_mouse) | Driver table — `usart` is ATmega32u4-only; `vendor` = RP2040 PIO; clock = data + 1 |
| [Pointing device](https://docs.qmk.fm/features/pointing_device) | `pointing_device_task_kb`, report merging |
| [Backlight](https://docs.qmk.fm/features/backlight) | Driver table |
| [Issue #24470](https://github.com/qmk/qmk_firmware/issues/24470) | RP2040 `pwm` backlight does not compile; `software` works |
| [Custom matrix](https://docs.qmk.fm/custom_matrix) | `CUSTOM_MATRIX = lite` API |
| [Bootmagic](https://docs.qmk.fm/features/bootmagic) | Top-left-key bootloader entry |
| [Hardware keyboard guidelines](https://docs.qmk.fm/hardware_keyboard_guidelines) | VID/PID, layout metadata |

## Linux kernel

`drivers/input/mouse/synaptics.c` and `psmouse-base.c` — the working reference for the
identify sequence, mode byte, packet resync and pass-through handling. The ArchWiki
[Touchpad Synaptics](https://wiki.archlinux.org/title/Touchpad_Synaptics) page documents the
`serio: Synaptics pass-through port` behaviour seen on X240-class machines.

## Suppliers referenced

DigiKey, Mouser, LCSC, Jameco, Tinkersphere, Adafruit, Pimoroni, BuyDisplay, Crystalfontz,
JLCPCB, PCBWay, SendCutSend, Ponoko, Hammond Manufacturing, eBay, iFixit. Links are on the
[component reference](hardware/components.md) and [BOM](hardware/bom-and-cost.md) pages.

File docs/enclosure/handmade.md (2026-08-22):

---
title: Hand-made enclosure
parent: Enclosure
nav_order: 2
---

# Enclosure route 2 — hand-made, no 3D printer

Four variants, cheapest and best-fitting first. All reuse the X240 palmrest + keyboard deck
as the top; they differ only in what closes the bottom.

| Variant | Cost | Tools | Fit | Looks |
|---|---|---|---|---|
| **E1 Original X240 base cover** | $22–25 | screwdriver, rotary tool | perfect — it was made for this deck | stock ThinkPad |
| E2 Laser-cut sandwich | $30–60 | none (service cuts it) | good | industrial / transparent |
| E3 Hammond sloped console | $50–60 | drill, nibbler or jigsaw | deck overhangs 9 mm | desk instrument |
| E4 Wood frame | $10–20 | saw, drill, sandpaper | good with care | warm, one-off |

## E1 — Reuse the original base cover (recommended)

FRU `04X5184` / `00HT389` / `0C64937` — the moulding itself is labelled `SCB0G39215` or
`AP0SX000I00`, and eBay listings use any of these — ~$22–25 used
([eBay 04X5184](https://www.ebay.com/itm/121981528885), [eBay SCB0G39215](https://www.ebay.com/itm/156310389262)). It is the laptop's own bottom shell: every
screw boss, clip and edge profile already matches the palmrest. **Zero CAD, zero
measuring.**

What you get for free: the rubber feet, the rear USB/port cutouts (one becomes the cable
exit), the mainboard standoffs (the board mounts on them), and the stock M2.5 screw set.

### Steps

1. **Strip it.** Remove any residual mainboard standoff screws, the fan duct, the battery
   latch mechanism and the battery-bay door. Keep the standoffs.
2. **Plan the board position.** The Rev A stripboard / Rev B PCB sits where the mainboard
   was, FPC connectors toward the keyboard's cable exit (front-centre of the deck). Mark
   which original standoffs line up with the board's M2 holes; the Rev B PCB is drilled to
   match at least three of them. For Rev A stripboard, drill to match.
3. **Clear the ribs.** A few internal ribs will foul the ZIF connectors or the Pico. Cut
   them flush with a rotary tool or flush cutters; the cover is thin ABS/PC and cuts easily.
   Cut less than you think — the deck's rigidity comes from the cover.
4. **USB exit.** Use an existing rear port opening (the old Ethernet or USB cutout). If
   the Pico's Micro-USB cannot reach, fit the optional USB-C breakout at the opening and
   wire TP1/TP2/TP3 (see [`../hardware/components.md`](../hardware/components.md)). Fit a
   cable-tie strain relief anchored to a standoff.
5. **Mount.** Adhesive M2 standoffs (or the original metal ones with M2.5→M2 adapters)
   under the board; keep ≥ 3 mm between the board's underside and the cover.
6. **Route the FFC.** Gentle S-curve, ≥ 5 mm radius; tape the extension to the cover so it
   cannot shift during closing.
7. **Close.** Deck face-down on a towel, cover on, original screws in the original holes.
   The stock rubber feet give the typing angle.
8. **Seal.** The original gasket is already there; add 1 mm foam only where light shows.

Serviceability is the stock laptop's: remove the screws and the cover lifts off.

## E2 — Laser-cut sandwich

A flat bottom plate plus perimeter spacer frames, stacked and bolted with M3 standoffs.

**Files.** `./dev build cad` writes them to `out/cad/`, all derived from the same solids
as the printed case by `cad/export_plates.scad` (`projection(cut = true)`), so the two
routes cannot drift apart:

| DXF | What | Material |
|---|---|---|
| `plate_bottom.dxf` | Floor outline with every hole: M3 at the deck bosses, M2 for the sled, light pipe, feet, tilt feet, reset | 3 mm cast acrylic **or** 1.5 mm 5052 aluminium |
| `plate_spacer.dxf` | Perimeter ring, `wall_t` wide, with the USB notch in the rear edge and the M3 holes | 3 mm acrylic × 6, or 12 mm plywood × 1, or 6 mm acrylic × 3 — whatever sums to `internal_h` (18 mm) |
| `plates_sheet.dxf` | Bottom + spacer + box insert on one sheet | one upload |

**Order.** Upload the DXF to [SendCutSend](https://sendcutsend.com/) (aluminium, acrylic)
or [Ponoko](https://www.ponoko.com/) (acrylic, plywood); both quote instantly. Outlines are
nominal — the service applies kerf. Budget $30–60 for a bottom plate and six acrylic rings.

**Hardware.** 8 × M3 × 20 mm F-F standoffs (or 8 × M3 × 25 mm bolts + nuts), 8 × M3 × 6 mm
screws into the deck's bosses from below, M2 × 6 mm for the sled, 4 rubber feet.

**Stack**, bottom to top: plate → rings (2–3 mm foam tape between the top ring and the
deck as the gasket) → deck. The sled bolts to the plate through its four M2 holes; the USB
cable leaves through the notch, with a cable tie through two extra 4 mm holes you drill
20 mm inboard.

Acrylic shows the electronics; aluminium is stiffer and can be bonded to the board's GND
through one standoff. Both need feet.

## E3 — Hammond sloped console

[Hammond 515-0950](https://www.hammfg.com/electronics/small-case/general-purpose/500-515-519)
— 300 × 200 × 58 mm steel/aluminium sloped-front console, ~$50–60. The X240 deck is
309 × 210 mm, so it **overhangs 4–5 mm per side**; that is acceptable — the deck's own
edge hides the console's edge.

1. **Mark** the opening on the console's top panel: print `plate_spacer.dxf` at 1:1 (or
   trace the deck) and draw the outline **5 mm inboard** all round. Mark the 8 boss
   positions from `params.scad` (`deck_boss_positions`).
2. **Cut** the opening with a nibbler or a jigsaw (fine metal blade), file the edge,
   deburr. Keep the cut-out panel — it becomes a template for the gasket foam.
3. **Drill** the 8 boss holes at 3.5 mm in the remaining lip; countersink from below.
4. **Mount** the board on adhesive M2 standoffs on the console floor, rear-centre, with
   the USB cable to a rear grommet (`cable_d` 4.5 mm → 6 mm grommet hole).
5. **Fit** the deck: foam tape on the lip, deck down, M3 screws from below into the bosses.

The sloped front gives a wrist-friendly angle; the spare internal height is harmless.

## E4 — Wood frame

A 6 mm plywood base with a hardwood perimeter, height `internal_h` (18 mm) so the stack
matches the printed case.

**Cut list** (finished sizes; mitre the strips at 45° or butt-join and plug):

| Piece | Size | Qty |
|---|---|---|
| Base, 6 mm birch ply | 309 × 210 | 1 |
| Side strip, hardwood 18 × 12 | 210 long | 2 |
| Front/back strip, hardwood 18 × 12 | 309 long (285 inside the sides if butt-joined) | 2 |
| Rear strip USB notch | 15 wide × 10 deep, centred on `usb_x` | — |

**Sequence.** Cut the base square (check diagonals). Glue and pin the strips flush with
the base edge, USB notch cut first. Clamp, cure, sand to 180, break the edges. Finish
(oil is forgiving; lacquer is harder). Drill the 8 boss positions through the base at
2.5 mm (print `plate_bottom.dxf` 1:1 as the template) and countersink from below. Fit
rubber feet at `foot_positions`.

**Mount.** Board on adhesive M2 standoffs; cable tie through two 4 mm holes for strain
relief; foam tape on the frame's top edge; deck on; M2 × 12 mm screws with washers up
into the bosses.

## Common to all hand-made variants

- Keep the FFC bend radius ≥ 5 mm. A printed cable guide is nice; a loop of tape around a
  10 mm dowel does the same job.
- Put the strain relief on the **cable**, not the connector: a cable tie through two holes
  in the base next to the exit.
- Probe, wire and flash on the bench **before** closing any enclosure. Opening a glued wood
  frame is not fun.

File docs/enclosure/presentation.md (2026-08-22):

---
title: Assembly and presentation
parent: Enclosure
nav_order: 5
---

# Assembly ergonomics and the presentation box

## Order of operations

Things become unreachable in this order, so do them in this order.

1. **Bench-test everything open.** Probing, wiring, firmware, every key, ClickPad,
   TrackPoint, backlight, power button — on the bench, case nowhere in sight. Nothing
   below this line should be the first time the electronics are powered.
2. **Prepare the enclosure.** Printed: inserts, dovetail join, pins, sled. E1: strip, clear
   ribs, choose standoffs. E2–E4: assemble the shell.
3. **Fit strain relief and guides** while the case is empty and you can see both sides.
4. **Mount the board on its sled / standoffs.** Pico socketed, USB toward the exit.
5. **Connect the ClickPad FPC** (short; it only reaches from one position), lock the ZIF.
6. **Connect the keyboard FFC extension** to the board, lock it, route through the guides.
7. **Plug in and re-test** with the deck lying beside the case. Last chance to fix a wire.
8. **Connect the keyboard's own tail** to the extension, lay the deck on, check nothing is
   pinched by looking along the seam with a torch.
9. **Screw the deck down** in a star pattern, finger-tight plus a quarter turn. PETG
   inserts strip if you lean on them.
10. **Gasket, feet, light pipe.** Cosmetic last.
11. **Final test on three OSes**, then flash the release firmware.

## Teardown

Reverse 9 → 4. The only consumable is the foam gasket; the only thing to be careful of is
lifting the deck straight up so the keyboard's tail is not bent at the ZIF.

## Torque and fit notes

- M2 into heat-set inserts: hand-tight only. Never a powered driver.
- M2.5 originals on E1: the same screws the laptop used, same torque (light).
- ZIF tabs: they are hinged, not sprung — lift to ~45°, do not pry.
- Dovetail: should slide with thumb pressure; if it needs a mallet the clearance is wrong,
  fix the parameter, do not force it.

## Presentation box

For handing the finished keyboard to someone, or for the shelf.

| Item | Spec |
|---|---|
| Outer box | Two-piece rigid cardboard ("shoulder box"), internal **330 × 230 × 60 mm** (deck 309 × 210 + 5 mm foam margin + 5 mm clearance; 20.5 mm case + 20 mm foam + lid). Stock mailer boxes near 330 × 230 × 60 exist from packaging suppliers. |
| Insert | 20 mm EVA or PE foam cut to `out/cad/box_insert.dxf` — the deck outline plus 5 mm, with a 60 × 40 mm pocket for the coiled cable and a 105 × 74 mm pocket for the A6 card. Laser-cut by the same service as the plates, or hot-knife it from the DXF printed 1:1. |
| Cable | 1.5 m USB-A to Micro-USB (or USB-C), coiled with a velcro tie |
| Label | [`../presentation/label.svg`](../presentation/label.svg) — 60 × 40 mm: name, firmware version, FN legend, repository URL. Print on matte adhesive stock. |
| Quick-start card | [`../presentation/quick-start-card.md`](../presentation/quick-start-card.md) — A6, two sides; print from the site or any Markdown renderer at 100 %. |

## What to tell the recipient

- It is a USB HID device: no drivers, works on anything with a USB host, including a phone
  with an OTG adapter.
- The power button sends the system's power/sleep key after a half-second hold.
- The firmware is open; updates are a UF2 file dragged onto a drive.

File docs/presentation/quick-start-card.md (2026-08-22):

---
title: Quick-start card
parent: Enclosure
nav_order: 6
---

# Quick-start card (A6, two sides)

Print at 100 % on card stock; fold nothing. Side 1 faces up in the box.

---

## Side 1 — plug in

**x240-kbd** — a ThinkPad X240 keyboard, ClickPad and TrackPoint as one USB device.

1. Plug the USB cable into any computer, phone or tablet with a USB host. No drivers:
   it enumerates as a keyboard + mouse.
2. Type. The **ClickPad** moves the cursor; its bottom corners are left/right click.
3. Push the **red stick** for the TrackPoint. Rest your finger on it lightly — it measures
   force, not travel.
4. **Power button:** hold ½ s for the system's power/sleep dialog. A tap does nothing.

**FN layer** (hold FN):

| | | | |
|---|---|---|---|
| F1 mute | F2 vol − | F3 vol + | F4 mic mute |
| F5 bright − | F6 bright + | F7 display | F8 wireless |
| F9 settings | F10 bluetooth | **F11 backlight** | F12 print screen |
| PgUp home | PgDn end | ← prev track | → next track |
| **Esc = FN lock** | | | |

---

## Side 2 — keep it working

**Firmware updates.** Hold **Esc** while plugging in (or press the reset hole on the
underside with BOOTSEL held). A drive named `RPI-RP2` appears; drag the new `.uf2` onto
it. The keyboard restarts by itself. Firmware and instructions:
`github.com/nikolareljin/x240-kbd`

**Cursor too fast or slow?** That is a firmware constant
(`SYN_TOUCHPAD_DIVISOR`, `SYN_TRACKPOINT_MULT`); rebuild and update as above.

**Opening it.** Deck screws out from below, lift the deck straight up, unlatch the two
ribbon-cable tabs. Nothing is glued.

**Don't.** Bend the ribbon cables tighter than a 5 mm radius. Pull the cable by the plug.
Run it from a USB hub that cannot supply 500 mA if the backlight is on.

Built ________ · serial ________ · GPL-2.0

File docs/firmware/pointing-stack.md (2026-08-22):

---
title: Pointing stack
parent: Firmware
nav_order: 3
---

# Pointing stack — ClickPad and TrackPoint

Hardware background: [`../hardware/trackpoint.md`](../hardware/trackpoint.md).
Protocol: Synaptics *TouchPad Interfacing Guide* (PN 511-000275; no longer hosted publicly — the working reference is the Linux driver [`drivers/input/mouse/synaptics.c`](https://github.com/torvalds/linux/blob/master/drivers/input/mouse/synaptics.c));
reference implementation: Linux `drivers/input/mouse/synaptics.c`.

## Layers

```
QMK vendor PS/2 driver  (PIO0, GP21/GP22)     — bytes in, commands out
        │
synaptics.c                                   — identify, mode, 6-byte packet parser
        ├──► touchpad path   → dx, dy, buttons   (scaled, Y inverted once)
        └──► trackpoint.c    → dx, dy, buttons   (from W == 3 guest frames)
                    │
        both add into one report_mouse_t inside pointing_device_driver_get_report()
                    │
x240_pico.c : pointing_device_task_kb()       — pass-through, no pointing logic
```

`synaptics.c` is QMK's **custom pointing-device driver** (`POINTING_DEVICE_DRIVER =
custom`): it implements `pointing_device_driver_init()` and
`pointing_device_driver_get_report()` on the PS/2 host API — `ps2_host_init()`,
`ps2_host_send(uint8_t)` (returns the ACK), `ps2_host_recv_response()` (blocking, 100 ms),
`ps2_host_recv()` + `pbuf_has_data()` (buffered, non-blocking), and `ps2_error`. QMK's own
`ps2_mouse.c` is compiled out (`PS2_MOUSE_ENABLE = no`) because it only understands 3-byte
packets and would consume the same receive queue.

## Initialisation (`pointing_device_driver_init()`, called by QMK at startup)

1. `ps2_host_init()`; send `0xFF` reset, expect `0xFA 0xAA 0x00`.
2. **Identify.** `synaptics_query(0x00)`: send `0xE8 0x00`, `0xE8 0x00`, `0xE8 0x00`,
   `0xE8 0x00` — wait, the query number is split across the four `SetResolution` values —
   then `0xE9`. Read three bytes. Byte 1 == `0x47` ⇒ Synaptics. Otherwise **fallback**.
3. **Capabilities.** `synaptics_query(0x02)`; note the `PassThrough` bit and whether
   extended capabilities exist.
4. **Mode byte.** `0x80 | 0x40 | 0x01` (absolute, rate 80, W-mode). Write with the knock
   then `0xF3 0x14` (`SetSampleRate 20`).
5. **Pass-through.** If the capability bit is set, send the guest its own `0xF4` (enable
   streaming) *through* the pass-through: the byte in the special-sequence encoding
   followed by `0xF3 0x28` — rate `0x28` is the "to guest" marker (Linux
   `synaptics_pt_write`).
6. `0xF4` enable data reporting on the ClickPad itself.

Each step checks the `0xFA` ack. Any failure ⇒ `synaptics_fallback()`: re-init as a plain
PS/2 mouse (`0xFF`, `0xF4`), set `mode = RELATIVE`, and `dprintf("synaptics: identify failed,
relative mode, no TrackPoint\n")`. The touchpad works; the log says the TrackPoint does not.

## Packet parsing (`pointing_device_driver_get_report()`)

Read bytes into a 6-byte buffer. Frame alignment: byte 0 has bits `1 0 W3 W2 0 W1 R L`
(bit 7 set, bit 6 clear, bit 3 clear) and byte 3 has bits 7 and 6 set. Drop bytes until
both patterns hold — the same resync the Linux driver does.

```c
uint8_t w = ((b0 & 0x30) >> 2) | ((b0 & 0x04) >> 1) | ((b3 & 0x04) >> 2);
if (w == 3) {
    trackpoint_handle_guest(b1, b4, b5);          // standard PS/2 3-byte packet
} else {
    x = ((b3 & 0x10) << 8) | ((b1 & 0x0F) << 8) | b4;
    y = ((b3 & 0x20) << 7) | ((b1 & 0xF0) << 4) | b5;
    z = b2;                                       // pressure
    touchpad_handle_abs(x, y, z, w, b0 & 0x01, b0 & 0x02);
}
```

The touchpad path converts absolute coordinates to a delta: keep the previous (x, y) while
`z` is above the touch threshold, emit `dx = x − x_prev`, reset when the finger lifts.
Scale by `SYN_TOUCHPAD_SCALE`. Ignore frames with `w` values that indicate palm or
multi-finger if they cause jumps.

## TrackPoint (`trackpoint.c`)

Guest frames carry a standard PS/2 mouse packet:

```
b1: Yo Xo Ys Xs 1 M R L        (overflow, sign, always-1, buttons)
b4: X delta (8 bits, sign from Xs)
b5: Y delta (8 bits, sign from Ys)
```

Decode exactly as `ps2_mouse.c` does, then scale by `SYN_TRACKPOINT_SCALE`. Sign convention:
PS/2 Y is positive-up, HID is positive-down — invert Y once, here, and nowhere else.

## Merge

Both decoders add into the same `report_mouse_t` inside `get_report()`: deltas are summed
and clamped to the HID range, buttons are OR-ed. `pointing_device_task_kb()` in
`x240_pico.c` is a pass-through.

Both sources rarely move in the same scan; summing is simplest and feels right. Buttons are
OR-ed: the ClickPad's zones and the guest's buttons (if the module reports any) all count.

## Tuning constants

| Constant | Start | Tune by |
|---|---|---|
| `SYN_TOUCHPAD_DIVISOR` | 8 (absolute units are ~0–6000) | cursor should cross a 1080p screen in one comfortable swipe |
| `SYN_TRACKPOINT_MULT` | 1 | faster stick |
| `SYN_TRACKPOINT_DEADZONE` | 0 | slow drift when resting a finger ⇒ set 1 or 2, not lower scale |
| `SYN_TOUCH_THRESHOLD` | 30 | lower if light touches are missed |
| `SYN_INVERT_Y` | undefined | define if the cursor goes up when you push down |

## Test checklist (M4)

- Identify succeeds: console shows `synaptics: id=0x47 …`, not the fallback line.
- Finger on pad moves cursor; bottom corners click L/R.
- Stick deflection moves cursor **with no finger on the pad** — this is the proof the
  pass-through works.
- Disconnect the TrackPoint (or cover the stick) — touchpad still works.
- Power-cycle ten times; every boot identifies. If not, the init sequence has a timing
  hole — add a delay after reset before the knock.

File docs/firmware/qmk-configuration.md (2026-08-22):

---
title: QMK configuration
parent: Firmware
nav_order: 2
---

# QMK configuration reference

Every setting, what it does, where it is documented upstream, and — where the earlier plan
had it wrong — what changed and why.

## `rules.mk`

| Setting | Value | Upstream | Notes |
|---|---|---|---|
| `MCU` | `RP2040` | [RP2040 platform](https://docs.qmk.fm/platformdev_rp2040) | |
| `BOOTLOADER` | `rp2040` | same | UF2 drag-and-drop via BOOTSEL |
| `BOOTMAGIC_ENABLE` | `yes` | [Bootmagic](https://docs.qmk.fm/features/bootmagic) | Hold top-left key at plug-in → bootloader |
| `EXTRAKEY_ENABLE` | `yes` | [Keycodes](https://docs.qmk.fm/keycodes) | Media and system keys (`KC_SYSTEM_POWER`) |
| `MOUSEKEY_ENABLE` | `yes` | [Mouse keys](https://docs.qmk.fm/features/mouse_keys) | Optional; the pointing device does not need it |
| `NKRO_ENABLE` | `yes` | [NKRO](https://docs.qmk.fm/keycodes_magic) | `features.nkro` in keyboard.json; on by default via `host.default.nkro` (`FORCE_NKRO` is deprecated) |
| `CUSTOM_MATRIX` | `lite` | [Custom matrix](https://docs.qmk.fm/custom_matrix) | **Changed** — the 74HC165 chain needs `matrix_scan_custom()` |
| `SRC` | `+= matrix.c synaptics.c trackpoint.c` | | **Changed** — new sources |
| `CONSOLE_ENABLE` | `yes` | [Debugging](https://docs.qmk.fm/faq_debug) | bring-up: `synaptics.c` logs identify/fallback via `dprintf` |
| `POINTING_DEVICE_ENABLE` | `yes` | [Pointing device](https://docs.qmk.fm/features/pointing_device) | |
| `POINTING_DEVICE_DRIVER` | `custom` | same | **Changed from `ps2`** — see below |
| `PS2_MOUSE_ENABLE` | `no` | [PS/2 mouse](https://docs.qmk.fm/features/ps2_mouse) | **Changed from `yes`** — `ps2_mouse.c` would fight `synaptics.c` for the bus |
| `PS2_ENABLE` | `yes` | same | |
| `PS2_DRIVER` | `vendor` | same | **Changed from `usart`** — see below |
| `BACKLIGHT_ENABLE` | `yes` (backlit keyboards only) | [Backlight](https://docs.qmk.fm/features/backlight) | |
| `BACKLIGHT_DRIVER` | `software` | same | **Changed from `timer`** — see below |
| `LTO_ENABLE` | `yes` | | Smaller binary |

### Why `POINTING_DEVICE_DRIVER = custom`

QMK's `ps2_mouse.c` (what `POINTING_DEVICE_DRIVER = ps2` compiles in) assembles **3-byte
relative packets** and nothing else. The TrackPoint arrives inside 6-byte Synaptics
absolute packets, so the ClickPad has to be driven in absolute + W mode by our own code.
Two consumers cannot share one PS/2 receive queue, so `PS2_MOUSE_ENABLE = no` and
`synaptics.c` implements the custom pointing-device driver
(`pointing_device_driver_init/get_report/get_cpi/set_cpi`) directly on the PS/2 host API
(`ps2_host_init`, `ps2_host_send`, `ps2_host_recv`, `ps2_host_recv_response`,
`pbuf_has_data`). `PS2_ENABLE = yes` still pulls in the RP2040 PIO host driver.

### Why `PS2_DRIVER = vendor`

QMK's PS/2 page lists four drivers: `busywait` (any MCU, jerky), `interrupt` (AVR + ARM
ChibiOS), `usart` (**ATmega32u4 only**, fixed to PD5/PD2), and `vendor` — which on RP2040
is the **PIO implementation**. The earlier plan chose `usart` on the belief that it mapped
to an RP2040 UART. It does not; the build fails. The PIO driver is the intended RP2040 path.

The PIO driver has one hard rule: **the clock GPIO must be the data GPIO + 1.**
Hence DATA = GP21, CLK = GP22. The earlier `config.h` had them the other way round.

Optional: `#define PS2_PIO_USE_PIO1` moves the state machine to PIO1. Reserved for the
second-instance TrackPoint fallback.

### Why `BACKLIGHT_DRIVER = software`

`pwm` does not compile on RP2040 ([QMK #24470](https://github.com/qmk/qmk_firmware/issues/24470)).
`timer` is documented for AVR and STM32. `software` is the workaround the issue itself
records and is what we use. Detail in [`../hardware/backlight.md`](../hardware/backlight.md).

## `keyboard.json`

```json
{
  "keyboard_name": "X240 Pico",
  "manufacturer": "Custom",
  "url": "https://github.com/nikolareljin/x240-kbd",
  "maintainer": "nikolareljin",
  "usb": { "vid": "0x6E6B", "pid": "0x0240", "device_version": "0.2.0" },
  "processor": "RP2040",
  "bootloader": "rp2040",
  "features": { "bootmagic": true, "extrakey": true, "mousekey": true, "nkro": true },
  "bootmagic": { "matrix": [0, 0] },
  "ps2": {
    "enabled": true,
    "mouse_enabled": false,
    "driver": "vendor",
    "data_pin": "GP21",
    "clock_pin": "GP22"
  },
  "matrix_size": { "rows": 10, "cols": 24 },
  "layouts": { "LAYOUT": { "layout": [ "...generated from the measured matrix..." ] } }
}
```

- **No `matrix_pins`.** With `CUSTOM_MATRIX = lite` the pins live in `config.h` and
  `matrix.c`. Leaving `matrix_pins` in causes QMK to also generate the default scanner.
- `matrix_size` is the chain's capacity (10 drive × 24 sense) until probing sets the real
  numbers; unused cells are `KC_NO`.
- `vid`/`pid` are placeholders in a vendor-less range; do not ship them in a product that
  could collide — see the [QMK VID/PID guidance](https://docs.qmk.fm/hardware_keyboard_guidelines).

## `config.h`

| Define | Value | Purpose |
|---|---|---|
| `DEBOUNCE` | `5` | ms, QMK default algorithm |
| `MATRIX_IO_DELAY` | `30` | µs settle after driving a line LOW, before `PL` |
| `MATRIX_DRIVE_PINS` | `{ GP0, …, GP9 }` | drive lines, consumed by `matrix.c` |
| `SENSE_PL_PIN` | `GP17` | 74HC165 parallel-load latch, driven by `matrix.c` |
| `SENSE_CHAIN_BYTES` | `3` | 3 × 74HC165 = 24 sense lines; `MATRIX_COLS` must equal 8 × this |
| `SPI_DRIVER` / `SPI_SCK_PIN` / `SPI_MISO_PIN` / `SPI_MOSI_PIN` | `SPID0` / `GP18` / `GP16` / `NO_PIN` | QMK SPI master on RP2040 SPI0; `halconf.h` sets `HAL_USE_SPI`, `mcuconf.h` sets `RP_SPI_USE_SPI0` |
| `SENSE_SPI_DIVISOR` | `16` | ≈7.8 MHz on the 125 MHz peripheral clock |
| `SYN_TOUCHPAD_DIVISOR` | `8` | absolute units per HID count |
| `SYN_TOUCH_THRESHOLD` | `30` | Z above this = finger down |
| `SYN_TRACKPOINT_MULT` / `SYN_TRACKPOINT_DEADZONE` | `1` / `0` | TrackPoint scaling and drift guard |
| `SYN_INVERT_Y` | undefined | define if vertical motion is reversed |
| `POINTING_DEVICE_TASK_THROTTLE_MS` | `1` | drain the PS/2 queue every millisecond |
| `BACKLIGHT_PIN` | `GP26` | |
| `BACKLIGHT_LEVELS` | `5` | |
| `BACKLIGHT_BREATHING` | **not defined** | the software PWM driver errors out on it |
| `POWER_BUTTON_PIN` | `GP27` | active LOW, internal pull-up |
| `POWER_BUTTON_HOLD_MS` | `500` | long-press guard |
| `TOUCHPAD_LED_PIN` | `GP28` | HIGH = on |
| *(keyboard.json `host.default.nkro`)* | `true` | NKRO on at boot; replaces the deprecated `FORCE_NKRO` |
| *(keyboard.json `bootmagic.matrix`)* | `[0, 0]` | top-left key enters the bootloader at plug-in |

**Removed:** the comment claiming GP21/GP22 are "UART0 CTS/TX / RX". On the RP2040, UART0
is on GP0/1, GP12/13 or GP16/17 and UART1 on GP4/5, GP8/9 or GP20/21. GP21/GP22 is not a
UART pair and the PIO driver does not use one anyway.

## Custom keycodes

| Keycode | Action |
|---|---|
| `CK_BKLT` | `backlight_step()` — FN + F11 |
| `CK_FNLK` | `layer_invert(_FN)` — FN + Esc, FN Lock |

The power button is **not** a keycode; `matrix_scan_kb()` polls GP27 and sends
`KC_SYSTEM_POWER` after a ≥ 500 ms hold.

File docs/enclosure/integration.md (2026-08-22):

---
title: Mechanical integration
parent: Enclosure
nav_order: 3
---

# Mechanical integration

How every part fits inside the closed assembly. Numbers marked *measured* are filled in
from caliper measurements of the real X240 top section (issue #44); until then they are
design targets.

## Vertical stack (bottom to top)

| Layer | Height | Notes |
|---|---|---|
| Case floor (printed) / base cover (E1) | 2.5 mm | PETG wall; E1 is ~1.2 mm ABS |
| Standoff under the board | 6.0 mm | M2 brass or adhesive |
| Board (stripboard or PCB) | 1.6 mm | |
| Tallest component above the board | 5.0 mm | ZIF connector body on Rev A breakouts ≈ 5 mm; socketed Pico ≈ 8.5 mm on 2 × 20 headers — **the Pico is the tallest item** |
| Clearance to the deck's underside | ≥ 2.0 mm | deck has ribs and the keyboard's own backplate |
| **Internal height needed** | **≈ 18 mm** | matches `internal_h = 18.0` in `bottom_case.scad` |

If the Pico's height is the problem, mount it on low-profile (4.3 mm) headers or solder it
directly to the Rev B board (drops ~4 mm).

## Plan view

Internal layout and stack

```
            309 mm
 ┌──────────────────────────────────────────────┐  ← rear edge: USB exit, tilt feet
 │  ○                ○                ○          │  ← rear bosses (measured)
 │                                               │
 │   ┌───────────────────────┐                  │
 │   │ board 100 × 80        │  ← PICO at rear  │
 │   │ [ZIF 40] [ZIF tp]     │     edge, USB    │
 │   └───────────────────────┘     facing out   │
 │         ║ FFC 150 mm, S-curve                │  210 mm
 │         ║ ≥5 mm radius                       │
 │  ○      ╨        ○ keyboard FPC exit   ○     │  ← front-centre: the keyboard's cable exits the deck here
 │                      ClickPad FPC exit        │
 └──────────────────────────────────────────────┘
            front edge: rubber feet recesses
```

- The board sits **rear-centre** so the Pico's USB faces the rear wall and the FFC from the
  front-centre keyboard exit runs straight back with one gentle S-curve.
- The ClickPad's short FPC reaches the board's front edge directly; no extension needed.
- The TrackPoint needs no routing — it rides the ClickPad's cable.

## Cable routing rules

- Keyboard FFC: 150 mm extension, ≥ 5 mm bend radius everywhere, **two** printed guides
  (or taped loops) so it cannot migrate into the dovetail seam.
- Never let an FFC edge rest on a screw head or a cut rib — that is where cracks start.
- Tape the extension to the floor at one point only, so thermal movement has somewhere to go.

## Screw and boss plan

- Case-to-deck: the X240's own boss positions (8, *measured*) with M2 screws into heat-set
  inserts (printed) or the original threads (E1).
- Board-to-case: 4 × M2 through the sled into case bosses; on E1, 3 × M2 into original
  mainboard standoffs.
- Sled across the seam: 2 × M2 per half — the sled is the structural bridge.
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

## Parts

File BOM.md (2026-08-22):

# Bill of materials

The priced, tiered BOM with part numbers and links lives at
**[`docs/hardware/bom-and-cost.md`](docs/hardware/bom-and-cost.md)**; the part-by-part
reference with datasheets is **[`docs/hardware/components.md`](docs/hardware/components.md)**.

## Totals (USD, August 2026)

| Build | All-in |
|---|---|
| Rev A perfboard + your own 3D printer | **$90–130** |
| Rev A perfboard + reused X240 base cover (no printer) | **$110–150** |
| Rev A + commercial print service | $115–170 |
| Rev B PCB | add $25–35 |
| Tools, once, if starting from nothing | add $75–135 |

Earlier revisions quoted $25–35; that omitted the donor keyboard and palmrest.

## Tiers

- **A. Donor** — X240 keyboard `0C44020` (or backlit `04X0177`), palmrest + ClickPad `00HT393`.
- **B. Rev A electronics** — Pico, 40-pin and ClickPad ZIF breakouts, 150 mm FFC extension,
  3 × `SN74HC165N`, 3 × 10 kΩ SIP networks, MOSFET, resistors, 100 nF, stripboard, headers,
  M2 hardware, wire, gasket.
- **C. Rev B PCB** — JLCPCB/PCBWay board, Hirose `FH12-40S-0.5SH(55)` + ClickPad FH12,
  SSOP 74HC165, SMD passives.
- **D. Printed enclosure** — ~150 g PETG, M2 heat-set inserts.
- **E. Hand-made enclosure** — X240 base cover `04X5184` (recommended), or laser-cut
  plates, Hammond 515-0950, or wood.
- **F. Tools** — calipers, iron, multimeter, logic analyser, hand tools.

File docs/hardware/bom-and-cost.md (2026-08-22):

---
title: BOM and cost
parent: Hardware
nav_order: 2
---

# Bill of materials and cost estimate

All prices are **USD street prices observed in August 2026** and will drift. Part numbers
and datasheets are in [`components.md`](components.md).

An earlier revision of this project quoted **$25–35 total**. That figure left out the donor
keyboard and palmrest, which are the largest single cost. The honest range is below.

## Totals at a glance

| Build path | All-in |
|---|---|
| Rev A perfboard + your own 3D printer | **$90–130** |
| Rev A perfboard + reused X240 base cover (hand-made route E1, no printer) | **$110–150** |
| Rev A perfboard + commercial print service | $115–170 |
| Rev B PCB instead of perfboard | add $25–35 to any row |
| Tools, if starting from nothing | add $75–135, once |

---

## A. Donor hardware — every build

| Part | FRU / spec | Qty | Est. | Source |
|---|---|---|---|---|
| X240 keyboard, US, with TrackPoint | `0C44020` non-backlit · `04X0177` backlit | 1 | $20–35 | [eBay](https://www.ebay.com/itm/387219786805), Amazon |
| X240 palmrest with ClickPad | `00HT393` (no FPR) · `00HT392` (FPR) | 1 | $20–40 | [eBay](https://www.ebay.com/p/1361311702), [iFixit](https://www.ifixit.com/products/00ht393-lenovo-thinkpad-x240-palmrest-touchpad-without-fpr) |
| *or* palmrest + keyboard + ClickPad as one used assembly | | 1 | $36–80 | eBay |
| **Subtotal** | | | **$45–75** | |

Buy the backlit keyboard variant only if you want the backlight; the non-backlit `0C44020`
has no LED strip and the backlight circuit is simply left unpopulated.

---

## B. Controller and electronics — Rev A perfboard

| Part | Spec | Qty | Est. | Source |
|---|---|---|---|---|
| Raspberry Pi Pico | RP2040, Micro-USB | 1 | $4 | [raspberrypi.com](https://www.raspberrypi.com/products/raspberry-pi-pico/) |
| *(alt)* Raspberry Pi Pico 2 | RP2350 — verify QMK PS/2 PIO support first | 1 | $5 | [Pico 2 launch](https://www.raspberrypi.com/news/raspberry-pi-pico-2-our-new-5-microcontroller-board-on-sale-now/) |
| 40-pin 0.5 mm FPC → DIP breakout, with ZIF | bottom contact | 1 | $3–5 | [Tinkersphere](https://tinkersphere.com/cables-wires/3608-40-pin-05mm-1mm-pitch-fpc-to-dip-breakout.html), [Amazon 2-pk](https://www.amazon.com/40-Pin-Connector-Breakout-Board-0-5mm/dp/B00XSC2G4A) |
| 8–12-pin 0.5 mm FPC → DIP breakout | ClickPad, count your cable first | 1 | $2.70 | [Tinkersphere](https://tinkersphere.com/cables-wires/3616-8-pin-05mm-1mm-pitch-fpc-to-dip-breakout.html) |
| 40-pin 0.5 mm FFC extension, 150 mm | | 1 | $2–4 | [BuyDisplay](https://www.buydisplay.com/150mm-length-40-pins-0-5mm-pitch-bottom-contact-ffc-fpc-flex-cable-4579) |
| 74HC165 shift register, DIP-16 | `SN74HC165N` | 3 | $4.26 | [DigiKey](https://www.digikey.com/en/products/detail/texas-instruments/SN74HC165N/376966) |
| 10 kΩ bussed SIP resistor network, 9-pin | sense pull-ups | 3 | ~$1 | [Jameco](https://www.jameco.com/c/Network-SIP-Resistors.html) |
| N-channel MOSFET | `BS170` TO-92 (or `2N7002`) | 2 | ~$0.50 | DigiKey / Mouser |
| Resistors 4.7 kΩ, 10 kΩ, 100 kΩ, 100 Ω | ¼ W | assorted | ~$1 | any |
| 100 nF ceramic capacitors | X7R | 6 | ~$0.50 | any |
| 1N4148 diodes | **only if the three-key test shows ghosting** | 100 | ~$2 | any |
| Stripboard ≈100 × 80 mm | | 1 | $3–5 | [Vero](https://verotl.com/circuitboards/veroboards) |
| 2 × 20-pin female headers | socket for the Pico | 1 set | $1 | any |
| M2 standoff + screw kit | brass, 6 mm | kit | $6–8 | Amazon |
| 30 AWG wire-wrap wire | assorted colours | 1 | $8 | Amazon |
| 1 mm foam gasket tape | self-adhesive | ~1 m | $5 | craft store |
| **Subtotal** | | | **$40–50** | |

---

## C. Rev B PCB increment

Replaces the two breakouts, the stripboard and the wire. Everything else in B is still needed.

| Part | Spec | Qty | Est. | Source |
|---|---|---|---|---|
| 2-layer PCB ≈100 × 80 mm, 5 pcs | JLCPCB / PCBWay | 1 order | $2 + $15–25 shipping | JLCPCB |
| 40-pin 0.5 mm ZIF, bottom contact | Hirose `FH12-40S-0.5SH(55)` | 1 | $2.70 | [DigiKey](https://www.digikey.com/en/products/detail/hirose-electric-co-ltd/FH12-40S-0-5SH-55/1110328) |
| ClickPad ZIF, 0.5 mm | Hirose `FH12-nnS-0.5SH(55)`, `nn` from probing | 1 | ~$1.45 | DigiKey |
| 74HC165, SSOP/TSSOP | `SN74HC165DBR` / `74HC165PW` | 3 | $1.35 | [DigiKey](https://www.digikey.com/en/products/detail/texas-instruments/SN74HC165DR/377068) |
| SMD passives and 4 × 0603 resistor arrays | | — | ~$2 | LCSC |
| **Subtotal** | | | **$25–35** | |

---

## D. Enclosure route 1 — 3D printed

| Item | Est. | Note |
|---|---|---|
| PETG, 120–180 g of a $20–25 spool | $4–6 | Bottom case printed as **two halves** plus seven small parts — see [`../enclosure/printed.md`](../enclosure/printed.md) |
| M2 × 3 mm heat-set inserts | $5 | |
| *(no printer)* commercial print of the split case | $25–45 | Craftcloud, JLC3DP; the split is what makes a 309 mm case quotable |

---

## E. Enclosure route 2 — hand-made, no printer

Full detail in [`../enclosure/handmade.md`](../enclosure/handmade.md).

| Variant | Est. | Note |
|---|---|---|
| **E1 Reuse the original X240 base cover** — recommended | $22–25 | FRU `04X5184` / `00HT389`, labelled `SCB0G39215` / `AP0SX000I00` on the part. Already mates to the palmrest with the stock screw bosses; gut it, mount the board on adhesive standoffs, cut a rear USB slot. No CAD at all. [eBay](https://www.ebay.com/itm/121981528885) |
| E2 Laser-cut acrylic / aluminium sandwich | $30–60 | Plates exported from the same OpenSCAD source; cut by [SendCutSend](https://sendcutsend.com/) or [Ponoko](https://www.ponoko.com/) |
| E3 Off-the-shelf sloped console | $50–60 | [Hammond 515-0950](https://www.hammfg.com/electronics/small-case/general-purpose/500-515-519), 300 × 200 × 58 mm; the 309 mm deck overhangs 9 mm |
| E4 Plywood base + hardwood frame | $10–20 | Saw, drill, finish |

---

## F. Tools — one-time, if not owned

| Tool | Est. |
|---|---|
| Digital calipers | $15–20 |
| Temperature-controlled soldering iron + fine tip | $25–60 |
| Multimeter with diode mode | $15–25 |
| 8-channel USB logic analyser (FX2 clone) | $10–15 |
| Flush cutters, tweezers, flux, solder wick | $10–15 |
| **Total** | **$75–135** |

OpenSCAD and KiCad are free.

---

## Where to buy

- **DigiKey / Mouser** — 74HC165, MOSFETs, Hirose connectors, resistor networks, passives.
- **Tinkersphere / Amazon / AliExpress** — FPC ZIF breakouts, FFC extensions (AliExpress is
  cheapest and slowest).
- **raspberrypi.com approved resellers, Adafruit, Pimoroni** — Pico.
- **eBay / iFixit** — donor keyboard, palmrest, base cover.
- **JLCPCB / PCBWay** — Rev B board; **LCSC** for its SMD parts in the same order.

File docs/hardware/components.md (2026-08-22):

---
title: Component reference
parent: Hardware
nav_order: 1
---

# Component reference

Every chip, connector, cable, tool and consumable used anywhere in this build, with the
document that specifies it and at least one place to buy it. If a part is mentioned in
another file and missing here, that is a bug in this file.

Prices are in [`bom-and-cost.md`](bom-and-cost.md). Wiring is in
[`../../hardware/wiring/wiring_diagram.md`](https://github.com/nikolareljin/x240-kbd/blob/main/hardware/wiring/wiring_diagram.md).

---

## Controller

### Raspberry Pi Pico (RP2040)

| | |
|---|---|
| Role | USB HID controller: scans the matrix, hosts the PS/2 bus, drives backlight and LED |
| Package | 51 × 21 mm module, 2 × 20 castellated 0.1" header, Micro-USB |
| Exposed GPIO | 26 — GP0–GP22 and GP26–GP28 |
| Datasheet | [Pico datasheet](https://datasheets.raspberrypi.com/pico/pico-datasheet.pdf) · [RP2040 datasheet](https://datasheets.raspberrypi.com/rp2040/rp2040-datasheet.pdf) |
| Buy | [raspberrypi.com](https://www.raspberrypi.com/products/raspberry-pi-pico/) · Adafruit · Pimoroni · DigiKey |
| Why | Cheapest board with a PIO block, which is what makes a hardware PS/2 host possible in QMK on this family; QMK's RP2040 platform support is mature. |

USB-C breakout to Pico test pads

**USB test pads on the underside** — used by the optional USB-C upgrade:

| Pad | Signal |
|---|---|
| TP1 | **GND** |
| TP2 | **USB DM (D−)** |
| TP3 | **USB DP (D+)** |
| TP4 | GPIO23 / SMPS mode — do not use |
| TP5 | GPIO25 / LED — do not use |
| TP6 | BOOTSEL |

Earlier revisions of this repo said TP1 = D− and TP2 = D+. That is wrong and would short
ground onto D−; see [CHANGELOG](https://github.com/nikolareljin/x240-kbd/blob/main/CHANGELOG.md).

**Pico 2 (RP2350)** is pin-compatible and $1 more. Before substituting it, confirm QMK's
RP2350 support for the PS/2 PIO driver in the QMK version you are building with.

**Why not a bigger board?** The pin budget is solved with a shift register instead — see
[`gpio-budget.md`](gpio-budget.md).

---

## Logic

### 74HC165 — 8-bit parallel-in / serial-out shift register

| | |
|---|---|
| Role | Sense-line expander. Three cascaded devices read 24 matrix sense lines through 3 GPIO. |
| Part | Rev A: `SN74HC165N` (DIP-16). Rev B: `SN74HC165DBR` / `74HC165PW` (SSOP/TSSOP). |
| Supply | 2.0–6.0 V — runs at 3.3 V in spec |
| Datasheet | [Nexperia 74HC_HCT165](https://assets.nexperia.com/documents/data-sheet/74HC_HCT165.pdf) · [TI SN74HC165](https://www.ti.com/lit/ds/symlink/sn74hc165.pdf) |
| Buy | [DigiKey SN74HC165N](https://www.digikey.com/en/products/detail/texas-instruments/SN74HC165N/376966) · [DigiKey SN74HC165DR](https://www.digikey.com/en/products/detail/texas-instruments/SN74HC165DR/377068) · Nexperia 74HC165D at LCSC |
| Why | Reads in parallel, shifts out serially over SPI; a 24-bit chain reads in ~3 µs. No I²C address setup, no driver dependency, and the inputs tolerate up to 15 V. |

Gotchas that matter here: **HC inputs have no internal pull-ups** — every D0–D7 input needs
an external pull-up or it floats and reads random keys. Tie `CE` LOW. Tie the first
device's `DS` to a defined level. Details in [`shift-register-matrix.md`](shift-register-matrix.md).

### 10 kΩ bussed SIP resistor network, 9-pin

| | |
|---|---|
| Role | Pull-ups for the 74HC165 sense inputs — one 8-resistor network per chip |
| Part | Bourns 4609X-101-103LF or generic `A09-103` (9-pin, 8 × 10 kΩ, common pin 1) |
| Buy | [Jameco SIP networks](https://www.jameco.com/c/Network-SIP-Resistors.html) · DigiKey · Amazon kits |
| Why | Three parts instead of twenty-four discrete resistors on a perfboard. Rev B uses 4 × 0603 arrays instead. |

---

## Discrete semiconductors

### 2N7002 / BS170 — N-channel MOSFET

| | |
|---|---|
| Role | Low-side switch for the keyboard backlight LED strip, gate driven by GP26 |
| Package | 2N7002 = SOT-23 (Rev B). BS170 = TO-92 (Rev A, hand-solderable) |
| Ratings | 60 V, ~200–500 mA continuous, V<sub>GS(th)</sub> ≈ 1–2.5 V — turns on fully from a 3.3 V GPIO |
| Datasheet | [2N7002 (Nexperia)](https://assets.nexperia.com/documents/data-sheet/2N7002.pdf) · [BS170 (onsemi)](https://www.onsemi.com/pdf/datasheet/bs170-d.pdf) |
| Why | Logic-level threshold, cheap, and the strip (~100 mA on comparable ThinkPad arrays) is far below its rating. |

### 1N4148 — signal diode

| | |
|---|---|
| Role | Anti-ghosting diodes, **only if** the Phase 1 three-key test shows the keyboard lacks them |
| Package | DO-35 |
| Datasheet | [1N4148 (Vishay)](https://www.vishay.com/docs/81857/1n4148.pdf) |
| Why | Most ThinkPad membranes already include diodes; buy a 100-pack only after the test says so. Note that `BOM.md` once called these "Schottky" — they are ordinary silicon signal diodes. |

### Touchpad indicator LED

| | |
|---|---|
| Role | Shows the pointing device is active; driven by GP28 through 100 Ω |
| Part | Any 3 mm or 0805 LED, ~2 V forward, ≤ 20 mA. The X240 palmrest may already have one on the ClickPad FPC — probing decides. |

---

## Connectors and cables

### Keyboard FPC — 40-pin, 0.5 mm pitch

The X240 keyboard (FRU 0C44020) terminates in a 40-conductor 0.5 mm pitch FPC. Which of the
40 lines are matrix, power, backlight and power-button is **not documented by Lenovo** and is
established by probing — see [`../../hardware/pinout/probing_procedure.md`](https://github.com/nikolareljin/x240-kbd/blob/main/hardware/pinout/probing_procedure.md).

### 40-pin 0.5 mm FPC → DIP breakout **with ZIF connector** (Rev A)

| | |
|---|---|
| Role | Brings the keyboard FPC out to 0.1" pads on the perfboard |
| Buy | [Tinkersphere 40-pin 0.5/1 mm](https://tinkersphere.com/cables-wires/3608-40-pin-05mm-1mm-pitch-fpc-to-dip-breakout.html) · [Amazon 2-pack](https://www.amazon.com/40-Pin-Connector-Breakout-Board-0-5mm/dp/B00XSC2G4A) · [Crystalfontz (premium)](https://www.crystalfontz.com/product/cfabbcs050z40gb0-40-position-zif-breakout-board) |
| Check | **Contact side.** Breakouts come as top- or bottom-contact; the keyboard cable's contacts face one way. Buy a bottom-contact board or plan to use the FFC extension (below) to flip orientation. |

**About Adafruit #1436.** Earlier revisions of this repo listed it as "ZIF FPC to DIP
adapter". [Adafruit 1436](https://www.adafruit.com/product/1436) is a *multi-pitch
solder-pad adapter plate* — it has no ZIF connector. It works only if you solder a bare
FPC directly to it or fit your own connector. It is listed here so nobody buys it expecting a
socket.

### 8–12-pin 0.5 mm FPC → DIP breakout (Rev A)

| | |
|---|---|
| Role | Brings the ClickPad FPC out to 0.1" pads |
| Buy | [Tinkersphere 8-pin](https://tinkersphere.com/cables-wires/3616-8-pin-05mm-1mm-pitch-fpc-to-dip-breakout.html) · AliExpress 6/8/10/12-pin |
| Check | Pin count of the X240 ClickPad cable varies by revision — count yours before ordering. |

### 40-pin 0.5 mm FFC extension, 150 mm

| | |
|---|---|
| Role | Strain relief and orientation flip between the keyboard cable and the adapter inside the case |
| Buy | [BuyDisplay 150 mm 40-pin](https://www.buydisplay.com/150mm-length-40-pins-0-5mm-pitch-bottom-contact-ffc-fpc-flex-cable-4579) · DigiKey Molex/Würth FFC jumpers |
| Check | "Same-side" vs "opposite-side" contacts changes pin order (Type A vs Type D). Document which you bought in the pinout file. |

### Hirose FH12 0.5 mm ZIF connectors (Rev B PCB)

| | |
|---|---|
| Role | Board-mounted FPC sockets on the Rev B PCB |
| Parts | `FH12-40S-0.5SH(55)` — 40-pin bottom contact · `FH12-nnS-0.5SH(55)` for the ClickPad, `nn` from probing |
| Datasheet | [Hirose FH12 series](https://www.hirose.com/en/product/document?series=FH12&documenttype=Catalog&lang=en&documentid=D31648_en) |
| Buy | [DigiKey FH12-40S-0.5SH(55)](https://www.digikey.com/en/products/detail/hirose-electric-co-ltd/FH12-40S-0-5SH-55/1110328) · Mouser |
| Why | The de-facto standard 0.5 mm FPC socket; KiCad ships its footprint. |

### USB-C female breakout (optional)

| | |
|---|---|
| Role | USB-C port for the case, wired to the Pico's TP1/TP2/TP3 pads |
| Buy | Adafruit 4090 (USB-C breakout) · generic "USB-C female to 6-pin" boards with 5.1 kΩ CC pull-downs |
| Check | The breakout **must** have 5.1 kΩ on CC1 and CC2 or a USB-C host will not enable VBUS. |

---

## Donor parts

### ThinkPad X240 keyboard

| | |
|---|---|
| FRU | `0C44020` (US, non-backlit) · `04X0177` / `0C43982` (US, backlit) · `04Y0938` / `0C44711` (compatible X240/X250/X260 variants) |
| Contains | Key matrix, TrackPoint stick and its controller, power button, backlight on the backlit variants |
| Buy | [eBay 0C44020](https://www.ebay.com/itm/387219786805) · [Amazon compatible](https://www.amazon.com/Replacement-0C44711-04Y0938-Thinkpad-Keyboard/dp/B07WRK24XY) |
| Reference | [iFixit X240 keyboard replacement](https://www.ifixit.com/Guide/Lenovo+Thinkpad+X240+Keyboard+Replacement/118924) · [Lenovo X240 HMM](https://support.lenovo.com/us/en/manuals/um019141) |

### ThinkPad X240 palmrest with ClickPad

| | |
|---|---|
| FRU | `00HT393` (no fingerprint reader) · `00HT392` (with fingerprint reader) · touchpad alone `SM10A39149` |
| Contains | Synaptics ClickPad (PS/2), palmrest, touchpad bezel. Combined "palmrest + keyboard + touchpad" listings exist and are the simplest purchase. |
| Buy | [eBay 00HT393](https://www.ebay.com/p/1361311702) · [iFixit 00HT393](https://www.ifixit.com/products/00ht393-lenovo-thinkpad-x240-palmrest-touchpad-without-fpr) |

### ThinkPad X240 base cover (hand-made enclosure route E1)

| | |
|---|---|
| Part numbers | FRU `04X5184` / `00HT389` / `0C64937`; the label on the part itself reads `SCB0G39215` or `AP0SX000I00` — listings use any of these for the same cover |
| Role | Reused as the bottom enclosure — it already mates to the palmrest with the stock bosses |
| Buy | [eBay 04X5184](https://www.ebay.com/itm/121981528885) · [eBay SCB0G39215](https://www.ebay.com/itm/156310389262) · Newegg |

### Synaptics ClickPad (inside the palmrest)

Speaks **PS/2**, with a *pass-through (guest) port* that carries the TrackPoint's PS/2
stream inside Synaptics packets. Specification:
Synaptics *TouchPad Interfacing Guide* (PN 511-000275; no longer hosted publicly — the working reference is the Linux driver [`drivers/input/mouse/synaptics.c`](https://github.com/torvalds/linux/blob/master/drivers/input/mouse/synaptics.c)).
Architecture and packet formats in [`trackpoint.md`](trackpoint.md).

### TrackPoint controller (inside the keyboard)

Two-piece module family shared by T440/T450/T460/X240/X250/X260 — strain-gauge sensor
board plus a controller (TPM754-class) that outputs PS/2. Background:
[sharktastica TrackPoint wiki](https://sharktastica.co.uk/wiki/trackpoint) ·
[delingren/thinkpad_keyboards](https://github.com/delingren/thinkpad_keyboards) (04Y0819,
documents the reset-pulse requirement on a standalone module).

---

## Passives and hardware

| Part | Value | Role |
|---|---|---|
| Resistor | 4.7 kΩ ¼ W × 2 | PS/2 DATA/CLK pull-ups |
| Resistor | 10 kΩ ¼ W × 1 | MOSFET gate series |
| Resistor | 100 kΩ ¼ W × 1 | MOSFET gate pull-down (LED off during boot) |
| Resistor | 100 Ω ¼ W × 2 | Backlight series (value set by measurement), touchpad LED |
| Capacitor | 100 nF X7R × 6 | Decoupling — one per 74HC165, two near the Pico |
| Stripboard | ≈100 × 80 mm | Rev A adapter ([Vero stripboard](https://verotl.com/circuitboards/veroboards)) |
| Headers | 2 × 20-pin 0.1" female | Socket the Pico so it can be replaced |
| Standoffs | M2 × 6 mm brass + M2 screws | Board mounting |
| Heat-set inserts | M2 × 3 mm | Printed enclosure bosses |
| Wire | 30 AWG wire-wrap, several colours | Point-to-point on Rev A |
| Gasket | 1 mm self-adhesive craft foam | Seals the deck-to-case seam |
| Filament | PETG, ~150 g | Printed enclosure route |

---

## Tools

| Tool | Used for | Note |
|---|---|---|
| Digital calipers | Measuring the X240 deck, bosses, stack heights | 0.01 mm resolution is enough |
| Temperature-controlled soldering iron, fine tip | 0.5 mm pitch breakouts, SIP networks | Flux and magnification strongly advised at 0.5 mm |
| Multimeter | Continuity at the FPC, VCC identification, LED forward drop | Diode mode needed |
| 8-channel USB logic analyser | Seeing PS/2 CLK/DATA while identifying ClickPad pins | Cypress FX2 "Saleae clone" with [sigrok/PulseView](https://sigrok.org/wiki/PulseView) |
| Serial terminal | CircuitPython probe tools at 115200 baud | Thonny, PuTTY, `screen` |
| [OpenSCAD](https://openscad.org/) | Editing and exporting CAD | Free |
| [KiCad 8+](https://www.kicad.org/) | Rev B PCB | Free |
| 3D printer *or* hand tools | Enclosure — see [`../enclosure/printed.md`](../enclosure/printed.md) and [`../enclosure/handmade.md`](../enclosure/handmade.md) | |

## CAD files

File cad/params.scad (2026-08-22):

/*
 * params.scad — every dimension the printed parts share, in millimetres.
 * ======================================================================
 * Included by all cad/*.scad files. No dimension may be duplicated in a part
 * file; if two parts need the same number, it lives here.
 *
 * Values marked MEASURE are design targets until caliper measurements of a real
 * X240 top section replace them (issue #44). Everything else is a design choice.
 */

// ---------------------------------------------------------------- deck / case
case_width  = 309.0;   // MEASURE  X, left to right, at the deck's mating surface
case_depth  = 210.0;   // MEASURE  Y, front (palmrest) to back
wall_t      = 2.5;     // PETG shell wall
corner_r    = 3.0;     // MEASURE  outer corner radius
internal_h  = 18.0;    // floor-to-deck clearance (see docs/enclosure/integration.md)
case_h      = internal_h + wall_t;

// Screw bosses that meet the X240 deck, from the front-left corner.  MEASURE all.
deck_boss_positions = [
    [  8.0,   8.0 ], [ 60.0,   8.0 ], [150.0,   8.0 ], [250.0,   8.0 ], [301.0,   8.0 ],
    [  8.0, 202.0 ], [150.0, 202.0 ], [301.0, 202.0 ],
];
boss_od = 6.0;
boss_id = 3.2;         // M2 heat-set insert hole (insert OD ~3.2 for a 3.5 mm body)

// ---------------------------------------------------------------- split joint
split      = true;     // print as two halves (fits a 220 mm bed); false = one piece
split_x    = case_width / 2;
tab_count  = 3;        // dovetail tabs along the floor seam
tab_w      = 14.0;     // tab width at the seam
tab_flare  = 3.0;      // extra width at the tip (dovetail angle)
tab_len    = 10.0;     // how far the tab reaches into the other half
joint_gap  = 0.15;     // clearance per face; tune with a 30 mm coupon
pin_d      = 3.0;      // alignment pins through the front/rear walls
pin_len    = 10.0;

// ---------------------------------------------------------------- board / sled
board_w    = 100.0;    // stripboard or Rev B PCB
board_d    = 80.0;
board_hole_inset = 4.0;                  // M2 holes this far from each board corner
board_hole_d     = 2.4;
sled_margin      = 6.0;                  // sled extends this far past the board
sled_t           = 2.0;
sled_standoff_h  = 6.0;                  // board sits this high above the sled
sled_standoff_od = 5.0;
// sled centre in the case (rear-centre; see docs/enclosure/integration.md)
sled_center = [ case_width / 2, case_depth - 8 - board_d / 2 - sled_margin - 6 ];
// sled-to-case bosses (around the sled, two per half so the sled bridges the seam)
sled_boss_offsets = [ [-56, -46], [56, -46], [-56, 46], [56, 46] ];

// ---------------------------------------------------------------- Pico
pico_w = 51.0;
pico_d = 21.0;
pico_h = 1.0;          // PCB thickness
pico_hole_d = 2.1;     // Pico mounting holes, 11.4 x 47 mm pattern
pico_hole_dx = 47.0;
pico_hole_dy = 11.4;

// ---------------------------------------------------------------- USB
usb_c     = false;                     // false = Micro-USB cutout, true = USB-C
usb_w     = usb_c ? 9.5 : 8.5;
usb_h     = usb_c ? 4.0 : 3.5;
usb_x     = sled_center[0];            // cutout centred on the board
usb_z     = wall_t + sled_t + sled_standoff_h + 1.6;   // bottom of the Pico's connector
cable_d   = 4.5;                       // USB cable jacket diameter
relief_w  = 22.0;                      // strain-relief bezel footprint
relief_d  = 12.0;
relief_h  = 10.0;

// ---------------------------------------------------------------- FPC
fpc_w        = 22.0;   // 40-pin 0.5 mm cable width
fpc_t        = 0.3;
fpc_min_r    = 5.0;    // minimum bend radius
clickpad_fpc_w = 8.0;  // MEASURE  ClickPad cable width
zif_body_w   = 26.0;   // 40-pin ZIF connector body length along the cable edge
zif_body_d   = 6.0;
zif_body_h   = 5.0;
zif_cp_body_w = 12.0;  // ClickPad ZIF body (pin count from probing)

// ---------------------------------------------------------------- gasket, vents, feet
gasket_depth = 1.2;
gasket_width = 2.0;
vents        = false;  // not thermally needed (docs/enclosure/durability.md)
vent_w = 40.0; vent_h = 2.0; vent_count = 4; vent_spacing = 6.0;
ribs         = true;   // two front-to-back stiffening ribs in the floor
rib_t        = 2.0;
rib_h        = 4.0;

foot_d       = 10.0;   // rubber feet, front
foot_recess  = 1.0;
foot_positions = [ [25, 20], [case_width - 25, 20] ];
tilt_positions = [ [25, case_depth - 20], [case_width - 25, case_depth - 20] ];
tilt_h       = 12.0;   // rear riser height
tilt_w       = 30.0;
tilt_d       = 20.0;
tilt_screw_d = 3.4;    // M3 clearance

// ---------------------------------------------------------------- LED light pipe
pipe_d       = 3.0;
pipe_flange_d= 5.0;
pipe_len     = internal_h - 2;
pipe_position = [ sled_center[0] + board_w / 2 + 15, sled_center[1] - 20 ];  // beside the touchpad

// ---------------------------------------------------------------- printing
fit      = 0.2;        // general hole clearance for printed-in-place fits
$fn      = 48;

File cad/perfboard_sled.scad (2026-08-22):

/*
 * perfboard_sled.scad — tray that carries the Rev A stripboard or the Rev B PCB
 * ===========================================================================
 * Screws to the four sled bosses in the bottom case (two per half, so it bridges
 * the split seam and stiffens the joined shell).  The board sits on four M2
 * standoffs on the board's own hole pattern.  Both the stripboard and the Rev B
 * PCB are drilled to this pattern (docs/hardware/pcb.md).
 */
include <params.scad>

sled_w = board_w + 2 * sled_margin;
sled_d = board_d + 2 * sled_margin;

module sled() {
    difference() {
        union() {
            // plate
            translate([-sled_w / 2, -sled_d / 2, 0]) cube([sled_w, sled_d, sled_t]);
            // board standoffs
            for (x = [-1, 1], y = [-1, 1])
                translate([x * (board_w / 2 - board_hole_inset), y * (board_d / 2 - board_hole_inset), 0])
                    cylinder(h = sled_t + sled_standoff_h, d = sled_standoff_od);
        }
        // board M2 holes through the standoffs
        for (x = [-1, 1], y = [-1, 1])
            translate([x * (board_w / 2 - board_hole_inset), y * (board_d / 2 - board_hole_inset), -1])
                cylinder(h = sled_t + sled_standoff_h + 2, d = board_hole_d - 0.4);   // tap M2 directly into PETG
        // case boss holes
        for (o = sled_boss_offsets) translate([o[0], o[1], -1]) cylinder(h = sled_t + 2, d = board_hole_d);
        // lightening windows
        for (x = [-1, 1], y = [-1, 1])
            translate([x * 25 - 15, y * 18 - 10, -1]) cube([30, 20, sled_t + 2]);
    }
}

sled();

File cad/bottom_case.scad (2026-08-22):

/*
 * bottom_case.scad — X240 Pico keyboard bottom shell, printed as two halves
 * =========================================================================
 * The X240 top section (deck + palmrest) is the lid; this closes the assembly.
 * 309 x 210 mm exceeds every common print bed, so the shell splits at the
 * centre line with dovetail tabs in the floor, a half-lap on the front and rear
 * walls, and two alignment pins.  The perfboard sled screws across the seam and
 * is what makes the joined case stiff.
 *
 *   half = "left" | "right" | "both"     ("both" for a large-format printer)
 *
 * All dimensions come from params.scad.  Export:  F6, then File > Export > STL,
 * or ./dev build cad for every part at once.
 */
include <params.scad>

half = "left";

// ---------------------------------------------------------------- primitives
module rounded_box(w, d, h, r) {
    hull() for (x = [r, w - r], y = [r, d - r]) translate([x, y, 0]) cylinder(h = h, r = r);
}

module shell() {
    difference() {
        rounded_box(case_width, case_depth, case_h, corner_r);
        translate([wall_t, wall_t, wall_t])
            rounded_box(case_width - 2 * wall_t, case_depth - 2 * wall_t, case_h, max(0.1, corner_r - wall_t));
    }
}

module boss(x, y, h = case_h, od = boss_od, id = boss_id) {
    translate([x, y, 0]) difference() { cylinder(h = h, d = od); translate([0, 0, wall_t]) cylinder(h = h, d = id); }
}

module deck_bosses()  { for (p = deck_boss_positions) boss(p[0], p[1]); }
module sled_bosses()  { for (o = sled_boss_offsets) boss(sled_center[0] + o[0], sled_center[1] + o[1], wall_t + 4, 7, boss_id); }

module gasket_ledge() {
    translate([0, 0, case_h - gasket_depth]) difference() {
        rounded_box(case_width, case_depth, gasket_depth, corner_r);
        translate([gasket_width, gasket_width, -1])
            rounded_box(case_width - 2 * gasket_width, case_depth - 2 * gasket_width, gasket_depth + 2, max(0.1, corner_r - gasket_width));
    }
}

module stiffening_ribs() {
    if (ribs) for (x = [case_width * 0.25, case_width * 0.75])
        translate([x - rib_t / 2, wall_t, wall_t]) cube([rib_t, case_depth - 2 * wall_t, rib_h]);
}

// ---------------------------------------------------------------- cutouts
module usb_cutout() {
    translate([usb_x - usb_w / 2 - fit, case_depth - wall_t - 1, usb_z]) cube([usb_w + 2 * fit, wall_t + 2, usb_h + 2 * fit]);
}
module vent_slots() {
    if (vents) {
        sx = (case_width - vent_w) / 2; sy = case_depth / 2 - ((vent_count - 1) * vent_spacing) / 2;
        for (i = [0 : vent_count - 1]) translate([sx, sy + i * vent_spacing, -1]) cube([vent_w, vent_h, wall_t + 2]);
    }
}
module foot_recesses()   { for (p = foot_positions) translate([p[0], p[1], -1]) cylinder(h = foot_recess + 1, d = foot_d + fit); }
module tilt_screw_holes(){ for (p = tilt_positions) translate([p[0], p[1], -1]) cylinder(h = wall_t + 2, d = tilt_screw_d); }
module light_pipe_hole() { translate([pipe_position[0], pipe_position[1], -1]) cylinder(h = wall_t + 2, d = pipe_d + fit); }
module reset_hole()      { translate([sled_center[0] - 30, sled_center[1] + 30, -1]) cylinder(h = wall_t + 2, d = 3.2); }

// ---------------------------------------------------------------- split joint
// Dovetail tab profile in XY, extruded through the floor; the left half carries
// the tabs, the right half the pockets (pocket = tab grown by joint_gap).
module tab_profile(grow = 0) {
    w0 = tab_w + 2 * grow; w1 = tab_w + tab_flare + 2 * grow; l = tab_len + grow;
    polygon([[0, -w0 / 2], [l, -w1 / 2], [l, w1 / 2], [0, w0 / 2]]);
}
module floor_tabs(grow = 0) {
    for (i = [1 : tab_count])
        translate([split_x, case_depth * i / (tab_count + 1), 0])
            linear_extrude(wall_t) tab_profile(grow);
}
// Half-lap on the front and rear walls: the left wall's outer half continues past
// the seam; the right wall's outer half stops short by the same amount.
lap_len = 8;
module wall_lap(grow = 0) {
    for (y = [0, case_depth - wall_t / 2])
        translate([split_x - grow, y - grow, wall_t]) cube([lap_len + 2 * grow, wall_t / 2 + 2 * grow, case_h - wall_t + 1]);
}
module pins(grow = 0) {
    for (y = [wall_t / 4, case_depth - wall_t / 4])
        translate([split_x - pin_len / 2 - grow, y, case_h / 2]) rotate([0, 90, 0]) cylinder(h = pin_len + 2 * grow, d = pin_d + 2 * grow);
}

module whole_case() {
    difference() {
        union() { shell(); deck_bosses(); sled_bosses(); gasket_ledge(); stiffening_ribs(); }
        usb_cutout(); vent_slots(); foot_recesses(); tilt_screw_holes(); light_pipe_hole(); reset_hole();
    }
}

module left_half() {
    union() {
        difference() {
            intersection() { whole_case(); translate([-1, -1, -1]) cube([split_x + 1, case_depth + 2, case_h + 2]); }
            wall_lap(joint_gap);             // clear the lap pocket on the inner half...
            pins(joint_gap);
        }
        intersection() { whole_case(); floor_tabs(); }   // ...then add the tabs and lap tongue
        intersection() { whole_case(); wall_lap(); }
    }
}
module right_half() {
    difference() {
        intersection() { whole_case(); translate([split_x, -1, -1]) cube([case_width - split_x + 1, case_depth + 2, case_h + 2]); }
        floor_tabs(joint_gap);
        wall_lap(joint_gap);
        pins(joint_gap);
    }
}

if (!split || half == "both") whole_case();
else if (half == "left") left_half();
else right_half();

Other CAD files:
cad/export_plates.scad
cad/fpc_cable_guide.scad
cad/led_light_pipe.scad
cad/pico_mount_bracket.scad
cad/tests/joint_intersection.scad
cad/tilt_feet.scad
cad/usb_strain_relief.scad
cad/zif_support_block.scad

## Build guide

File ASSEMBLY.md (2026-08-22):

# Assembly guide

Step-by-step for the **Rev A perfboard** build. Rev B (PCB) replaces Phase 2 with
"solder the board" and is covered in [`docs/hardware/pcb.md`](docs/hardware/pcb.md).

Read first: [`docs/hardware/components.md`](docs/hardware/components.md) for every part,
[`hardware/wiring/wiring_diagram.md`](hardware/wiring/wiring_diagram.md) for the GPIO table.

---

## Phase 1 — FPC pinout discovery (mandatory, do first)

The keyboard FPC has 40 lines; which are matrix, power, backlight, power button and
(possibly) TrackPoint is established by measurement. **Do not wire anything to the Pico
until this phase is recorded in `hardware/pinout/`.**

Full procedure: [`hardware/pinout/probing_procedure.md`](hardware/pinout/probing_procedure.md).
Summary:

1. **Keyboard matrix.** FPC into the 40-pin ZIF breakout (check contact side — see the
   picture below). Pico with CircuitPython, `tools/matrix_probe/matrix_probe.py` as
   `code.py`, 115200 baud. Two passes cover 40 pads on 26 GPIO. Press every key; the
   script prints the (drive, sense) pad pair per key as a Markdown table.
2. **Non-matrix pins.** GND by continuity to the cable's shield; VCC by 3.3 V through
   100 Ω; backlight pair by a faint glow at 3.3 V through 100 Ω (backlit variants only);
   power button by continuity when pressed.
3. **Three-key test.** Hold A + S + D. No phantom key ⇒ the membrane has diodes ⇒ no
   1N4148s needed.
4. **ClickPad.** Its FPC into the small breakout. Find VCC/GND (the Synaptics draws
   ~10–15 mA when correctly powered). 4.7 kΩ pull-ups on the candidate CLK/DATA pins;
   `tools/ps2_sniffer/ps2_sniffer.py` finds the pair and runs the Synaptics identify.
5. **TrackPoint route.** With the sniffer running, push the stick with **no finger on the
   pad**. Pass-through frames (`W == 3`) ⇒ the TrackPoint rides the ClickPad bus and needs
   no wiring. No frames ⇒ find its own CLK/DATA on the keyboard FPC; they go to GP20/GP19.
6. **Record** everything in `hardware/pinout/x240_keyboard_fpc_pinout.md` and
   `hardware/pinout/x240_clickpad_fpc_pinout.md`.

FPC orientation and pin 1

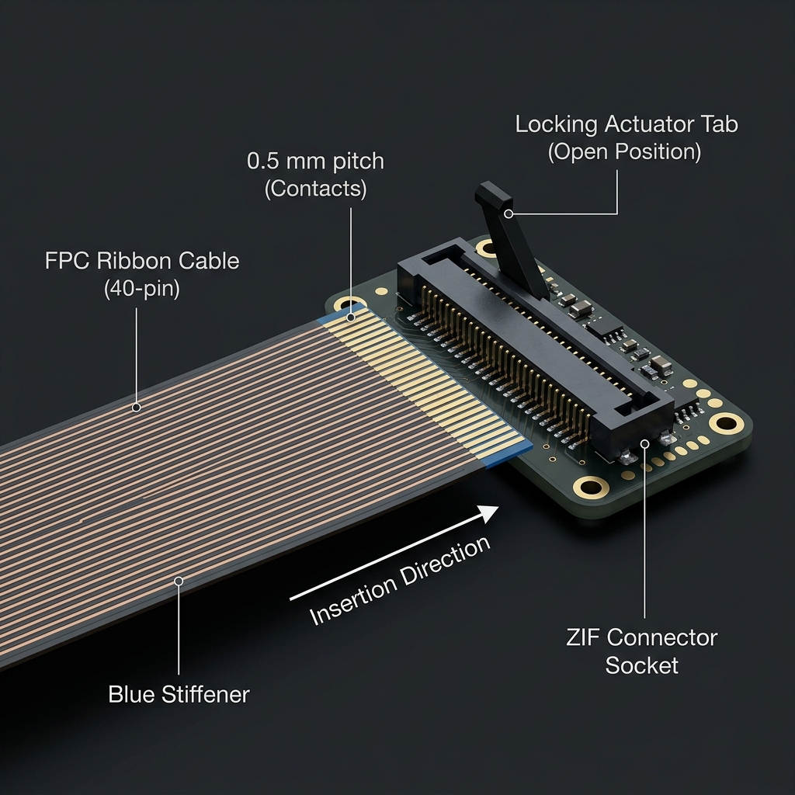
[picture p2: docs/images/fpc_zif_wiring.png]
FPC ribbon cable and ZIF breakout


*Photo-style illustration only; the drawing is the reference.*

---

## Phase 2 — Rev A perfboard

### 2.1 Board

Stripboard ≈100 × 80 mm. Lay out: ZIF breakouts along the front edge (toward the deck's
cable exits), three DIP-16 sockets in a row behind them, the 2 × 20 Pico socket at the rear
edge with USB facing out. Break strips under the DIPs and sockets. Drill four M2 holes on
the sled pattern ([`docs/enclosure/printed.md`](docs/enclosure/printed.md)) — or, for the
hand-made E1 route, to match three of the X240 base cover's standoffs.

### 2.2 Sense chain

Per [`docs/hardware/shift-register-matrix.md`](docs/hardware/shift-register-matrix.md):

- U1–U3 `74HC165` in sockets. `VCC` → 3V3 with 100 nF to GND at each chip. `CE` → GND.
- `PL` of all three → GP17. `CP` of all three → GP18.
- U1 `Q7` → GP16. U2 `Q7` → U1 `DS`. U3 `Q7` → U2 `DS`. U3 `DS` → GND.
- One 9-pin 10 kΩ bussed SIP per chip: common pin → 3V3, the eight others → `D0`–`D7`.
- Sense lines from the keyboard breakout → `D0`–`D7` of U1, U2, U3 in order (S0 = U1.D0).

Run `tools/shift_register_test/` **before** connecting the keyboard: ground each `Dn` in
turn and confirm the matching bit.

### 2.3 Drive lines

Keyboard breakout drive pads → GP0 … GP9 directly. Use a different wire colour from the
sense lines.

### 2.4 PS/2

```
3V3  ── ClickPad VCC        GND ── ClickPad GND
GP21 ── ClickPad DATA  + 4.7 kΩ to 3V3
GP22 ── ClickPad CLK   + 4.7 kΩ to 3V3
```

DATA on GP21 and CLK on GP22 — not the other way. The RP2040 PIO driver requires
clock = data + 1.

### 2.5 Backlight (backlit keyboards only)

```
3V3 ── R_series ── strip (+)     strip (−) ── Q1 drain     Q1 source ── GND
GP26 ── 10 kΩ ── Q1 gate         Q1 gate ── 100 kΩ ── GND
```

Measure strip current first and pick R_series:
[`docs/hardware/backlight.md`](docs/hardware/backlight.md).

### 2.6 Power button, LED, reset

```
Power-button FPC pin ── GP27         (internal pull-up; firmware guard 500 ms)
GP28 ── 100 Ω ── LED (+)   LED (−) ── GND
RUN ── tactile switch ── GND
```

### 2.7 Pre-power check

Work through the checklist at the end of
[`hardware/wiring/wiring_diagram.md`](hardware/wiring/wiring_diagram.md). Only then plug in.

---

## Phase 3 — Firmware

```bash
pip install qmk && qmk setup
cp -r firmware/qmk/keyboards/x240_pico ~/qmk_firmware/keyboards/x240_pico
# set matrix size and regenerate LAYOUT/keymap from Phase 1 (milestone M4 tooling)
qmk compile -kb x240_pico -km default
qmk flash   -kb x240_pico -km default       # hold BOOTSEL while plugging in
```

Configuration reference: [`docs/firmware/qmk-configuration.md`](docs/firmware/qmk-configuration.md).
Pointing-stack bring-up and tuning: [`docs/firmware/pointing-stack.md`](docs/firmware/pointing-stack.md).

Test: every key in a text editor; an NKRO tester with 10+ keys; ClickPad move and corner
clicks; **stick moves the cursor with no finger on the pad**; FN + F1 mute, FN + F11
backlight, FN + Esc FN Lock; power button ≥ 500 ms. With `CONSOLE_ENABLE = yes`,
`qmk console` must show the Synaptics identify succeeding — not the fallback line.

---

## Phase 4 — Enclosure

Pick one:

- **Printed** — [`docs/enclosure/printed.md`](docs/enclosure/printed.md). Measure the
  deck, update `cad/params.scad`, print the two case halves and the small parts, dry-fit.
- **Hand-made** — [`docs/enclosure/handmade.md`](docs/enclosure/handmade.md). E1 (reuse
  the X240 base cover) needs a screwdriver and a rotary tool and no measuring.

Fit and routing rules for both: [`docs/enclosure/integration.md`](docs/enclosure/integration.md).

---

## Phase 5 — Final assembly

Follow the order in [`docs/enclosure/presentation.md`](docs/enclosure/presentation.md):
bench-test open → prepare enclosure → strain relief and guides → mount board → ClickPad
FPC → keyboard FFC → re-test beside the deck → lay deck on, check the seam with a torch →
screw down star-pattern, hand-tight → gasket, feet, light pipe → test on three OSes →
flash the release firmware.

---

## Troubleshooting

| Symptom | Likely cause | Fix |
|---|---|---|
| No USB device | Not powered, wrong `.uf2`, or firmware doesn't build yet (pre-M4) | Check cable; reflash; see `docs/firmware/architecture.md` |
| Random keys with nothing pressed | A sense input floating | SIP common pin not on 3V3, or a missing network |
| Keys shifted by 8 / stuck pattern | Chain order or PL/CP swapped | Re-check 2.2 with the self-test |
| Some keys missing / wrong | Keymap mismatch | Regenerate from Phase 1 data |
| Ghost keys with three held | No membrane diodes | Add 1N4148 per sense line at the breakout |
| Touchpad dead | DATA/CLK swapped | DATA = GP21, CLK = GP22 |
| Touchpad works, TrackPoint dead | Identify failed → relative fallback | `qmk console` shows the fallback line; check init timing; confirm `W == 3` frames in the sniffer |
| Touchpad very slow / fast | Scale constant | `SYN_TOUCHPAD_SCALE` |
| Backlight always off | MOSFET pinout | Check *that* part's datasheet |
| Backlight always on | No gate pull-down | Add 100 kΩ gate → GND |
| Backlight won't build | Driver | `BACKLIGHT_DRIVER = software` on RP2040 |
| Power button instant | Guard | Check `matrix_scan_kb()` and `POWER_BUTTON_HOLD_MS` |

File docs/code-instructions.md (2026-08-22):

---
title: Code instructions
nav_exclude: true
---

# Code instructions

QMK C, CircuitPython tools, OpenSCAD and Markdown. Keep each hardware-verifiable.

## QMK C

- Upstream QMK conventions; build must succeed after copying the keyboard directory into a
  QMK checkout (`qmk compile -kb x240_pico -km default`).
- `rules.mk` selects features and lists extra sources; `config.h` holds pins and constants;
  `keyboard.json` holds USB/layout metadata and the `ps2` block — **no `matrix_pins`** with
  the custom matrix.
- `matrix.c` does only the chain scan. `synaptics.c` owns the PS/2 conversation.
  `trackpoint.c` owns guest frames. `x240_pico.c` merges and polls. Keep these boundaries.
- `process_record_user()` for custom keycodes; no side effects in scan hooks beyond the
  power-button timer.
- `KC_NO` for empty matrix cells, `KC_TRNS` for FN pass-through.
- Log every fallback path with `dprintf`; a degraded mode that says nothing is a bug.

## CircuitPython tools

- Standalone, built-in modules only; run as `code.py` at 115200 baud.
- Hardware imports are guarded (`ON_DEVICE`); protocol/formatting logic stays in pure
  functions above them and is covered by `tools/tests/` on the host.
- Every physical pin assumption is a top-level constant.
- Output is a Markdown table that pastes into the pinout files unchanged.
- Deinitialise GPIO between passes; never drive an identified power or ground pin.
- The sniffer's Synaptics mode must print an unambiguous verdict on pass-through frames.

## OpenSCAD

- All dimensions from `cad/params.scad`, in millimetres, commented with what was measured.
- Parts select their variant by parameter (`half = "left"`), never by copied files.
- `export_plates.scad` derives laser-cut outlines from the same solids via `projection()`.
- No committed meshes.

## Markdown

- Relative links inside the repo; absolute links to datasheets and products.
- Front matter (`title`, `parent`, `nav_order`) on every `docs/` page; `nav_exclude: true`
  on maintainer pages.
- Mark unverified things as unverified. Tables for hardware facts.

## Review checklist

- Does the change match measured data, or say it is waiting for it?
- Is the GPIO table still stated once, in `hardware/wiring/wiring_diagram.md`?
- Is every new part in `components.md` and priced in `bom-and-cost.md`?
- Is a corrected claim recorded in `CHANGELOG.md` with its source?
- Do all relative links resolve and all URLs return 2xx?
- Are generated artifacts ignored?
- Would the firmware still build after the change (or is the build break tracked)?

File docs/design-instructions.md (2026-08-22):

---
title: Design instructions
nav_exclude: true
---

# Design instructions

The design contract for electrical, firmware, mechanical and documentation changes.

## Goals

- Standard USB HID composite device; no host drivers, any OS.
- First build possible on perfboard with off-the-shelf FPC breakouts; Rev B PCB is a
  drop-in with the same GPIO map and firmware.
- Measured data over assumptions: nothing is wired or finalised before Phase 1 probing.
- Two enclosure routes (printed, hand-made) from one set of dimensions.
- A USB-C path that needs no firmware change.

## Electrical

- 3.3 V logic everywhere; confirm every FPC pin before it touches a GPIO.
- Drive lines on GP0–GP9; sense lines through the 74HC165 chain on GP16/17/18. Put the
  larger matrix dimension on the chain.
- Every 74HC165 input has an external pull-up; `CE` grounded; last `DS` grounded; 100 nF
  per chip.
- PS/2 DATA = GP21, CLK = GP22 (PIO driver: clock = data + 1), 4.7 kΩ pull-ups. GP19/GP20
  stay reserved for a second PS/2 pair.
- Backlight through a MOSFET with a gate pull-down; series resistor set by measurement.
- Power button is an active-low input with a firmware long-press guard, not a matrix key.
- 1N4148 diodes only if the three-key test shows the membrane lacks them.
- The USB-C upgrade uses TP1 = GND, TP2 = D−, TP3 = D+. Never the other way.

## Firmware

- QMK. `PS2_DRIVER = vendor`, `BACKLIGHT_DRIVER = software`, `CUSTOM_MATRIX = lite`.
  Changing any of these needs a measured reason recorded in `CHANGELOG.md`.
- The TrackPoint is decoded from Synaptics pass-through frames. If the identify sequence
  fails, fall back to relative mode **and log it** — no silent degradation.
- The placeholder keymap is not verified; regenerate from measured data.
- FN + Esc = FN Lock, FN + F11 = backlight, unless a layout change is recorded.

## Mechanical

- One shared `cad/params.scad`; no dimension duplicated across files.
- The bottom case is printed as two halves; the sled bridges the seam.
- FPC bend radius ≥ 5 mm; strain relief loads the case, never a connector.
- Serviceable: deck off, two ZIF tabs, board out. No glue in the printed route.
- Meshes and DXFs go to `cad/exports/`, not into git.

## Documentation

- `hardware/wiring/wiring_diagram.md` holds the only GPIO table; other pages link to it.
- Every part named anywhere appears in `docs/hardware/components.md` with a link.
- Every cost figure traces to `docs/hardware/bom-and-cost.md`.
- A correction to a previously published claim goes in `CHANGELOG.md` with its source.
- Images are illustration unless authored as SVG with source in-tree; captions say which.
- State lives in GitHub issues, not in documents.

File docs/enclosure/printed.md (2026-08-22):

---
title: Printed enclosure
parent: Enclosure
nav_order: 1
---

# Enclosure route 1 — 3D printed

## The part that does not fit

`cad/bottom_case.scad` models the bottom shell as **one 309 × 210 mm part**. That is larger
than every common print bed:

| Printer | Bed (X × Y mm) | 309 mm fits? |
|---|---|---|
| Creality Ender 3 / V3 | 220 × 220 | no |
| Prusa MK4 / MK3S | 250 × 210 | no |
| Bambu X1 / P1 / A1 | 256 × 256 | no |
| Prusa XL, Bambu H2D, Elegoo Neptune 4 Max | ≥ 320 | yes |

So the case is printed as **two halves**, joined at the centreline (`split_x` in
`params.scad`):

- Each half is 154.5 mm wide plus 10 mm of tabs — fits a 220 mm bed flat.
- **Floor tabs:** three dovetail tabs (`tab_count`, `tab_w`, `tab_flare`, `tab_len`) on the
  left half's floor drop into matching pockets in the right half; pockets are grown by
  `joint_gap` (0.15 mm per face — tune with a 30 mm coupon).
- **Wall half-lap:** on the front and rear walls the left half's outer half-thickness
  continues 8 mm past the seam; the right wall is recessed to match.
- **Pins:** two 3 mm holes through the laps take a length of filament or brass rod.
- **The sled** screws to four bosses, two per half — that is what makes the joined shell
  stiff; the tabs only locate it.
- The gasket ledge continues across the seam so it is not a dust path.
- `half = "left" | "right" | "both"` — `"both"` for a large-format printer.

The joint is verified every `./dev test`: `cad/tests/joint_intersection.scad` renders the
overlap of the two halves and `scripts/check_cad_joint.py` fails if it has any volume.

## The eight printed parts

| # | Part | File | Purpose | Qty |
|---|---|---|---|---|
| 1 | Bottom case, left | `bottom_case.scad` (`half="left"`) | Shell, bosses, gasket ledge, vents, USB cutout, light-pipe aperture, foot recesses | 1 |
| 2 | Bottom case, right | `bottom_case.scad` (`half="right"`) | as above | 1 |
| 3 | Pico mount bracket | `pico_mount_bracket.scad` | Cradle holding the Pico at a fixed height (Rev A only; Rev B mounts the Pico on the board) | 1 |
| 4 | FPC cable guide | `fpc_cable_guide.scad` (`cable="keyboard"`/`"clickpad"`) | Enforces ≥ 5 mm bend radius on the FFC | 2 + 1 |
| 5 | Perfboard sled | `perfboard_sled.scad` | Tray with the common M2 hole pattern; holds Rev A stripboard or Rev B PCB; bridges the case seam | 1 |
| 6 | USB strain relief | `usb_strain_relief.scad` | Two-piece clamp (M2 bolts) gripping the cable jacket, screwed to the floor, so a pull loads the case, not the Pico's connector | 1 set |
| 7 | Tilt feet | `tilt_feet.scad` | Rear risers for a typing angle; front recesses take 10 mm rubber feet | 2 |
| 8 | ZIF support block | `zif_support_block.scad` (`variant="keyboard"`/`"clickpad"`) | Backs up the FPC connectors against insertion force so they do not lift off the board | 1 + 1 |
| 9 | LED light pipe | `led_light_pipe.scad` | Carries the touchpad LED to the deck surface; printed in clear PETG or natural PLA | 1 |

(Nine files, "eight parts" in the issues because the two case halves come from one source.)

All dimensions come from one shared file, `cad/params.scad`; values marked `MEASURE` are
targets until the real X240 deck is measured (#44). No number may be duplicated across
files. Render everything with `./dev build cad` → `out/cad/*.stl` (OpenSCAD 2021.01 in
Docker; PNG previews are not available headless — open the `.scad` in OpenSCAD to look).

## Print settings

| Part | Material | Layer | Walls | Infill | Supports | Notes |
|---|---|---|---|---|---|---|
| Case halves | PETG | 0.20 mm | 4 | 25 % gyroid | none, open side up | 3–5 mm brim if corners lift |
| Sled, bracket, ZIF block | PETG | 0.20 mm | 3 | 30 % | none | |
| Cable guide, strain relief | PETG | 0.16 mm | 3 | 40 % | none | small; print several |
| Tilt feet | PETG | 0.20 mm | 4 | 40 % | none | flat face down |
| Light pipe | clear PETG / natural PLA | 0.12 mm | 100 % | none | print standing | polish the tip |

PETG over PLA for the case: higher heat deflection (a laptop deck in the sun) and less
brittle at the dovetail. Estimated filament 120–180 g for the set.

## Tolerances

| Feature | Nominal | Printed allowance |
|---|---|---|
| M2 heat-set insert hole | 3.2 mm | +0 — inserts want a snug hole |
| Dovetail | — | 0.15 mm clearance per face; test with a 30 mm coupon before the full print |
| Alignment pins | 3.0 mm | hole 3.2 mm |
| Sled to case bosses | M2 | 2.4 mm clearance holes in the sled |
| Gasket ledge | 1.2 mm deep × 2.0 mm wide | foam tape is 1 mm; ledge leaves 0.2 mm compression |
| USB cutout | Micro-USB 8.5 × 3.5 / USB-C 9.5 × 4.0 | +0.5 mm each way |

Record actual measured-vs-designed values after the first dry-fit (issue #44); the table
above becomes the tolerance report.

## Assembly order for the printed route

1. Fit heat-set inserts into both halves and the sled.
2. Join the halves on the dovetail; push in the alignment pins.
3. Screw the sled across the seam — the case is now rigid.
4. Fit cable guides and ZIF support blocks to the sled.
5. Continue with [`integration.md`](integration.md).

## No printer?

Commercial print services (Craftcloud, JLC3DP, Treatstock) will quote the split halves
readily; a single 309 mm part is often refused or priced for an industrial machine. Expect
$25–45 for the set in PETG. Or skip printing entirely: [`handmade.md`](handmade.md).

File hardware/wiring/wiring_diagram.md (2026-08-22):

# Wiring reference

**This file is the single authoritative copy of the GPIO allocation.** Every other document
links here. If a page elsewhere disagrees with this table, this table wins and that page has
a bug.

---

## GPIO allocation

| Pico GPIO | Header pin | Function | Direction | Notes |
|---|---|---|---|---|
| GP0 | 1 | Matrix drive D0 | Output | Driven LOW one at a time during scan |
| GP1 | 2 | Matrix drive D1 | Output | |
| GP2 | 4 | Matrix drive D2 | Output | |
| GP3 | 5 | Matrix drive D3 | Output | |
| GP4 | 6 | Matrix drive D4 | Output | |
| GP5 | 7 | Matrix drive D5 | Output | |
| GP6 | 9 | Matrix drive D6 | Output | |
| GP7 | 10 | Matrix drive D7 | Output | |
| GP8 | 11 | Matrix drive D8 | Output | |
| GP9 | 12 | Matrix drive D9 | Output | Ten drive lines; documented ThinkPad matrices need ≤ 9 on one side |
| GP10–GP15 | 14–20 | **Spare** | — | |
| GP16 | 21 | Sense chain serial out ← 74HC165 U1 `Q7` | Input | SPI0 RX (MISO) |
| GP17 | 22 | Sense chain `PL` | Output | Parallel load, active LOW; plain GPIO |
| GP18 | 24 | Sense chain `CP` | Output | SPI0 SCK |
| GP19 | 25 | **Reserved** — PS/2 #2 DATA | — | Only if probing shows a standalone TrackPoint |
| GP20 | 26 | **Reserved** — PS/2 #2 CLK | — | Pair with GP19 (clock = data + 1) |
| GP21 | 27 | PS/2 **DATA** — ClickPad (+ TrackPoint pass-through) | Bidir | 4.7 kΩ pull-up to 3V3 |
| GP22 | 29 | PS/2 **CLK** — ClickPad | Bidir | 4.7 kΩ pull-up to 3V3. PIO driver rule: CLK = DATA + 1 |
| GP26 | 31 | Backlight MOSFET gate | Output | `software` PWM; 10 kΩ series, 100 kΩ pull-down |
| GP27 | 32 | Power button | Input | Internal pull-up; active LOW; 500 ms guard in firmware |
| GP28 | 34 | Touchpad LED | Output | HIGH = on, via 100 Ω |
| 3V3 | 36 | 3.3 V rail | Supply | 74HC165 × 3, SIP pull-ups, PS/2 pull-ups, ClickPad |
| GND | 3, 8, 13, 18, 23, 28, 33, 38 | Ground | Supply | |
| VBUS | 40 | 5 V from USB | Supply | Optional backlight anode supply |
| RUN | 30 | Reset | Input | Tactile switch to GND, reachable through the case |

*Header pin = physical pin on the Pico's 40-pin header.*

Pico underside test pads — used only by the USB-C upgrade:

| Pad | Signal |
|---|---|
| TP1 | GND |
| TP2 | USB D− |
| TP3 | USB D+ |

---

## Schematics

### Matrix and 74HC165 sense chain

74HC165 sense chain

```
 Keyboard FPC (40-pin, via ZIF breakout) — pin numbers filled after probing
 ┌──────────────────────────────────────────────────────────────────────────┐
 │ drive lines ────────────────────────────────► GP0 … GP9 (one per line)    │
 │ sense lines S0…S23 ──┐                                                    │
 └──────────────────────┼───────────────────────────────────────────────────┘
                        │          3V3
                        │           │
                        │      [RN1][RN2][RN3]  10 kΩ × 8 bussed SIP, one per chip
                        │           │
          ┌─────────────┴───────────┴──────────┐
          │  U1 74HC165      U2 74HC165      U3 74HC165                       │
          │  D0-D7 ← S0-S7   D0-D7 ← S8-S15  D0-D7 ← S16-S23                 │
          │  PL ◄────────────┬───────────────┬────────────────── GP17 (PL)   │
          │  CP ◄────────────┬───────────────┬────────────────── GP18 (SCK)  │
          │  Q7 ──► GP16     Q7 ──► U1.DS    Q7 ──► U2.DS     U3.DS ── GND   │
          │  CE ── GND       CE ── GND       CE ── GND                        │
          │  VCC 3V3 + 100 nF each                                            │
          └──────────────────────────────────────────────────────────────────┘
```

Read sequence, bit order and failure modes:
[`docs/hardware/shift-register-matrix.md`](../../docs/hardware/shift-register-matrix.md).

### PS/2 — ClickPad (carries the TrackPoint)

PS/2 bus with pull-ups

```
 3V3 ─────────────── ClickPad VCC
 GND ─────────────── ClickPad GND
 GP21 ─┬─ 4.7 kΩ ─ 3V3
       └──────────── ClickPad DATA
 GP22 ─┬─ 4.7 kΩ ─ 3V3
       └──────────── ClickPad CLK
 GP28 ── 100 Ω ───── LED anode   (LED cathode ── GND; or the ClickPad FPC's own LED pins)
```

The TrackPoint's PS/2 stream rides inside the ClickPad's packets (Synaptics pass-through).
No extra wires. If probing disproves that on your unit, the TrackPoint's own CLK/DATA go to
GP20/GP19 with the same pull-ups — see
[`docs/hardware/trackpoint.md`](../../docs/hardware/trackpoint.md).

### Backlight (backlit keyboard variants only)

Backlight MOSFET switch

```
 3V3 (or VBUS) ── R_series ── LED strip (+)
                              LED strip (−) ── Drain  Q1 2N7002 / BS170
                                               Source ── GND
 GP26 ── 10 kΩ ── Gate
                  Gate ── 100 kΩ ── GND        (off during boot)
```

R_series is set by measurement: [`docs/hardware/backlight.md`](../../docs/hardware/backlight.md).

### Power button

```
 GP27 ──────────── power-button FPC pin     (other side of the switch → GND)
 Pico internal pull-up keeps GP27 HIGH; pressed = LOW; firmware requires ≥ 500 ms hold
```

### Reset

```
 RUN (pin 30) ── tactile switch ── GND
```

### USB-C breakout (optional)

```
 Pico TP1 (GND) ──── breakout GND
 Pico TP2 (D−)  ──── breakout D−
 Pico TP3 (D+)  ──── breakout D+
 Pico VBUS      ──── breakout VBUS       breakout must have 5.1 kΩ on CC1 and CC2
```

USB-C breakout to Pico test pads

### FPC to ZIF breakout

FPC orientation and pin 1

FPC ribbon cable and ZIF breakout

*Photo-style illustration only; the drawing above is the reference.*

---

## Keyboard FPC → breakout → Pico / chain

Fill after probing (`hardware/pinout/x240_keyboard_fpc_pinout.md` is the master copy).

| Signal | FPC pin | Breakout pad | Destination |
|---|---|---|---|
| Drive D0 … D9 | | | GP0 … GP9 |
| Sense S0 … S7 | | | U1 D0 … D7 |
| Sense S8 … S15 | | | U2 D0 … D7 |
| Sense S16 … S23 | | | U3 D0 … D7 |
| GND | | | GND |
| VCC | | | 3V3 |
| Backlight + / − | | | R_series / Q1 drain |
| Power button | | | GP27 |
| TrackPoint CLK / DATA (only if standalone) | | | GP20 / GP19 |

## Rev A pre-power checklist

- [ ] Every FPC pad has continuity to exactly one destination
- [ ] No continuity between adjacent FPC pads (0.5 mm pitch — check every pair)
- [ ] 3V3 to GND: no short
- [ ] Each 74HC165: `CE` to GND, `VCC` to 3V3, 100 nF present
- [ ] SIP network common pin on 3V3
- [ ] PS/2 pull-ups present; DATA on GP21, CLK on GP22
- [ ] MOSFET pinout verified against *its* datasheet (TO-92 pinouts differ by maker)

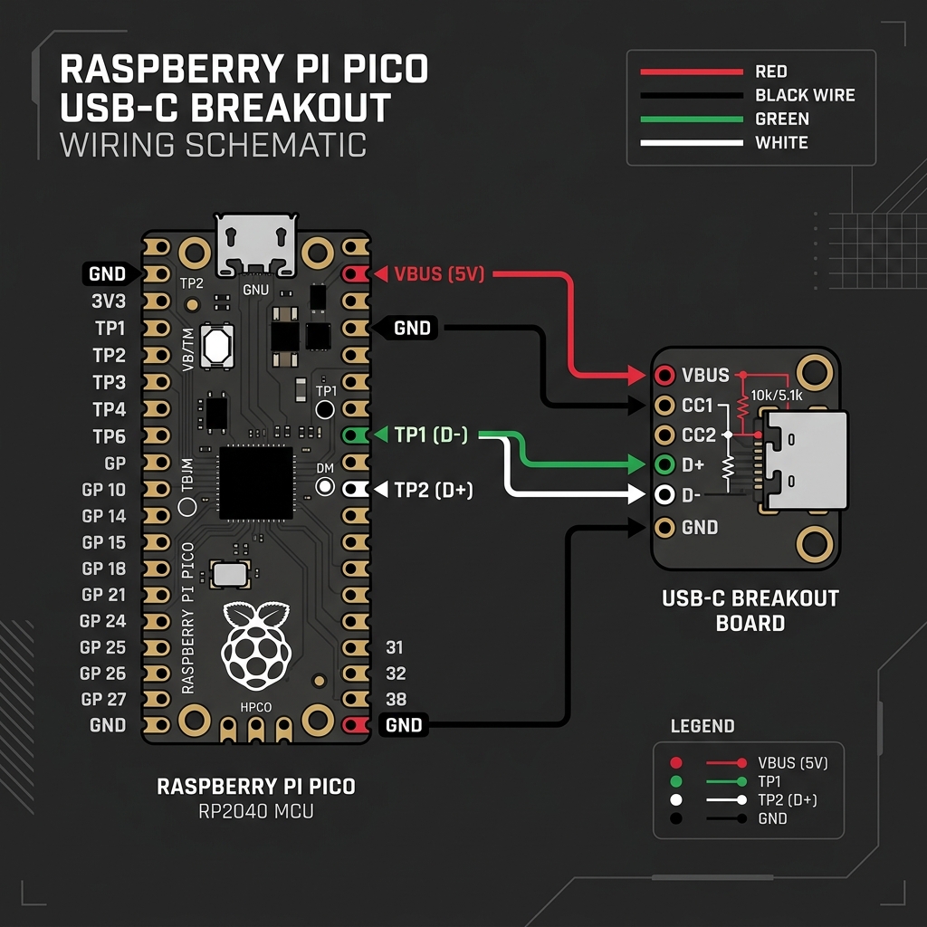
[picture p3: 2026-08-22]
docs/images/usb_c_wiring.png

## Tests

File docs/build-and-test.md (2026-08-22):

---
title: Build and test
nav_exclude: true
---

# Build and test workflow

From raw hardware to a verified device. Each step maps to a milestone. The commands are
`./dev` verbs (`scripts/project.sh`); CI runs `./dev test` and `./dev build all`.

## 1. Probe the keyboard FPC (M2)

CircuitPython on the Pico; `./probe matrix_probe` copies the tool as `code.py`; two passes
over the 40 pads (`PASS = "A"` then `"B"`); 115200 baud. Output is a Markdown table. Record drive/sense pairs per key, matrix size, GND/VCC,
backlight, power button, and the three-key ghost result in
`hardware/pinout/x240_keyboard_fpc_pinout.md`.

## 2. Probe the ClickPad and decide the TrackPoint route (M2)

VCC/GND first; 4.7 kΩ pull-ups on candidate CLK/DATA; `tools/ps2_sniffer/ps2_sniffer.py`
in `MODE = "find"` finds the pair, then in `MODE = "synaptics"` prints a `VERDICT:` line
stating whether `W == 3` pass-through frames appeared when the stick was pushed. Record in `hardware/pinout/x240_clickpad_fpc_pinout.md`.

## 3. Verify the sense chain alone (M3)

Build the 74HC165 chain; run `tools/shift_register_test/shift_register_test.py` in
`MODE = "walk"` — it prompts S0…S23 in order and names the wiring fault on any mismatch.
Only then connect the keyboard FPC.

Host-side checks: `./dev test` (pytest for the tools, byte-compile, link check, shellcheck).

## 4. Wire the rest (M3)

Per `hardware/wiring/wiring_diagram.md`. Complete its pre-power checklist before USB.

## 5. Build and flash firmware (M4)

```bash
./dev install        # once: submodules, docker images, shallow qmk_firmware checkout
./dev build          # qmk compile in qmkfm/qmk_cli -> out/x240_pico_default.uf2
./dev deploy         # waits for the RPI-RP2 drive and copies the UF2
```

`QMK_HOME` points the build at an existing checkout. Images and the QMK commit are pinned
in `scripts/toolchain.env`; `scripts/pull_toolchain.sh --save <dir>` writes offline
tarballs and `--load <dir>` restores them on a machine without registry access. First flash: BOOTSEL → `RPI-RP2`.
Later: `./dev deploy`, Bootmagic (top-left key), or the `RUN` reset switch + BOOTSEL.
Debug output: `./dev logs` (`qmk console`).

## 6. Validate USB HID (M4 → M8)

- Enumerates with no driver on a fresh OS.
- Every key; NKRO with 10+ keys.
- ClickPad move and corner clicks; **stick alone moves the cursor**.
- `qmk console` shows the Synaptics identify succeeding, not the fallback line.
- FN media keys, FN Lock, backlight levels (backlit variant), power button ≥ 500 ms.
- Linux first, then Windows and macOS.

## 7. Enclosure (M5 or M6)

Printed: measure, `params.scad`, `./dev build cad`, print halves + parts, dry-fit,
tolerance report. The split-joint interference check runs in `./dev test`.
Hand-made: E1 base cover or another variant. Then the assembly order in
`docs/enclosure/presentation.md`.

## 7b. Rev B PCB (M7)

`./dev build pcb`: schematic and board are generated from `hardware/pcb/netlist_model.py`,
ERC and placement DRC must be clean, freerouting routes it once (`X240_ROUTE_PASSES`,
default 100; `X240_SKIP_ROUTE=1` to skip; single-threaded, so the same DSN always yields
the same session), DRC on the routed board must be clean *and* report no unconnected
items — freerouting's own "unrouted" count is not the gate, it has claimed success while
abandoning connections (#62) — then gerbers,
drill, position file, BOM and PDFs land in `out/pcb/`. Upload `out/pcb/gerbers.zip` to
JLCPCB/PCBWay. The Rev B board is *jumpered*: the FPC lines and the matrix lines meet on
adjacent headers and are wired after probing — see `docs/hardware/pcb.md`.

## 8. Acceptance (M8)

Every line in the README's verification checklist passes with the case closed, on three
OSes, and the release carries the tested `.uf2`.

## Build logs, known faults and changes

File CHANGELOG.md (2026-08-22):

# Changelog

All notable project changes should be recorded here.

## Unreleased

### Rev B PCB (milestone M7, issues #49 #50 #51)

- `hardware/pcb/` is a **generated** KiCad 9 project: `netlist_model.py` describes parts,
  library names and 110 nets; `gen_schematic.py` writes the schematic (real library
  symbols embedded, derived symbols flattened, one global label per pin) and
  `gen_pcb.py` the board (footprints placed by courtyard centre, every pad netted,
  100 × 80 mm outline, sled + base-cover hole patterns, back-side GND pour).
- **Design decision:** until probing fixes the keyboard matrix (#28) and the ClickPad pin
  count (#29), Rev B brings all 40 FPC lines to `J_KB` and the drive/sense/aux lines to
  `J_MAT` beside it (same for the ClickPad: `J_TP`/`J_PS2`); the assignment is jumpered.
  A later revision hard-routes the measured map.
- `route_pcb.py` + freerouting autoroute via Specctra DSN/SES; `./dev build pcb` chains
  generate → ERC → place → DRC → route → DRC → gerbers/drill/pos/BOM/PDF.
- `scripts/toolchain.env` gains `kicad/kicad` 9.0 and `freerouting` 2.3.0 by digest.
- Result: ERC 0 errors, and no DRC errors on the routed board. Freerouting abandons a
  few of the `J_KB`↔`J_MAT` connections while reporting success, so the build stops
  before the fab outputs; `out/pcb/` holds schematic.pdf and the BOM meanwhile. See #62.
  Base-cover hole positions are placeholders (#44).

### Hand-made enclosure (milestone M6, issues #46 #47 #48)

- `cad/export_plates.scad` projects the printed case's solids into the laser-cut bottom
  plate, the perimeter spacer ring (with USB notch) and the presentation-box foam insert;
  `./dev build cad` exports them as DXF alongside the STLs.
- `docs/enclosure/handmade.md`: E2 file/material/hardware tables and ordering flow, E3
  Hammond console step-by-step, E4 wood-frame cut list and sequence.
- `docs/presentation/label.svg` (60 × 40 mm case label) and
  `docs/presentation/quick-start-card.md` (A6, two sides); box dimensions and the insert
  derived in `docs/enclosure/presentation.md`.

### Printed enclosure (milestone M5, issues #40 #41 #42 #43)

- `cad/params.scad` is now the single home of every dimension; all parts include it.
  Values marked `MEASURE` wait for a real deck (#44).
- `cad/bottom_case.scad` prints as two halves (`half = "left"|"right"|"both"`): three
  dovetail floor tabs, a half-lap on the front and rear walls, two 3 mm pin holes, and
  the sled bosses that bridge the seam. Also gains the light-pipe aperture, foot
  recesses, tilt-foot screw holes, a reset-button hole and optional stiffening ribs.
- New parts: `perfboard_sled`, `usb_strain_relief` (two-piece clamp), `tilt_feet`,
  `zif_support_block` (keyboard/clickpad variants), `led_light_pipe`;
  `pico_mount_bracket` and `fpc_cable_guide` re-parameterised.
- `./dev build cad` renders all 11 STL jobs in the OpenSCAD image; `./dev test` renders
  the intersection of the two halves and fails on any shared volume
  (`cad/tests/joint_intersection.scad`, `scripts/check_cad_joint.py`).

### Toolchain pinning

- `scripts/toolchain.env` pins the three Docker images by digest and the `qmk_firmware`
  commit; `scripts/pull_toolchain.sh` pulls them and can `--save`/`--load` offline
  tarballs or `--refresh` the pins. `./dev install` clones QMK at exactly that commit.

### Developer commands and CI

- `./dev` entry point from the script-helpers `dev-cli` template (`scripts/cli.sh`,
  `scripts/_bootstrap.sh`), with this repo's verbs in `scripts/project.sh`: `install`
  (submodules, Docker images, shallow `qmk_firmware` checkout), `build`
  (`firmware|docs|tools|all`, toolchains in `qmkfm/qmk_cli` and `jekyll/jekyll`), `test`
  (pytest, byte-compile, `scripts/check_links.py`, shellcheck), `preflight`, `deploy`
  (UF2 → `RPI-RP2`, tool → `CIRCUITPY`), `devices`, `logs`, `clean`, `update`. Shims
  `./build ./test ./flash ./probe ./site`. Artifacts in `out/`.
- `scripts/script-helpers` submodule on branch `production` (0.22.0).
- `.github/workflows/ci.yml` via ci-helpers `ci.yml@production`: shellcheck, `./dev test`,
  `./dev install && ./dev build all`.

### Firmware (milestone M4, issues #34 #35 #36 #37)

- Configuration corrected as documented: `PS2_DRIVER = vendor` (RP2040 PIO), PS/2 pins
  DATA = GP21 / CLK = GP22 in `keyboard.json`, `BACKLIGHT_DRIVER = software`,
  `CUSTOM_MATRIX = lite`, `matrix_pins` removed, `matrix_size` 10 × 24.
- **Pointing driver is now `custom`, with `PS2_MOUSE_ENABLE = no`.** QMK's `ps2_mouse.c`
  only assembles 3-byte packets and would consume the same receive queue as the
  Synaptics decoder; the earlier plan's `POINTING_DEVICE_DRIVER = ps2` could never have
  carried the TrackPoint.
- New `matrix.c`: drive lines GP0–GP9, 74HC165 sense chain read over SPI0 (GP18 SCK,
  GP16 RX, GP17 latch). `halconf.h`/`mcuconf.h` enable SPI0 in ChibiOS.
- New `synaptics.c/.h`: reset, identify (0x47), capabilities, absolute + W mode, guest
  enable through the pass-through, 6-byte packet decode with resync, touch-to-delta,
  and a console-logged fallback to relative mode.
- New `trackpoint.c/.h`: decodes `W == 3` guest frames into the same HID report.
- `LAYOUT` is now generated by QMK from `keyboard.json` (the macro left the header, per
  QMK lint); NKRO default moved to `host.default.nkro`; `BACKLIGHT_BREATHING` dropped —
  the software PWM driver refuses it at compile time. The placeholder layout still maps
  the old 8 × 13 arrangement into the 10 × 24 matrix until #38 regenerates it.
- **The firmware builds**: `qmk compile -kb x240_pico -km default` → 72 KB UF2, zero
  lint warnings, verified in the `qmkfm/qmk_cli` container.

### Probing tools (milestone M2)

- `tools/matrix_probe/matrix_probe.py` reworked: two-pass procedure (`PASS = "A"`/`"B"`)
  so 40 FPC pads are covered with 26 GPIO, `NEVER_DRIVE_PADS` safety list, drive/sense
  terminology, Markdown table output that pastes into the pinout file, pass merging.
- `tools/ps2_sniffer/ps2_sniffer.py` gains host-to-device writes and a `synaptics` mode:
  reset, identify (magic 0x47), capability bits, absolute + W mode, guest enable through
  the pass-through, 6-byte packet decode, and an unambiguous `VERDICT:` on whether
  `W == 3` TrackPoint frames were seen.
- New `tools/shift_register_test/shift_register_test.py`: reads the 74HC165 chain over
  SPI0, `watch` and `walk` modes, names the wiring fault on a mismatch.
- New `tools/tests/` (pytest, 21 tests) covering the tools' protocol and formatting
  logic on the host; `tools/README.md` index.

### Design corrections (documentation pass, milestone M0)

These change what a builder would wire or configure. Each is recorded in the relevant doc
with its source.

- **USB-C upgrade wiring was wrong.** `README.md`, `PLAN.md` and the `usb_c_wiring.png`
  illustration said TP1 → D−, TP2 → D+. Per the Pico datasheet **TP1 = GND, TP2 = USB D−,
  TP3 = USB D+**; the old wiring shorts ground onto D−. Prose corrected everywhere; the
  image is kept as decoration and marked as not the wiring reference.
- **PS/2 driver.** `PS2_DRIVER = usart` is ATmega32u4-only and does not build on RP2040.
  The design now uses the RP2040 PIO driver (`vendor`), which requires clock = data + 1, so
  the pins become **DATA = GP21, CLK = GP22** (previously inverted). The "UART0" description
  of those pins was removed — GP21/GP22 is not a UART pair on the RP2040.
- **Backlight driver.** `BACKLIGHT_DRIVER = timer` was cited as the QMK #24470 workaround;
  the issue's workaround on RP2040 is `software`. Changed.
- **GPIO budget.** The 8 × 13 matrix assumption (21 GPIO) was unverified; the closest
  documented ThinkPad keyboard of this era is 17 × 9 (26 GPIO — every pin the Pico has).
  The design now reads sense lines through **three cascaded 74HC165 shift registers**
  (24 lines on 3 GPIO). Drive lines GP0–GP9; chain on GP16/GP17/GP18; eight GPIO spare.
- **TrackPoint added.** The X240 keyboard's TrackPoint was never mentioned. It is now a
  first-class feature, reached through the ClickPad's Synaptics pass-through port and
  decoded in firmware; GP19/GP20 reserved for a second PS/2 line if probing shows the
  TrackPoint is standalone.
- **Cost.** "$25–35 total" omitted the donor keyboard and palmrest. Honest totals are
  $90–150 depending on route; full tiers in `docs/hardware/bom-and-cost.md`.
- **Adafruit #1436** is a solder-pad adapter plate, not a ZIF breakout; the BOM now lists
  actual ZIF breakouts and says so.
- **Printability.** `cad/bottom_case.scad` is a single 309 × 210 mm part that exceeds every
  common print bed; the design moves to a split case (milestone M5), and a hand-made route
  with no printer is documented.

### Added

- A realistic product representation image of the completed standalone keyboard (`docs/images/x240_keyboard_completed.png`) to serve as the main product visual.
- `docs/hardware/` — components, BOM & cost, GPIO budget, 74HC165 sense chain, TrackPoint,
  backlight, PCB (Rev A vs Rev B).
- `docs/firmware/` — architecture, QMK configuration reference, pointing stack.
- `docs/enclosure/` — printed route, hand-made route (E1 base-cover reuse, E2 laser-cut,
  E3 Hammond console, E4 wood), mechanical integration, durability, assembly order and
  presentation box.
- `docs/references.md`, `docs/glossary.md`, section index pages with Jekyll front matter
  for the GitHub Pages site (configured in milestone M1).
- GitHub issue backlog: 51 issues across milestones M0–M8.

### Changed

- `README.md` and `docs/index.md` modified to feature the new product representation image.
- `README.md`, `BOM.md`, `PLAN.md`, `ASSEMBLY.md`, `hardware/wiring/wiring_diagram.md`,
  `hardware/pinout/*.md`, and the maintainer docs under `docs/` rewritten for the
  corrected design. `hardware/wiring/wiring_diagram.md` is now the single authoritative
  copy of the GPIO table.
- Pinout templates use drive/sense terminology and carry TrackPoint and chain columns.

### Earlier unreleased work

- Moved power-button handling out of the placeholder matrix keymap and into
  keyboard-level GP27 polling with the existing long-press guard.
- Added a full `docs/` documentation set covering project structure, design rules,
  coding instructions, and the build/test workflow.
- Added illustrated connector diagrams for the USB-C breakout and FPC ZIF connection.
- Expanded `.gitignore` for QMK build outputs, Python caches, OpenSCAD exports,
  local QMK checkouts, and transient hardware capture files.

## 0.1.0

- Initial project structure for the ThinkPad X240 USB keyboard controller.
- Added QMK keyboard definition, default keymap skeleton, firmware config, and
  RP2040 build rules.
- Added hardware pinout templates, wiring diagram, matrix probing tool,
  PS/2 sniffer, bill of materials, assembly guide, and OpenSCAD CAD sources.

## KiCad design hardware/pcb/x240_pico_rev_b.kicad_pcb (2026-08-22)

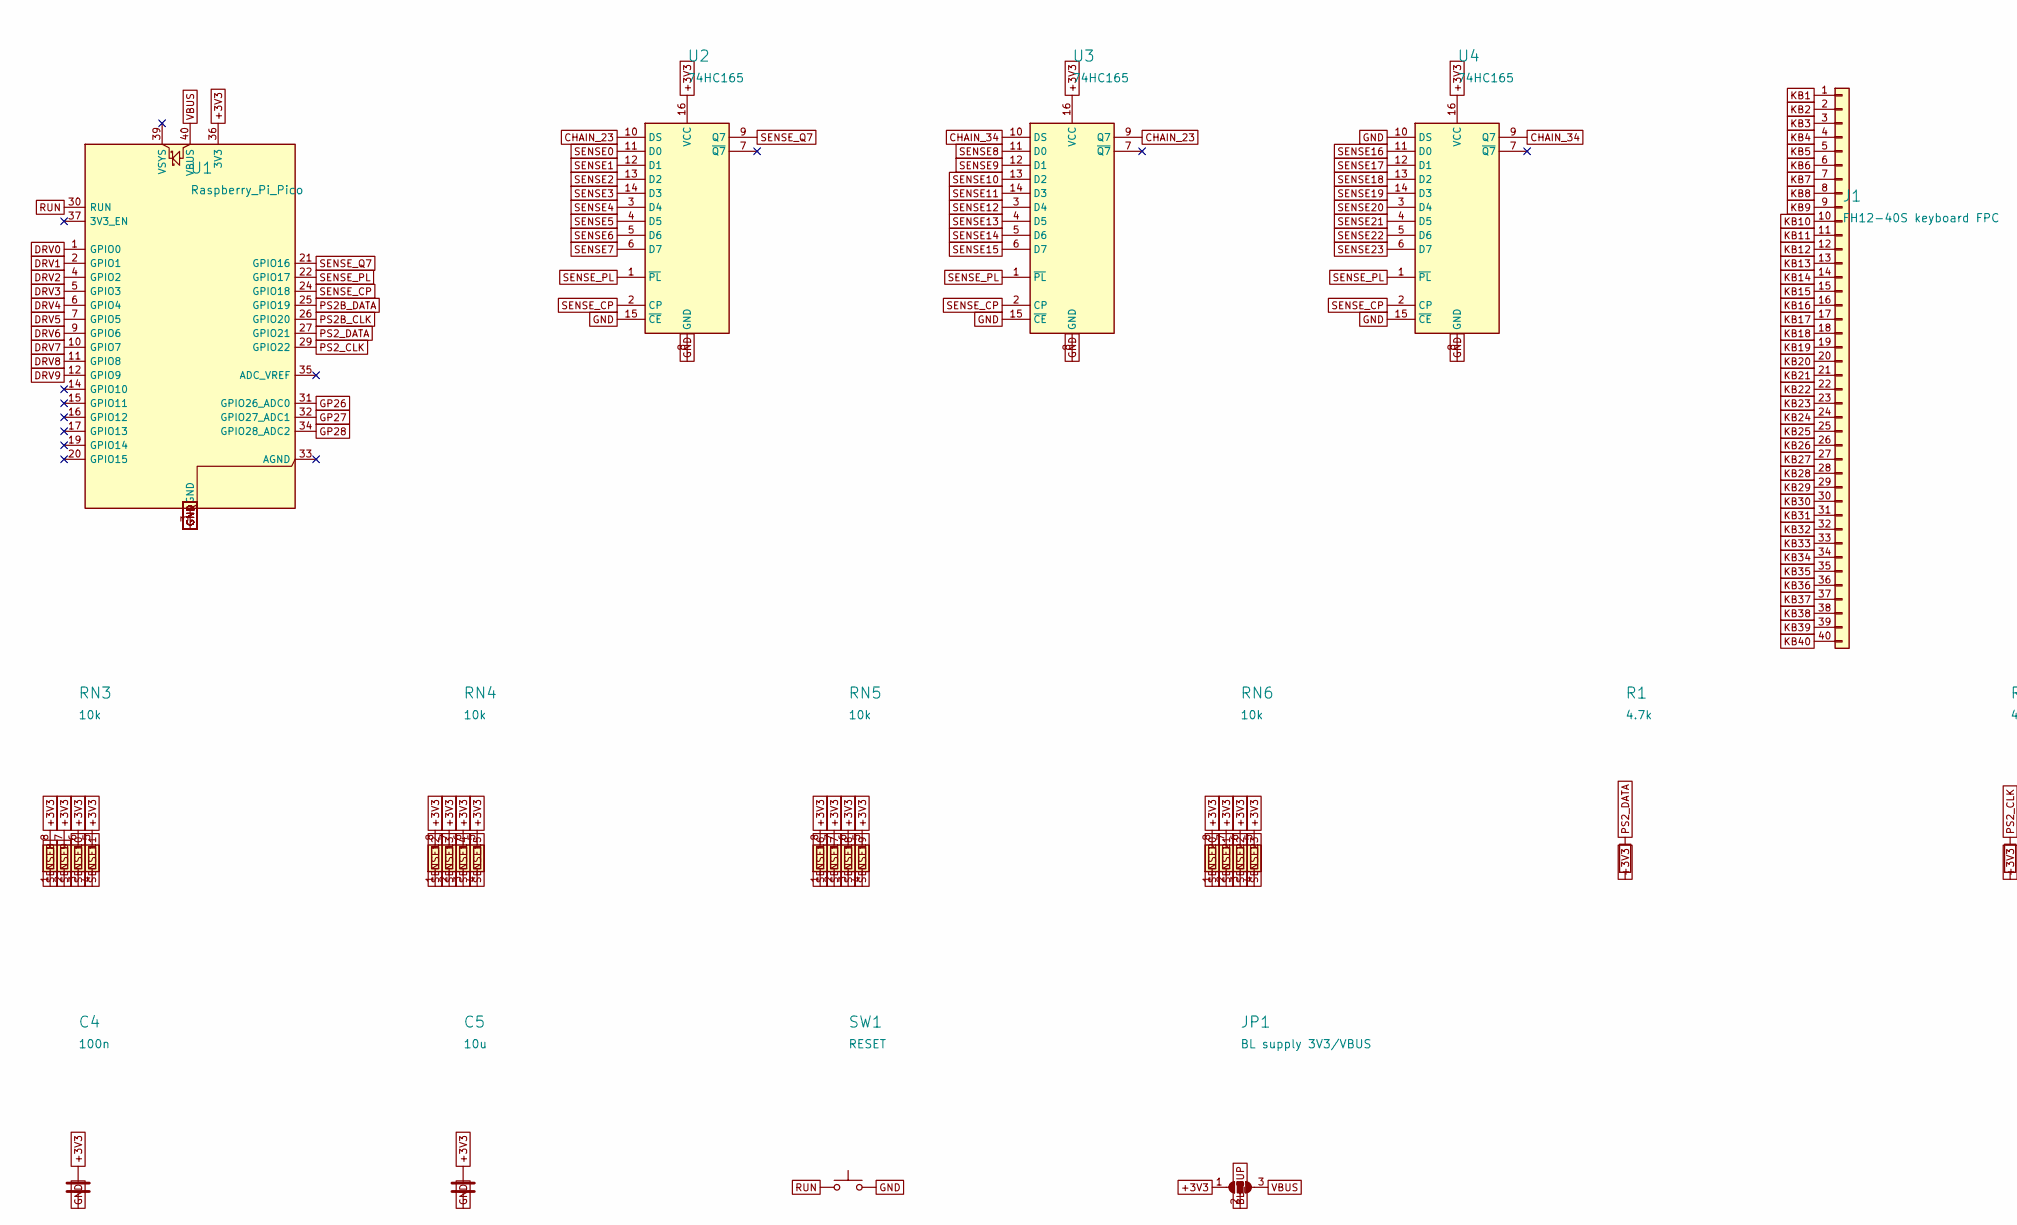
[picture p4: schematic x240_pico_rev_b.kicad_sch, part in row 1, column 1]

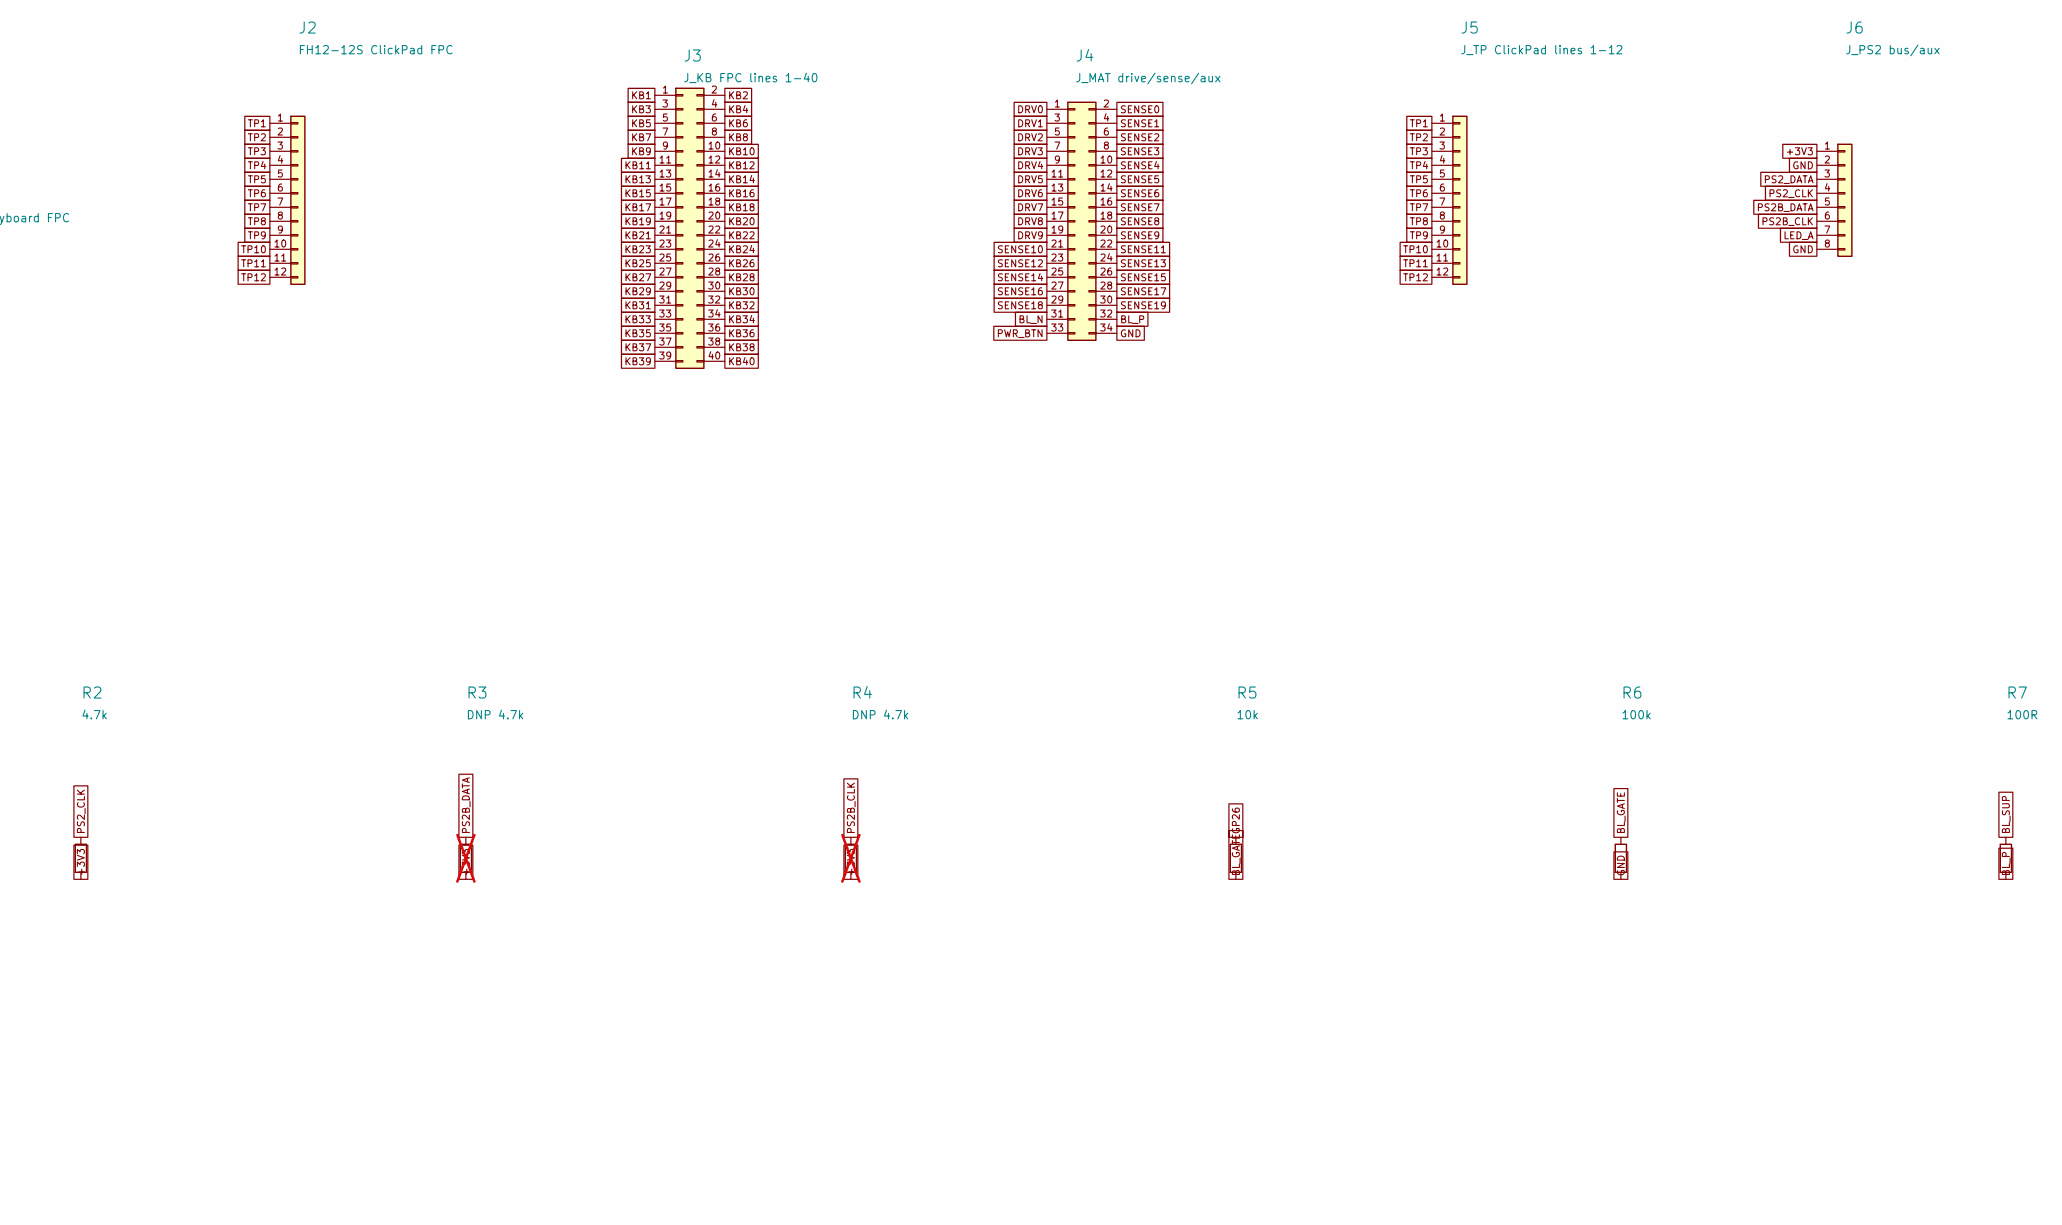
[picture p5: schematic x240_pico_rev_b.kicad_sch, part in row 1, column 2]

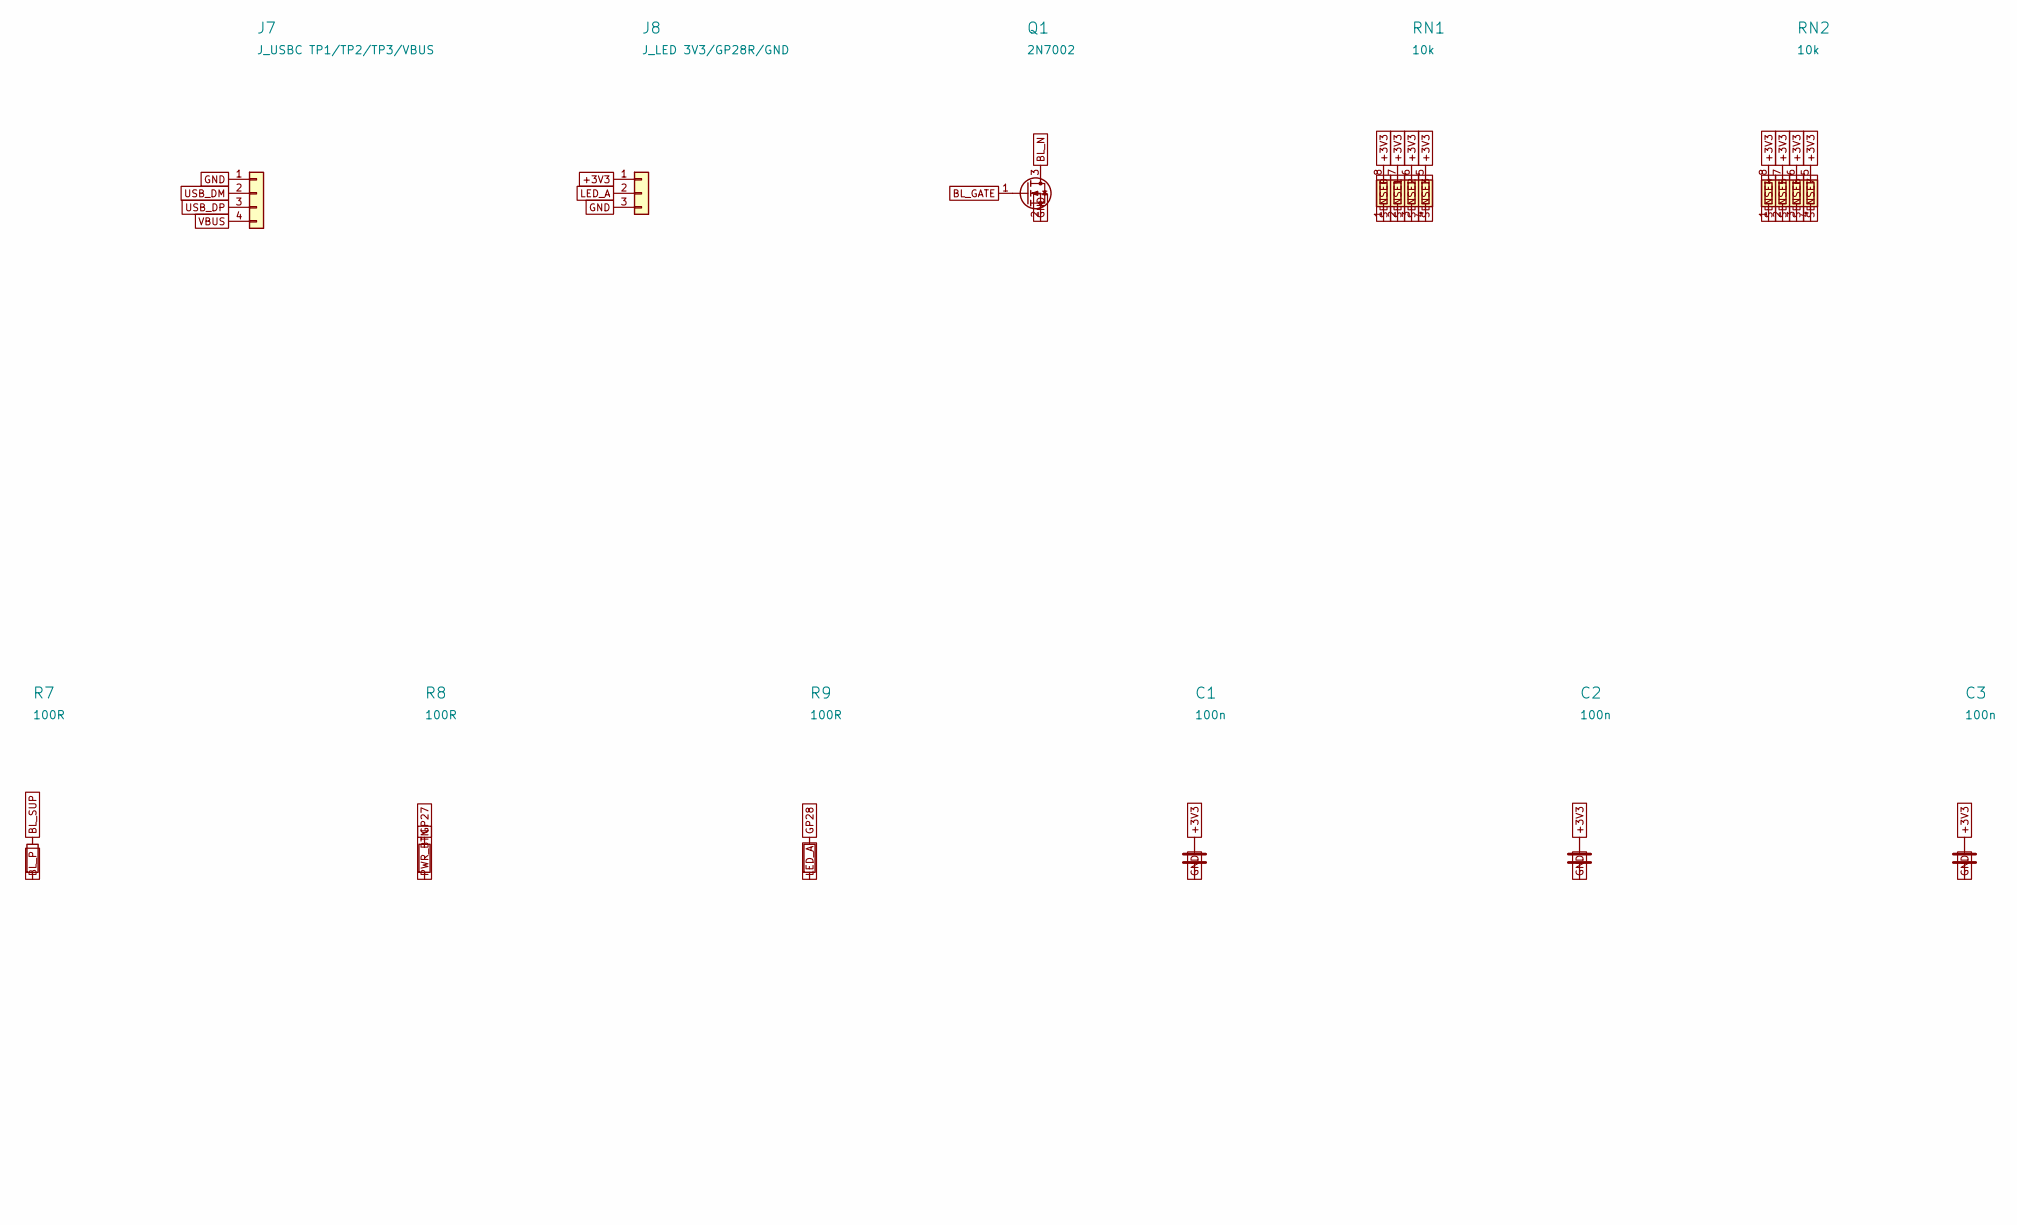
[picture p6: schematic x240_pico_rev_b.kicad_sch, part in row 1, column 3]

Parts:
C1, C2, C3, C4: 100n; C_0603_1608Metric
C5: 10u; C_0805_2012Metric
J1: FH12-40S keyboard FPC; Hirose_FH12-40S-0.5SH_1x40-1MP_P0.50mm_Horizontal
J2: FH12-12S ClickPad FPC; Hirose_FH12-12S-0.5SH_1x12-1MP_P0.50mm_Horizontal
J3: J_KB FPC lines 1-40; PinHeader_2x20_P2.54mm_Vertical
J4: J_MAT drive/sense/aux; PinHeader_2x17_P2.54mm_Vertical
J5: J_TP ClickPad lines 1-12; PinHeader_1x12_P2.54mm_Vertical
J6: J_PS2 bus/aux; PinHeader_1x08_P2.54mm_Vertical
J7: J_USBC TP1/TP2/TP3/VBUS; PinHeader_1x04_P2.54mm_Vertical
J8: J_LED 3V3/GP28R/GND; PinHeader_1x03_P2.54mm_Vertical
JP1: BL supply 3V3/VBUS; SolderJumper-3_P1.3mm_Open_RoundedPad1.0x1.5mm
Q1: 2N7002; SOT-23
R1, R2: 4.7k; R_0603_1608Metric
R3, R4: DNP 4.7k; R_0603_1608Metric; not fitted
R5: 10k; R_0603_1608Metric
R6: 100k; R_0603_1608Metric
R7, R8, R9: 100R; R_0603_1608Metric
RN1, RN2, RN3, RN4, RN5, RN6: 10k; R_Array_Convex_4x0603
SW1: RESET; SW_PUSH_6mm
U1: Raspberry_Pi_Pico; RaspberryPi_Pico_Common_THT
U2, U3, U4: 74HC165; TSSOP-16_4.4x5mm_P0.65mm

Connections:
+3V3: C1.1, C2.1, C3.1, C4.1, C5.1, J6.1, J8.1, JP1.1 (A), R1.2, R2.2, R3.2, R4.2, RN1.5 (R4.2), RN1.6 (R3.2), RN1.7 (R2.2), RN1.8 (R1.2), RN2.5 (R4.2), RN2.6 (R3.2), RN2.7 (R2.2), RN2.8 (R1.2), RN3.5 (R4.2), RN3.6 (R3.2), RN3.7 (R2.2), RN3.8 (R1.2), RN4.5 (R4.2), RN4.6 (R3.2), RN4.7 (R2.2), RN4.8 (R1.2), RN5.5 (R4.2), RN5.6 (R3.2), RN5.7 (R2.2), RN5.8 (R1.2), RN6.5 (R4.2), RN6.6 (R3.2), RN6.7 (R2.2), RN6.8 (R1.2), U1.36 (3V3), U2.16 (VCC), U3.16 (VCC), U4.16 (VCC)
BL_GATE: Q1.1 (G), R5.2, R6.1
BL_N: J4.31, Q1.3 (D)
BL_P: J4.32, R7.2
BL_SUP: JP1.2 (C), R7.1
CHAIN_23: U2.10 (DS), U3.9 (Q7)
CHAIN_34: U3.10 (DS), U4.9 (Q7)
DRV0: J4.1, U1.1 (GPIO0)
DRV1: J4.3, U1.2 (GPIO1)
DRV2: J4.5, U1.4 (GPIO2)
DRV3: J4.7, U1.5 (GPIO3)
DRV4: J4.9, U1.6 (GPIO4)
DRV5: J4.11, U1.7 (GPIO5)
DRV6: J4.13, U1.9 (GPIO6)
DRV7: J4.15, U1.10 (GPIO7)
DRV8: J4.17, U1.11 (GPIO8)
DRV9: J4.19, U1.12 (GPIO9)
GND: C1.2, C2.2, C3.2, C4.2, C5.2, J4.34, J6.2, J6.8, J7.1, J8.3, Q1.2 (S), R6.2, SW1.2, U1.3 (GND), U1.8 (GND), U1.13 (GND), U1.18 (GND), U1.23 (GND), U1.28 (GND), U1.38 (GND), U2.8 (GND), U2.15 (~CE), U3.8 (GND), U3.15 (~CE), U4.8 (GND), U4.10 (DS), U4.15 (~CE)
GP26: R5.1, U1.31 (GPIO26_ADC0)
GP27: R8.1, U1.32 (GPIO27_ADC1)
GP28: R9.1, U1.34 (GPIO28_ADC2)
KB1: J1.1, J3.1
KB2: J1.2, J3.2
KB3: J1.3, J3.3
KB4: J1.4, J3.4
KB5: J1.5, J3.5
KB6: J1.6, J3.6
KB7: J1.7, J3.7
KB8: J1.8, J3.8
KB9: J1.9, J3.9
KB10: J1.10, J3.10
KB11: J1.11, J3.11
KB12: J1.12, J3.12
KB13: J1.13, J3.13
KB14: J1.14, J3.14
KB15: J1.15, J3.15
KB16: J1.16, J3.16
KB17: J1.17, J3.17
KB18: J1.18, J3.18
KB19: J1.19, J3.19
KB20: J1.20, J3.20
KB21: J1.21, J3.21
KB22: J1.22, J3.22
KB23: J1.23, J3.23
KB24: J1.24, J3.24
KB25: J1.25, J3.25
KB26: J1.26, J3.26
KB27: J1.27, J3.27
KB28: J1.28, J3.28
KB29: J1.29, J3.29
KB30: J1.30, J3.30
KB31: J1.31, J3.31
KB32: J1.32, J3.32
KB33: J1.33, J3.33
KB34: J1.34, J3.34
KB35: J1.35, J3.35
KB36: J1.36, J3.36
KB37: J1.37, J3.37
KB38: J1.38, J3.38
KB39: J1.39, J3.39
KB40: J1.40, J3.40
LED_A: J6.7, J8.2, R9.2
PS2B_CLK: J6.6, R4.1, U1.26 (GPIO20)
PS2B_DATA: J6.5, R3.1, U1.25 (GPIO19)
PS2_CLK: J6.4, R2.1, U1.29 (GPIO22)
PS2_DATA: J6.3, R1.1, U1.27 (GPIO21)
PWR_BTN: J4.33, R8.2
RUN: SW1.1, U1.30 (RUN)
SENSE0: J4.2, RN1.1 (R1.1), U2.11 (D0)
SENSE1: J4.4, RN1.2 (R2.1), U2.12 (D1)
SENSE2: J4.6, RN1.3 (R3.1), U2.13 (D2)
SENSE3: J4.8, RN1.4 (R4.1), U2.14 (D3)
SENSE4: J4.10, RN2.1 (R1.1), U2.3 (D4)
SENSE5: J4.12, RN2.2 (R2.1), U2.4 (D5)
SENSE6: J4.14, RN2.3 (R3.1), U2.5 (D6)
SENSE7: J4.16, RN2.4 (R4.1), U2.6 (D7)
SENSE8: J4.18, RN3.1 (R1.1), U3.11 (D0)
SENSE9: J4.20, RN3.2 (R2.1), U3.12 (D1)
SENSE10: J4.21, RN3.3 (R3.1), U3.13 (D2)
SENSE11: J4.22, RN3.4 (R4.1), U3.14 (D3)
SENSE12: J4.23, RN4.1 (R1.1), U3.3 (D4)
SENSE13: J4.24, RN4.2 (R2.1), U3.4 (D5)
SENSE14: J4.25, RN4.3 (R3.1), U3.5 (D6)
SENSE15: J4.26, RN4.4 (R4.1), U3.6 (D7)
SENSE16: J4.27, RN5.1 (R1.1), U4.11 (D0)
SENSE17: J4.28, RN5.2 (R2.1), U4.12 (D1)
SENSE18: J4.29, RN5.3 (R3.1), U4.13 (D2)
SENSE19: J4.30, RN5.4 (R4.1), U4.14 (D3)
SENSE20: RN6.1 (R1.1), U4.3 (D4)
SENSE21: RN6.2 (R2.1), U4.4 (D5)
SENSE22: RN6.3 (R3.1), U4.5 (D6)
SENSE23: RN6.4 (R4.1), U4.6 (D7)
SENSE_CP: U1.24 (GPIO18), U2.2 (CP), U3.2 (CP), U4.2 (CP)
SENSE_PL: U1.22 (GPIO17), U2.1 (~PL), U3.1 (~PL), U4.1 (~PL)
SENSE_Q7: U1.21 (GPIO16), U2.9 (Q7)
TP1: J2.1, J5.1
TP2: J2.2, J5.2
TP3: J2.3, J5.3
TP4: J2.4, J5.4
TP5: J2.5, J5.5
TP6: J2.6, J5.6
TP7: J2.7, J5.7
TP8: J2.8, J5.8
TP9: J2.9, J5.9
TP10: J2.10, J5.10
TP11: J2.11, J5.11
TP12: J2.12, J5.12
USB_DM: J7.2
USB_DP: J7.3
VBUS: J7.4, JP1.3 (B), U1.40 (VBUS)

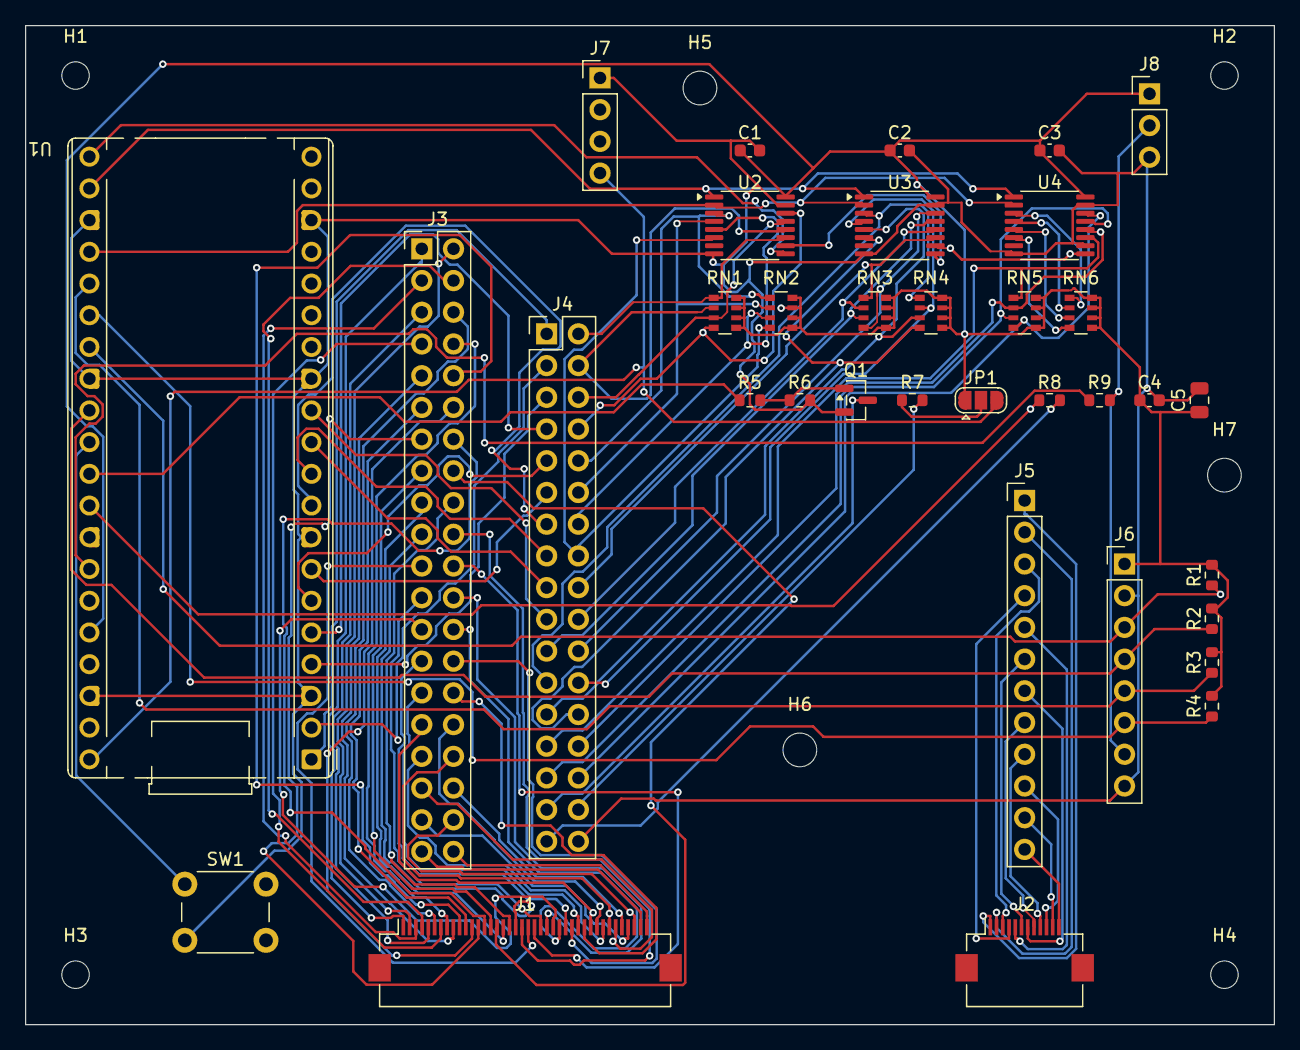
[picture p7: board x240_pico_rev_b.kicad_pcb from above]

Board: 2 copper layers, 100.0 x 80.0 mm, 42 parts (0 on the bottom side), 108 nets.

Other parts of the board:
H1, H2, H3, H4: MountingHole_2.2mm_M2
H5, H6, H7: MountingHole_2.7mm_M2.5

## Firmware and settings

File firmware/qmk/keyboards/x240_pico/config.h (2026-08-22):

#pragma once

/* ------------------------------------------------------------------------
 * Matrix — custom scan (matrix.c)
 *
 * Drive lines are pulled LOW one at a time; sense lines are read through
 * three cascaded 74HC165 shift registers over SPI0.  The 10 x 24 size is the
 * chain's capacity.  The real key -> (drive, sense) map comes from probing
 * (hardware/pinout/x240_keyboard_fpc_pinout.md) and regenerates the LAYOUT.
 * ------------------------------------------------------------------------ */
#define MATRIX_DRIVE_PINS { GP0, GP1, GP2, GP3, GP4, GP5, GP6, GP7, GP8, GP9 }

#define SENSE_PL_PIN   GP17          /* 74HC165 parallel load, active LOW   */
#define SENSE_CHAIN_BYTES 3          /* 3 chips x 8 inputs = 24 sense lines */

/* SPI0: SCK = GP18 -> 74HC165 CP, RX = GP16 <- U1 Q7.  No MOSI, no chip select. */
#define SPI_DRIVER   SPID0
#define SPI_SCK_PIN  GP18
#define SPI_MISO_PIN GP16
#define SPI_MOSI_PIN NO_PIN
#define SENSE_SPI_DIVISOR 16         /* ~7.8 MHz from the 125 MHz peripheral clock */

#define DEBOUNCE 5
#define MATRIX_IO_DELAY 30           /* us after a drive line goes LOW, before latching */

/* ------------------------------------------------------------------------
 * PS/2 — RP2040 PIO host.  Pins come from keyboard.json ("ps2" block):
 * DATA = GP21, CLK = GP22.  The PIO driver requires CLK = DATA + 1.
 * Both lines need 4.7 kOhm pull-ups to 3V3 on the board.
 * Pointing is synaptics.c (custom driver); see rules.mk for why.
 * ------------------------------------------------------------------------ */
#define POINTING_DEVICE_TASK_THROTTLE_MS 1

/* Synaptics absolute units are ~0..6143 on X, ~0..5119 on Y. */
#define SYN_TOUCHPAD_DIVISOR   8     /* absolute units per HID count            */
#define SYN_TOUCH_THRESHOLD    30    /* Z above this = finger down               */
#define SYN_TRACKPOINT_MULT    1     /* guest packet counts per HID count        */
#define SYN_TRACKPOINT_DEADZONE 0    /* |delta| <= this is dropped (drift guard) */
/* #define SYN_INVERT_Y */           /* uncomment if the cursor moves the wrong way vertically */

/* ------------------------------------------------------------------------
 * Backlight — software PWM on GP26 -> MOSFET gate (QMK #24470 workaround)
 * ------------------------------------------------------------------------ */
#define BACKLIGHT_PIN     GP26
#define BACKLIGHT_LEVELS  5
/* No BACKLIGHT_BREATHING: the software PWM driver refuses it at compile time
 * ("Backlight breathing is not available for software PWM").  Levels only. */

/* Power button — GP27, active LOW, internal pull-up; long-press guard in x240_pico.c */
#define POWER_BUTTON_PIN GP27
#define POWER_BUTTON_HOLD_MS 500

/* Touchpad indicator LED — GP28 HIGH = on */
#define TOUCHPAD_LED_PIN GP28

/* NKRO default is host.default.nkro in keyboard.json */

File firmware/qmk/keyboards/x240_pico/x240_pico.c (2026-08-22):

#include "x240_pico.h"
#include "quantum.h"

static bool power_button_pressed = false;
static uint16_t power_button_timer = 0;

/* ---------------------------------------------------------------------------
 * Hardware initialization
 *
 * The X240 ClickPad has a small indicator LED. We light it whenever the
 * pointing device is active (i.e., at startup and always-on during use).
 * To disable the touchpad temporarily, a user-defined keycode could call
 * pointing_device_set_status() and toggle the LED here.
 *
 * The X240 power button is wired as a dedicated active-LOW GPIO on GP27. It is
 * not part of the keyboard matrix, so matrix_scan_kb() polls it separately.
 * --------------------------------------------------------------------------- */
void keyboard_post_init_kb(void) {
    gpio_set_pin_output(TOUCHPAD_LED_PIN);
    gpio_write_pin_high(TOUCHPAD_LED_PIN);   /* LED on = touchpad active */

    gpio_set_pin_input_high(POWER_BUTTON_PIN);

    keyboard_post_init_user();
}

/* ---------------------------------------------------------------------------
 * Dedicated power button handling
 *
 * A short press is ignored to prevent accidental suspend/power-off. A release
 * after POWER_BUTTON_HOLD_MS sends a standard System Power HID event.
 * --------------------------------------------------------------------------- */
void matrix_scan_kb(void) {
    bool pressed = !gpio_read_pin(POWER_BUTTON_PIN);

    if (pressed && !power_button_pressed) {
        power_button_pressed = true;
        power_button_timer = timer_read();
    } else if (!pressed && power_button_pressed) {
        power_button_pressed = false;
        if (timer_elapsed(power_button_timer) >= POWER_BUTTON_HOLD_MS) {
            tap_code(KC_SYSTEM_POWER);
        }
    }

    matrix_scan_user();
}

/* ---------------------------------------------------------------------------
 * Pointing device — the ClickPad and TrackPoint are merged inside the custom
 * driver (synaptics.c / trackpoint.c); nothing to do here but pass through.
 * Per-axis inversion is SYN_INVERT_Y in config.h, so it is applied once.
 * --------------------------------------------------------------------------- */
report_mouse_t pointing_device_task_kb(report_mouse_t mouse_report) {
    return pointing_device_task_user(mouse_report);
}

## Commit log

2026-04-07 Initial public x240-kbd project
    [bottom_case.scad, fpc_cable_guide.scad, pico_mount_bracket.scad]
2026-04-07 fix: poll dedicated power button input
    [config.h, x240_pico.c]
2026-08-22 docs: add connector wiring diagrams for USB-C and FPC ZIF breakout
2026-08-22 docs(hardware): component reference, priced BOM, GPIO budget, sense chain, TrackPoint, backlight, PCB
    Every part gets a datasheet and product link. Records the research findings:
    the Pico's 26 GPIO do not cover a documented 17x9 ThinkPad matrix, so sense
    lines move to three cascaded 74HC165; the TrackPoint reaches the host through
    the ClickPad's Synaptics pass-through port; the RP2040 backlight workaround for
    QMK #24470 is the software driver; Adafruit 1436 is a solder-pad plate, not a
    ZIF breakout. Tiered BOM replaces the $25-35 figure that omitted donor parts.
2026-08-22 docs(firmware): architecture map, QMK configuration reference, pointing stack
    Documents the intended file layout (matrix.c, synaptics.c, trackpoint.c) and
    every rules.mk/config.h/keyboard.json setting with its upstream reference.
    Corrects PS2_DRIVER to vendor (RP2040 PIO; usart is ATmega32u4-only), the
    PS/2 pin order (clock = data + 1, so DATA=GP21 CLK=GP22), and the backlight
    driver; removes the claim that GP21/GP22 are UART0.
2026-08-22 docs(enclosure): printed and hand-made routes, integration, durability, presentation
    The single 309x210 mm case exceeds every common print bed, so the printed
    route becomes a split case. Adds a no-printer route with four variants,
    recommending reuse of the original X240 base cover. Covers stack heights,
    routing, heat, EMI, FPC fatigue, strain relief, assembly order and a box.
2026-08-22 docs: correct design claims in README, PLAN, ASSEMBLY, wiring and pinout templates
    USB-C wiring: Pico test pads are TP1=GND, TP2=D-, TP3=D+; the previous
    TP1=D-/TP2=D+ shorts ground onto D-. The render usb_c_wiring.png is kept as
    illustration only. hardware/wiring/wiring_diagram.md becomes the single
    authoritative GPIO table. Pinout templates use drive/sense terminology and
    carry TrackPoint and chain columns; probing gains the pass-through check that
    decides the TrackPoint route. CHANGELOG records every correction.
2026-08-22 docs: authored SVG schematics replace the renders as wiring reference
    Seven diffable diagrams under docs/images: USB-C test-pad wiring (TP1=GND,
    TP2=D-, TP3=D+), 74HC165 sense chain, backlight MOSFET switch, PS/2 bus with
    TrackPoint pass-through, FPC orientation and pin 1, internal layout with the
    vertical stack, and the signal-flow block diagram. Linked from the pages that
    describe each circuit. The two AI renders stay as illustration only.
2026-08-22 site: Jekyll just-the-docs configuration and landing page
    /docs is the Pages source: remote theme, search, aux links, maintainer pages
    excluded. Landing page states the build status, cost, the two corrections a
    builder must know, and links into each section. Gemfile is for local preview
    only; Pages uses its own gem set.
2026-08-22 tools: two-pass matrix probe, Synaptics pass-through sniffer, 74HC165 self-test
    matrix_probe: 40 breakout pads on 26 GPIO via passes A (1-26) and B (15-40)
    with a shared overlap; NEVER_DRIVE_PADS guards identified power pins; output
    is a Markdown table in drive/sense terms plus a merge helper.
    ps2_sniffer: adds a bit-banged host-to-device write path and a synaptics mode
    that resets, identifies (0x47), reads capability bits, enables absolute + W
    mode, enables the guest through the pass-through, decodes 6-byte packets and
    prints a VERDICT line on whether W == 3 TrackPoint frames were seen. That
    verdict is the measurement that fixes the TrackPoint route.
    shift_register_test: SPI0 read of the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
    [matrix_probe.py, ps2_sniffer.py, shift_register_test.py]
2026-08-22 firmware: custom 74HC165 matrix, Synaptics pass-through pointing driver, config corrections
    Builds: qmk compile -kb x240_pico -km default in qmkfm/qmk_cli, zero lint
    warnings, 72 KB UF2.
    - rules.mk: CUSTOM_MATRIX = lite, POINTING_DEVICE_DRIVER = custom,
    SPI_DRIVER_REQUIRED, BACKLIGHT_DRIVER = software, CONSOLE_ENABLE for
    bring-up. keyboard.json: ps2 block (vendor/PIO, DATA GP21, CLK GP22,
    mouse disabled), matrix_size 10x24, host.default.nkro, bootmagic key;
    matrix_pins and diode_direction removed; LAYOUT generated from json.
    - matrix.c: drive lines GP0-GP9, three cascaded 74HC165 read over SPI0
    (GP18 SCK, GP16 RX, GP17 latch); halconf.h/mcuconf.h switch SPI0 on.
    - synaptics.c: cus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
    [config.h, matrix.c]
2026-08-22 dev: ./dev command surface from the script-helpers template, CI via ci-helpers
    scripts/cli.sh and _bootstrap.sh are the dev-cli template (unedited);
    scripts/project.sh gives the verbs their meaning: install (submodules,
    docker images, shallow qmk_firmware checkout), build firmware|docs|tools|all
    in the qmkfm/qmk_cli and jekyll/jekyll containers, test (pytest,
    byte-compile, scripts/check_links.py, shellcheck), preflight, deploy (UF2 to
    RPI-RP2, tool to CIRCUITPY), devices, logs, clean, update. Shims ./build
    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
2026-08-22 docs: ./dev workflow, custom pointing driver decision, firmware now builds
    README, build-and-test, project-structure, AGENTS, tools/README and the
    firmware pages describe the ./dev verbs and the POINTING_DEVICE_DRIVER =
    custom decision. Backlight breathing removed from every page that promised
    it. CHANGELOG records all of it.
2026-08-22 dev: fail the docs build on jekyll errors; fix shim and diagram text
    Review follow-ups on #58. The Jekyll pipeline now runs with pipefail and
    empties /out inside the container first, so a stale index.html cannot pass
    for a successful build. The ./site shim names out/site, and the
    pointing-stack diagram shows the merge happening inside the custom driver,
    with pointing_device_task_kb as a pass-through.
2026-08-22 docs: architecture diagram and hooks table match the custom pointing driver
    The signal-flow diagram and the hooks table still placed the ClickPad +
    TrackPoint merge in pointing_device_task_kb; it happens inside
    pointing_device_driver_get_report, and the kb hook is a pass-through.
    Copilot flagged these as suppressed comments on #58.
2026-08-22 docs: config.h tables match the real defines; link checker prunes big trees
    Copilot's second pass on #58: the qmk-configuration and architecture tables
    named SENSE_CP_PIN, SENSE_Q7_PIN, SENSE_CHAIN_BITS and FORCE_NKRO, none of
    which exist; they now list SENSE_PL_PIN, SENSE_CHAIN_BYTES, the SPI pin
    defines and host.default.nkro. check_links.py walks with directory pruning
    (qmk_firmware, scripts/script-helpers, out, _site) instead of globbing the
    whole tree, and closes files explicitly.
2026-08-22 fix: ./probe help flags and inclusive TrackPoint deadzone
    ./probe -h / --help / help now reach the ./dev usage instead of being taken
    as a tool name. The TrackPoint deadzone compares inclusively so that
    SYN_TRACKPOINT_DEADZONE = 1 drops +/-1 as the docs say. From Copilot's third
    pass on #58.
2026-08-22 cad: params.scad single source, split bottom case, sled, strain relief, feet, ZIF block, light pipe
    Every dimension lives in params.scad (MEASURE-marked values wait for a real
    deck, #44). bottom_case.scad prints as two halves that fit a 220 mm bed:
    three dovetail floor tabs, a half-lap on the front and rear walls, two pin
    holes, and the sled bosses that bridge the seam; also the light-pipe
    aperture, foot recesses, tilt-foot holes, a reset hole and optional ribs.
    New parts: perfboard_sled, usb_strain_relief (two-piece clamp), tilt_feet,
    zif_support_block (keyboard/clickpad), led_light_pipe; pico_mount_bracket
    and fpc_cable_guide re-parameterised. cad/tests/joint_intersection.scad
    renders the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
    [bottom_case.scad, fpc_cable_guide.scad, joint_intersection.scad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]
2026-08-22 dev: pin the toolchain by digest and commit; build cad; CAD joint test
    scripts/toolchain.env pins qmkfm/qmk_cli, jekyll/jekyll and openscad/openscad
    by digest and qmk_firmware to commit 3f26a92. scripts/pull_toolchain.sh pulls
    them, can save/load offline tarballs and --refresh the pins. ./dev install
    clones QMK at exactly that commit (verified from an empty directory through
    to a firmware build); ./dev update moves an existing checkout to it.
    ./dev build cad renders every part to out/cad; ./dev test now renders the
    split-joint intersection and fails on any shared volume.
2026-08-22 docs: printed enclosure as built, toolchain pinning, base-cover part labels
    printed.md describes the tab/half-lap/pin joint and the joint test;
    build-and-test, project-structure and README cover toolchain.env and
    ./dev build cad. The X240 base cover is also labelled SCB0G39215 /
    AP0SX000I00 on the moulding; those numbers are added beside the FRUs.
2026-08-22 cad: laser-cut plates and box insert projected from the printed case (DXF)
    export_plates.scad derives the bottom plate (every hole as a through-hole),
    the perimeter spacer ring with the USB notch, and the presentation-box foam
    insert from the same solids as bottom_case.scad via projection(), so the
    hand-made route cannot drift from the printed one. ./dev build cad exports
    them as DXF next to the STLs.
    [export_plates.scad]
2026-08-22 docs: E2/E3/E4 hand-made enclosure details, label and quick-start card
    handmade.md gains the DXF file/material/hardware tables and ordering flow
    for the laser-cut sandwich, a step-by-step for the Hammond 515 console, and
    a cut list and sequence for the wood frame. presentation.md derives the box
    from the deck and points at docs/presentation/label.svg (60 x 40 mm) and the
    A6 quick-start card.
2026-08-22 pcb: Rev B KiCad project generated from a netlist model, autorouted, DRC clean
    netlist_model.py holds the 42 parts, their KiCad 9 library names and 110
    nets. gen_schematic.py writes the schematic with the real library symbols
    embedded (derived symbols flattened) and one global label per connected pin;
    gen_pcb.py builds the board with pcbnew: footprints placed by courtyard
    centre, every pad netted, 100 x 80 mm outline, sled and base-cover hole
    patterns, 2-layer rules (0.20/0.15 mm targets, 0.127 mm minimums).
    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
    [x240_pico_rev_b.kicad_pcb, x240_pico_rev_b.kicad_sch]
2026-08-22 dev: ./dev build pcb; pin kicad and freerouting images
    build pcb chains generate -> ERC -> place -> DRC -> freerouting (100 passes,
    X240_ROUTE_PASSES / X240_SKIP_ROUTE) -> import + pour -> DRC -> gerbers,
    drill, position, BOM and PDFs into out/pcb. toolchain.env pins kicad/kicad
    9.0 and freerouting 2.3.0 by digest; generated KiCad intermediates ignored.
2026-08-22 docs: Rev B generated-board pipeline, jumpered design decision, results
2026-08-22 dev: run the KiCad container as the invoking user
    The kicad/kicad image has its own uid 1000; on the CI runner the checkout
    belongs to uid 1001 and gen_schematic.py could not write into it. The
    container now runs as the caller with HOME and XDG_CONFIG_HOME in /tmp.
2026-08-22 dev: X240_SKIP_ROUTE reports DRC instead of failing on the unrouted board
2026-08-22 pcb: deterministic schematic UUIDs so regeneration is a no-op diff
    [x240_pico_rev_b.kicad_sch]
2026-08-22 dev: re-route until DRC reports no open connections
    Freerouting is nondeterministic and the SES round-trip occasionally drops
    a connection (CI saw 10 open after a routing pass that freerouting called
    complete). build pcb now loops export -> route -> import -> DRC up to
    three times, re-routing only what is still open, and prints the open pairs
    when a round falls short. Board re-routed by this run.
    [x240_pico_rev_b.kicad_pcb]
2026-08-22 dev: placement DRC and exhausted routing now fail the build; docs match the verb
    Copilot review on #61. The placement DRC step's fallback returned 0 whenever
    violations were found; it now parses the JSON report and fails on any
    error-severity violation (open connections are expected on an unrouted
    board). If connections are still open after the third routing round the
    build stops instead of exporting fab files. Docs: X240_ROUTE_PASSES
    defaults to 100, and the BOM is bom.csv, not an interactive HTML BOM.
    [x240_pico_rev_b.kicad_pcb]
2026-08-22 pcb: cleaner model, guarded route_pcb CLI, generator stderr kept
    Copilot's second pass on #61. netlist_model.py assigns the J_MAT sense pins
    in one place instead of a placeholder expression that was rebuilt later, and
    the SENSE20-23 comment says what the code does (not headered in Rev B); the
    net list is unchanged (verified equal). route_pcb.py validates its arguments
    and its usage names every subcommand. build pcb keeps gen_pcb/route_pcb
    stderr (minus the debug-build assert noise) so a failure says why.
2026-08-22 dev: generator steps return the Python exit status, not grep's
    The gen_pcb / DSN export / SES import steps piped Python through grep -v
    inside sh -c, which masked generator failures and could fail a good run
    when grep filtered everything. A wrapper now logs the step, filters the
    assert noise from the log afterwards, and exits with the Python status.
2026-08-22 dev: export steps fail the build; artifacts verified before success
    Copilot's fourth pass on #61. The schematic PDF/netlist/BOM export and the
    gerber/drill/pos/pdf/zip export now stop the build on a non-zero status,
    bom.csv is checked for its quantity column, and every promised artifact
    must exist before print_success.
2026-08-22 dev: portable grep, DRC errors stop the routing loop, best-effort version banner
    Copilot's fifth pass on #61. The BOM quantity check uses grep -E instead of
    a GNU-only alternation; each routing round now fails on any error-severity
    DRC violation before considering another round, since a short or clearance
    error is not something re-routing fixes; pull_toolchain.sh --verify no longer
    aborts under pipefail if freerouting's version banner changes.
2026-08-22 pcb/dev: drop dead parent-symbol logic; container wrappers take one command string
    Copilot's sixth pass on #61 (suppressed items). embedded_symbol() has
    flattened derived symbols since the ERC fix, so the parent return value and
    the caller's parent handling were dead; removed, schematic output unchanged.
    x240_qmk, x240_jekyll, x240_kicad and x240_kicad_py pass "$1" to sh -c
    instead of "$*".
2026-08-22 pcb: idempotent GND pour, and a clearance margin for the router
    The re-route loop runs route_pcb.py import against the board the previous
    round saved, which already carries a pour, so add_ground_pour() stacked a
    second geometrically identical B.Cu GND zone at the same priority and DRC
    stopped the build with zones_intersect. The new zone is now built first and
    the stale ones dropped afterwards -- pcbnew's SWIG bindings mistype objects
    constructed after a BOARD::Remove(), so ZONE.Outline() would come back as a
    bare SwigPyObject -- and the pour is stripped before the DSN export as well,
    so every round hands the router the same board round 1 saw.
    Freerouting aimed exactly at the 0.15 mm netclas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
2026-08-22 pcb/dev: route once, single-threaded, and gate on KiCad's DRC
    Freerouting's optimizer runs on a pool of (logical processors - 1) threads by
    default, so the same board routes differently on every machine: CI stranded
    ten connections where a local run of the same commit stranded five. Pinned to
    one thread, two runs of the same DSN produce byte-identical sessions.
    That makes the three-round retry loop dead code, and it was never earning its
    keep: re-routing exports the previous attempt's tracks as protected wiring
    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
